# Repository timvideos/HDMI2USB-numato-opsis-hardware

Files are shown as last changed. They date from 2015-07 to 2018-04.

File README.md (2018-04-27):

The <a href="http://hdmi2usb.tv/numato-opsis">Numato Opsis</a>, the first open hardware for the
<a href="http://hdmi2usb.tv">HDMI2USB firmware</a>,
<a href="https://numato.com/product/numato-opsis-fpga-based-open-video-platform">can now be ordered
From Numato Labs
</a>

## Opsis Board - A open source HDMI2USB board

The [Numato](http://numato.com) Opsis board is the first
[HDMI2USB](http://hdmi2usb.tv) production board developed in conjugation with
the [TimVideos.us](http://code.timvideos.us) project. 

It's features include;
 * 2 x HDMI input ports,
 * 2 x HDMI output ports,
 * DisplayPort input and output ports,
 * 128Mbit DDR3-1600 ram,
 * Gigabit Ethernet with MAC address EEPROM,
 * Micro SD card,
 * Cypress FX2 for USB device functionality,
 * ULPI for USB OTG functionality,
 * Quad speed SPI flash.

Sample code for the Opsis can be found at https://github.com/timvideos/HDMI2USB-numato-opsis-sample-code

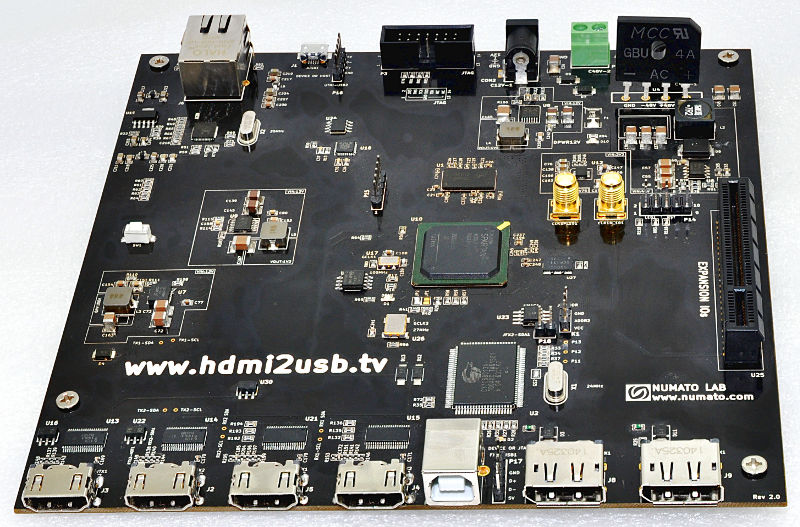
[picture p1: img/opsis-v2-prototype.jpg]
Opsis V2 Prototype Picture


## Editing

The design in this repository was made using [KiCad](http://www.kicad-pcb.org/)
version **2013-07-07 BZR 4022**
([the version in Ubuntu Trusty](http://packages.ubuntu.com/trusty/kicad)).

## License

Opsis Board by Numato Systems Pvt. Ltd

The Numato HDMI2USB board is licensed under a
Creative Commons Attribution-ShareAlike 4.0 International License.

You should have received a copy of the license along with this
work. If not, see <http://creativecommons.org/licenses/by-sa/4.0/>.



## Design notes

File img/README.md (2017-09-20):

This directory is only for images needed for this repo.

Detailed pictures of the Opsis board can be found in the [Opsis Developer Documentation](https://opsis.hdmi2usb.tv) the source of these images can be found in the [GitHub Repo for the Developer Docs](https://github.com/timvideos/HDMI2USB-numato-opsis-docs/tree/master/img).

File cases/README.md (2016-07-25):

This directory contains designs for mounting the Numato Opsis in cases.

This git repository is the master but the designs can also be found on
[Thingiverse](http://www.thingiverse.com/groups/timvideos/things).

 * `layout` - Designs showing the port size and locations to enable easy case construction.
 * `layout/front.svg` - Front of the board containing the HDMI, USB-B and DisplayPort connectors.
 * (TODO) `layout/back.svg` - Back of the board containing the Ethernet, Micro USB and power connectors.
 * (TODO) `layout/side.svg` - Side of the board containing the MicroSD slot.

 * `io-shield` - IO shields designed to fit ready made cases.

 * `io-shield/atx` - Fits an standard ATX case.

 * `io-shield/inset-thin` - Fits the
   [Inset Technologies "Thin Mini-ITX Computer Case"](http://amzn.to/1Okez89)
   when used with
   [#6-32 to M3 Metal Standoffs](http://amzn.to/2anqXwz).

 * `(.*)-mouse-ears.stl` - Same as `\1.stl`, but with 'mouse-ears' to aid 3d printing.

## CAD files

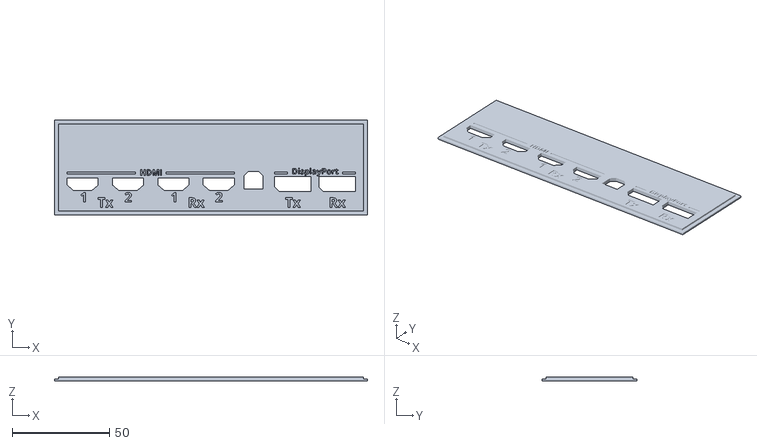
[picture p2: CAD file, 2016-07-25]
cases/io-shield/atx/atx.stl
161.0 x 49.0 x 2.00

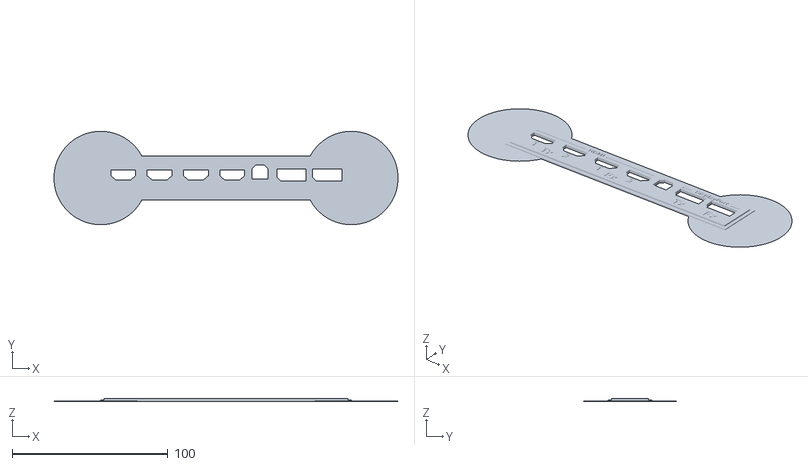
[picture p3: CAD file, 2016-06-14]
cases/io-shield/inset-thin/inset-thin-mouse-ears.stl
220.9 x 60.0 x 2.00

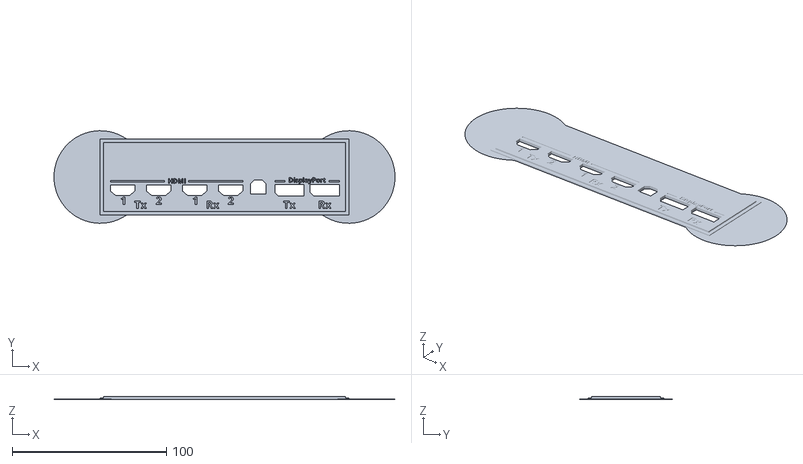
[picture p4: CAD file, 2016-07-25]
cases/io-shield/atx/atx-mouse-ears.stl
220.9 x 60.0 x 2.00

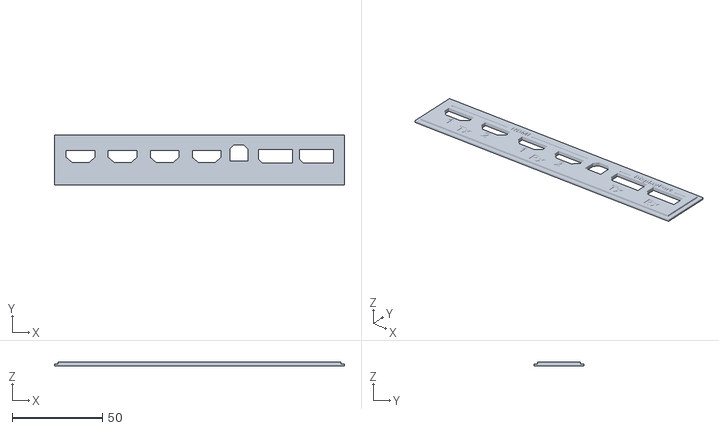
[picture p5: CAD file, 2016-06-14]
cases/io-shield/inset-thin/inset-thin.stl
161.0 x 28.0 x 2.00

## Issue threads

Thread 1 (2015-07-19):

Create code for the FX2 to act as a USB-UART

mithro, 2015-07-19:
_From @mithro on July 17, 2015 7:30_

The FX2 should be loadable with firmware which makes it appear like a CDC-ACM serial port and is connected to the FPGA.

The FX2 has its two hardware UARTs connected to the FPGA;
 * Two hardware UARTs
   * Port 0
     * RX - Cypress (Pin 41) -> FPGA (Pin **P18** / IO_L71N_1)      -- Incorrectly labeled CY_RXD1
     * TX - FPGA (Pin **T17** / IO_L72N_1) -> Cypress (Pin 40)      -- Incorrectly labeled CY_TXD1
   * Port 1
     * RX - Cypress (Pin 43) -> FPGA (Pin **P17** / IO_L71P_1)      -- Incorrectly labeled CY_RXD0
     * TX - FPGA (Pin **R17** / IO_L72P_1) -> Cypress (Pin 42)      -- Incorrectly labeled CY_TXD0

_Copied from original issue: mithro/numato-opsis-sample-code#1_

mithro, 2015-07-19:
https://github.com/timvideos/HDMI2USB-numato-opsis-sample-code/issues/1

Closed 2015-07-19.

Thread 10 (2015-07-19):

PCB text should use hdmi2usb.tv rather than www.hdmi2usb.tv

mithro, 2015-07-19:
Ported from http://redmine.numato.in/issues/1850

Closed 2015-08-26.

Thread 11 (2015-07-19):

Silkscreen for P15 should include information about each pin

mithro, 2015-07-19:
Pin 1 - VCC3V3
Pin 2 - VCC1V5
Pin 3 - IO 0
Pin 4 - IO 1
Pin 5 - GND

Ported from http://redmine.numato.in/issues/1988

Closed 2015-08-26.

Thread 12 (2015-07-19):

VTTREF0 and VTTREF not connected

mithro, 2015-07-19:
This is caused because we ended up with two nets, VTTREF0 and VVTREF, hence the check in the PCB didn't show they where connected.

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

Ported from http://redmine.numato.in/issues/1960

mithro, 2015-08-26:
This has been fixed in the schematic. Needs to also be fixed in the PCB.

anoopnumato, 2015-09-15:
Kindly check the latest files

mithro, 2015-09-20:
LGTM.

Closed 2015-09-20.

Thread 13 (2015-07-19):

CY_RX0/CY_RX1 and CY_TX1/CY_TX0 labels are swapped in schematic

mithro, 2015-07-19:
This is just a labeling issue, and not a real issue.

See the screenshot.
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

Ported from http://redmine.numato.in/issues/1959

Closed 2015-08-26.

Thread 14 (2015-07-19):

Add an ATX compatible power supply header

mithro, 2015-07-19:
Options are;

 * 24-pin ATX12V 2.x power supply connector
 * 4-pin "Molex connector" — transferred directly from AT standard: +5 V and +12 V for P-ATA hard disks, CD-ROMs, 5.25 inch floppy drives and other peripherals.
 * PCI-Express 12V adapter.

https://en.wikipedia.org/wiki/ATX

Ported from http://redmine.numato.in/issues/1979

anoopnumato, 2015-09-15:
Updated the files

mithro, 2015-09-20:
It appears we went with a PCI-Express 12V connector?

Is there space to add a 4-pin Molex too?

mithro, 2015-10-01:
Poke?

anoopnumato, 2015-10-05:
@mithro All the latest SMPS power supply comes with PCI express connector. I do not think the 4 pin Molex connector is necessary.

mithro, 2015-10-05:
Okay
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

mithro, 2015-10-06:
Closing based on @anoopnumato's comments.

Closed 2015-10-06.

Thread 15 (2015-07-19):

Document the Cypress FX2 reset functionality

mithro, 2015-07-19:
Please verify the following;

#### Test 0 - Device doesn't enumerate without board power

Computer is connected to the Cypress FX2 while board is unpowered.

**No device should be enumerated / discovered.**

####  Test 1 - FX2 enumerates while board unconfigured.

EEPROM contents should be empty.
FPGA SPI contents should be empty.
Jumper P18 should be connected.
Board should be powered on.
Computer connected to the Cypress FX2.

**Device should enumerate as an "Unconfigured Cypress FX2 device".**

####  Test 2 - FX2 enumerates from EEPROM with unconfigured FPGA

The EEPROM should be programmed with the following data;
<pre>
c0 50 1d b5 60 01 00 01
</pre>
FPGA SPI contents should be empty.
Jumper P18 should be connected.
Board should be powered on.
Computer connected to the Cypress FX2.

**Device should enumerate with VID:0x1d50 PID:0x60b5**

####  Test 3 - FX2 enumerates when EEPROM disconnected

The EEPROM should be programmed with the following data;
<pre>
c0 50 1d b5 60 01 00 01
</pre>
FPGA SPI contents should be empty.
Jumper P18 should be **disconnected**.
Board should be powered on.
Computer connected to the Cypress FX2.

**Device should enumerate as an "Unconfigured Cypress FX2 device".**

####  Test 4 - FX2 enumerates with firmware overridden by FPGA

The EEPROM should be programmed with the following data;
<pre>
c0 50 1d b5 60 01 00 01
</pre>
FPGA SPI should be programmed with the "hdmi2usb-cypress-fx2-boot-test.bit" file.
Jumper P18 should be connected.
Board should be powered on.
Computer is then connected to the Cypress FX2.

**Device should enumerate with VID:0x1d50 PID:0x60b6**

(Note PID is 0x60b **6** and not 0x60b **5**)

--

Ported from http://redmine.numato.in/issues/1852

mithro, 2015-09-20:
I was able to get "Test 2 - FX2 enumerates from EEPROM with unconfigured FPGA" to work.

I did this with in circuit programming via;

 * Downloading http://www.triplespark.net/elec/periph/USB-FX2/eeprom/fxload-full-2008_10_13-ww3.tar.gz
 * Modifying the lines around 711 and 729, replacing `first_byte = 0xC2;` with `first_byte = 0xC0;`
 * Building by typing `make`
 * Creating output.hex with the following contents;
```
:00000001FF
```
 * Running the command `sudo ./fxload -v -t fx2lp -D /dev/bus/usb/003/029 -s ./Vend_Ax.hex -d 1d50:60b5 -c 0x01 -I output.hex`

  (/dev/bus/usb/XXX/XXX can be found via lsusb)

 * Rebooting the device.

mithro, 2015-10-01:
This has been verified by me but I need to write up some good instructions.

Closed 2015-10-18.

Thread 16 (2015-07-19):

Issues with low speed signal lines HDMI signal

mithro, 2015-07-19:
The HDMI RX ports have a 15k resistor pulling them down and a 1k resistor pulling them up!?

mithro, 2015-08-14:
From Anoop,

> The changes made on the hardware is
> R151,R204(15K) removed, R141,R142,R197,R196 vale
> changed from 1.5K to 49K.

mithro, 2015-08-26:
I have applied @anoopnumato 's changes to the schematic. They still need to be applied to the PCB.

mithro, 2015-09-20:
@anoopnumato - Please confirm these changes have been made?

mithro, 2015-10-01:
@anoopnumato - Poke?

mithro, 2015-10-21:
@anoopnumato There still seem to be 1.5k resistors on the HDMI Outputs. Do these need changing too?

anoopnumato, 2015-10-21:
Only changes in HDMI IN

Closed 2015-10-28.

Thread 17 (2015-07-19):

HPD and CEC lines should have test points

mithro, 2015-07-19:
All the HPD and CEC signals should have test points on them like the SCL and SDA lines.

mithro, 2015-08-26:
I have added the test points in the schematic. They still need to be added in the PCB.

Closed 2015-09-20.

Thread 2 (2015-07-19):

Get memory working with misoc

mithro, 2015-07-19:
_From @mithro on July 17, 2015 7:38_

misoc currently doesn't support DDR3 with the Spartan-6. Need to extend the support to include DDR3 and then get working on the Opsis.

_Copied from original issue: mithro/numato-opsis-sample-code#2_

Closed 2015-07-19.

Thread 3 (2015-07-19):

Generate an example using the MCB for memory

mithro, 2015-07-19:
_From @mithro on July 17, 2015 7:38_

_Copied from original issue: mithro/numato-opsis-sample-code#3_

Closed 2015-07-19.

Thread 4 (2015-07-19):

Commit EDK example performing the memory test.

mithro, 2015-07-19:
_From @mithro on July 17, 2015 7:39_

 * http://redmine.numato.in/issues/1955

_Copied from original issue: mithro/numato-opsis-sample-code#4_

Closed 2015-07-19.

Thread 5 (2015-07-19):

Commit EDK example using the Gigabit Ethernet

mithro, 2015-07-19:
_From @mithro on July 17, 2015 7:46_

http://redmine.numato.in/issues/1857

_Copied from original issue: mithro/numato-opsis-sample-code#5_

Closed 2015-07-19.

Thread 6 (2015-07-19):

Get the Ethernet working with misoc

mithro, 2015-07-19:
_From @mithro on July 17, 2015 7:48_

The Ethernet uses the RGMII interface. LiteEth in misoc currently doesn't support RGMII interfaces - see https://github.com/m-labs/misoc/issues/5 for more information.

Hence;
 - [ ] Add support to RGMII to LiteEth
 - [ ] Get it working with the opsis board

_Copied from original issue: mithro/numato-opsis-sample-code#6_

mithro, 2015-07-19:
A quick work around might be to use an existing RGMII to GMII interface converter.

Closed 2015-07-19.

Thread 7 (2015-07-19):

Get the hamsterworks minimal-dvi-d working on Opsis board

mithro, 2015-07-19:
_From @mithro on July 17, 2015 8:0_

_Copied from original issue: mithro/numato-opsis-sample-code#19_

Closed 2015-07-19.

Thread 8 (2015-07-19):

Cypress FX2 reset functionality needs fixing

mithro, 2015-07-19:
The Cypress FX2 to used for JTAG programming of the FPGA, so it needs to come up no matter what the FPGA is currently programmed with. Currently if the FPGA doesn't pull Cypress-RST net high or float the FX2 won't boot.

mithro, 2015-07-19:
From Anoop;

> The diode direction(D12,D13 should be reverse for providing external RESET( Need to change in the schematic).
> Cypress is enumerating if the FPGA is in not configured condition ie., by default FPGA IOs will be weak pull up enabled condition( This is due to HSWAP pin state).
> After configuring IO state will go low to avoid we should PULLUP the Cypress RESET pin in the UCF.

mithro, 2015-07-19:
The desired behaviour is the following;

 * Shorting the reset switch caused both the FX2 and the FPGA to undergo a reset.

 * The FPGA is able to cause the FX2 to reset by toggling the IO pin connected to Cypress reset line.

 * The FX2 will boot after a "fail safe delay" no matter the state of the FPGA. IE Even if the FPGA is actively pulling the line low.

As most people will be using the FX2 as a JTAG usb programmer, it is important that even if the SPI flash is loaded with bitstream that constantly pulls the Cypress RESET line permanently low, the FX2 will eventually boot in unconfigured mode.

mithro, 2015-07-19:
We should also add a jumper which lets this line be totally disconnected.

mithro, 2015-08-04:
https://github.com/timvideos/HDMI2USB-numato-opsis-hardware/issues/15

mithro, 2015-08-11:
At the moment, the FX2 should come up as an unconfigured Cypress FX2 **but only if the FPGA is correctly configured**.

Pin G22 (the Cypress Reset line) must be pulled high or left floating.

For the moment we set all the unused pins to be floating - see https://github.com/timvideos/HDMI2USB-misoc-firmware/blob/opsis/platforms/opsis.py#L444

mithro, 2015-10-18:
A friend suggested the following circuits;

<blockquote>
from left to right - differentiator, (inverse) peak detector, ac coupler.
I think you'll need to play with the values a bit to get the right
timing and peak size.
</blockquote>

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

`reset.asc` (ltspice file)
```
Version 4
SHEET 1 1120 680
WIRE 784 -80 720 -80
WIRE 816 -80 784 -80
WIRE 928 -80 896 -80
WIRE 80 64 80 32
WIRE 160 64 80 64
WIRE 288 64 224 64
WIRE 368 64 288 64
WIRE 496 64 432 64
WIRE 640 64 496 64
WIRE 672 64 640 64
WIRE 784 64 784 -80
WIRE 784 64 736 64
WIRE 784 112 784 64
WIRE 80 128 80 64
WIRE 288 128 288 64
WIRE 640 128 640 64
WIRE 928 128 928 -80
WIRE 496 144 496 64
WIRE 80 256 80 208
WIRE 288 256 288 208
WIRE 288 256 80 256
WIRE 496 256 496 208
WIRE 496 256 288 256
WIRE 640 256 640 208
WIRE 640 256 496 256
WIRE 784 256 784 192
WIRE 784 256 640 256
WIRE 928 256 928 208
WIRE 928 256 784 256
WIRE 80 304 80 256
FLAG 80 304 0
FLAG 80 32 FPGA
FLAG 720 -80 RST
SYMBOL voltage 80 112 R0
WINDOW 3 -413 53 Left 2
WINDOW 123 0 0 Left 2
WINDOW 39 0 0 Left 2
SYMATTR InstName V1
SYMATTR Value PULSE(3.3 0 20m 1u 1u 30m 50m)
SYMBOL res 272 112 R0
SYMATTR InstName R1
SYMATTR Value 1k
SYMBOL cap 160 80 R270
WINDOW 0 32 32 VTop 2
WINDOW 3 0 32 VBottom 2
SYMATTR InstName C1
SYMATTR Value 10µ
SYMBOL diode 432 48 R90
WINDOW 0 0 32 VBottom 2
WINDOW 3 32 32 VTop 2
SYMATTR InstName D1
SYMATTR Value 1N4148
SYMBOL cap 480 144 R0
SYMATTR InstName C2
SYMATTR Value 10p
SYMBOL res 624 112 R0
SYMATTR InstName R2
SYMATTR Value 100k
SYMBOL voltage 928 112 R0
WINDOW 123 0 0 Left 2
WINDOW 39 0 0 Left 2
SYMATTR InstName V2
SYMATTR Value 3.3
SYMBOL res 768 96 R0
SYMATTR InstName R3
SYMATTR Value 100k
SYMBOL res 800 -64 R270
WINDOW 0 32 56 VTop 2
WINDOW 3 0 56 VBottom 2
SYMATTR InstName R4
SYMATTR Value 10k
SYMBOL cap 672 80 R270
WINDOW 0 32 32 VTop 2
WINDOW 3 0 32 VBottom 2
SYMATTR InstName C3
SYMATTR Value 1µ
TEXT -146 328 Left 2 !.tran 200m
```

tim.asc (ltspice file)
```
Version 4
SHEET 1 1228 680
WIRE 96 0 0 0
WIRE 96 32 96 0
WIRE 384 64 368 64
WIRE 480 64 464 64
WIRE 0 112 0 0
WIRE 96 176 96 112
WIRE 192 176 96 176
WIRE 272 176 272 128
WIRE 272 176 192 176
WIRE 336 176 272 176
WIRE 368 176 368 64
WIRE 368 176 336 176
WIRE 384 176 368 176
WIRE 480 176 480 64
WIRE 480 176 448 176
WIRE 544 176 480 176
WIRE 720 176 720 128
WIRE 720 176 544 176
WIRE 96 192 96 176
WIRE 192 192 192 176
WIRE 336 192 336 176
WIRE 544 208 544 176
WIRE 720 208 720 176
WIRE 0 304 0 192
WIRE 96 304 96 272
WIRE 96 304 0 304
WIRE 192 304 192 256
WIRE 192 304 96 304
WIRE 336 304 336 256
WIRE 336 304 192 304
WIRE 544 304 544 288
WIRE 544 304 336 304
WIRE 720 304 720 288
WIRE 720 304 544 304
WIRE 720 336 720 304
FLAG 720 336 0
FLAG 720 128 FPGA
FLAG 272 128 RST
SYMBOL voltage 0 96 R0
WINDOW 123 0 0 Left 2
WINDOW 39 0 0 Left 2
SYMATTR InstName V1
SYMATTR Value 4.7
SYMBOL res 80 16 R0
SYMATTR InstName R1
SYMATTR Value 1k
SYMBOL res 80 176 R0
SYMATTR InstName R2
SYMATTR Value 1000k
SYMBOL res 528 192 R0
SYMATTR InstName R3
SYMATTR Value 1k
SYMBOL voltage 720 192 R0
WINDOW 123 0 0 Left 2
WINDOW 39 0 0 Left 2
SYMATTR InstName V2
SYMATTR Value PULSE(4.7 0 20m 1u 1u 15m 50m 100)
SYMBOL cap 384 192 R270
WINDOW 0 32 32 VTop 2
WINDOW 3 0 32 VBottom 2
SYMATTR InstName C1
SYMATTR Value 4.7µ
SYMBOL res 368 80 R270
WINDOW 0 32 56 VTop 2
WINDOW 3 0 56 VBottom 2
SYMATTR InstName R4
SYMATTR Value 10k
SYMBOL cap 176 192 R0
SYMATTR InstName C2
SYMATTR Value 1p
SYMBOL zener 352 256 R180
WINDOW 0 24 64 Left 2
WINDOW 3 24 0 Left 2
SYMATTR InstName D1
SYMATTR Value 1N750
TEXT -34 360 Left 2 !.tran 200ms
```

mithro, 2015-11-03:
The specification for this circuit is;
 * No matter the FPGA I/O pin state (high, low, high impedance or any voltage in between) - the Cypress RST pin *must* go high (2.0V), after at least 10 milliseconds, but no more than 250 milliseconds.
 * Pulling the FPGA I/O pin low should cause the Cypress pin to go low (below 0.8V) for 200 microseconds.

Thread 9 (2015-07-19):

DisplayPort lanes need DC-blocking (AC coupling) capacitors

mithro, 2015-07-19:
The DisplayPort lanes and aux channel should have ~0.1uF (100nF) DC blocking capacitors between the connector and the FPGA.

The AC coupling capacitor must be in the range of 75 nF to 200 nF. A value of 100 nF is recommended. These capacitors also need to be as physically small as possible, a package size of 0201 is recommended but a 0402 is acceptable. They should be placed at the same length from the FPGA/connector.

Ported from http://redmine.numato.in/issues/1950

mithro, 2015-07-19:
The capacitors where added to the schematic in 4ada452b0a6dd5e9f09a80e1f66faf846f8c2c75

mithro, 2015-08-18:
Here are a couple of designs which have the correct DC blocking capacitors;

* Atrix-7 based device; 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

* Cyclone-V based device using a TI redriver;
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

The FPGA does have built-in AC coupling in the receiver, however the design guide recommends using external AC coupling for DisplayPort. See the following picture;
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

mithro, 2015-08-18:
From @anoopnumato
> Is it really necessary to cut the traces and add the dc blocking capacitors on this board? Can you test current prototype without these Capacitors?

Missing the DC blocking capacitors will degrade performance, but I'm uncertain by how much (and believe it really depends on what the system is connected too). Using the internal AC coupling might (but also might not) be enough that performance is still okay for doing initial testing.

Cutting the traces and adding the capacitors can also reduce performance because the matching and grounding is no longer correct.

mithro, 2015-08-18:
From @anoopnumato
> We have tested GTP of SPN602 with out these capacitors on its reference clock and we are able verify the speed up to 3Gbs using chipscope pro.

anoopnumato, 2015-09-15:
Updated the files.

mithro, 2015-09-20:
Looks good.

Closed 2015-09-20.

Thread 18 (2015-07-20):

Add mounting holes for expansion boards when using a right-angle riser.

mithro, 2015-07-20:
All expansion boards should follow the PCI-Express mechanical standard so they can be mounted in ITX style cases using standard risers.

However when not using a case, it would be good to allow the expansion boards to be securely attached to the motherboard. This can be done with a standard right angle connector (such as http://www.amazon.com/gp/product/B00KZIAHW8) and some extra mounting holes in the motherboard.

mithro, 2015-10-10:
See the following two pictures
 * https://drive.google.com/file/d/0B5VlNZ_Rvdw6WVNSQkxoLVhRam8/view?usp=sharing
 * https://drive.google.com/file/d/0B5VlNZ_Rvdw6TWxhWnBKeF9sU0k/view?usp=sharing

anoopnumato, 2015-10-16:
@mithro It will be difficult to add , required much re-routing .

mithro, 2015-10-17:
@anoopnumato Please provide mechanical diagrams showing the issues. There is plenty of empty space on the Opsis were we can put standoff holes.

We control the TOFE specification, so we can put the standoff holes anywhere.

mithro, 2015-10-21:
@anoopnumato Why did you assign this back to me? Did you see my last comment?

mithro, 2015-11-02:
@anoopnumato is going to;

 * upload a couple of mechanical diagrams.
 * make sure their are suitable mounting holes for half-height cards.
 * (maybe) add the following (optional) mounting holes

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

Closed 2015-11-03.

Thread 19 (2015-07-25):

Common pin of the 5V power regulators for HDMI output are not connected to ground.

mithro, 2015-07-25:
The ΜA78L00 used to create the 5V power supply for the HDMI connectors does not have the common pin connected to ground.

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

mithro, 2015-08-04:
Pictures of two fix ups needed. (A third one is also needed but I don't have a picture of that.)

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

mithro, 2015-08-26:
I have fixed this issue in the schematic. It still needs to be fixed in the PCB.

mithro, 2015-09-20:
Looks to be fixed.

Closed 2015-09-20.

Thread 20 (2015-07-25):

What is R99 and why is it unpopulated / unknown.

mithro, 2015-07-25:
It seems to be connected to Pin 22 (RF) of the TPS53319 power supply.

anoopnumato, 2015-09-09:
RF resister is used for selecting switching frequency of TPS53319,  If we left open this pin, the switching frequency will be 500Khz.

mithro, 2015-09-09:
Can we get that marked in the schematic as such?

anoopnumato, 2015-09-09:
Ok. We can add.

mithro, 2015-09-20:
LGTM.

Closed 2015-09-20.

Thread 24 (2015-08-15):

Feature: VGA-in

tillsteinbach, 2015-08-15:
This is probably more a feature request for a future version:
Lots of speakers still expect a VGA display. So it would be great to still have one (additional) VGA input.

mithro, 2015-08-16:
@tillsteinbach We already have an expansion board for the Digilent Atlys board (our old prototyping board) that does VGA. You can see it at https://github.com/timvideos/HDMI2USB-vmodvga

This board was made by @rohit91 as part of Google Summer of Code. You can see his work at http://dreamsxtrinsic.blogspot.de/2014/08/gsoc-project-report-vga-capture.html

It would be pretty simple to port this board to the PCI-Express interface used by the Numato Opsis board but I don't think @rohit91 has any time to do that.

tillsteinbach, 2015-08-17:
Ahh! Nice, thanks for letting me know!

sealne, 2015-10-16:
I plan to work on converting the layout to TOFE while Rohit plans to focus on getting it to work with the new misoc based firmware

mithro, 2015-10-17:
@sealne and @rohit91 are working on this! Yay!

mithro, 2015-10-24:
https://github.com/timvideos/HDMI2USB-misoc-firmware/issues/30

mithro, 2015-10-24:
FYI There is now a TOFE template available for KiCad at https://github.com/timvideos/HDMI2USB-TOFE-kicad-template

mithro, 2015-11-03:
I'm closing this issue as the project has it's own repo now.

Closed 2015-11-03.

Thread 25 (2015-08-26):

DisplayPort lanes on the sink are incorrect

mithro, 2015-08-26:
Compare 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 to
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

mithro, 2015-08-26:
Potential fix? - http://www.xilinx.com/support/documentation/application_notes/xapp491.pdf

enjoy-digital, 2015-08-26:
http://www.xilinx.com/support/documentation/user_guides/ug386.pdf

"If the TXP/TXN differential traces are swapped on a board, tie TXPOLARITY High"
and
"If the polarity of RXP/RXN needs to be inverted, RXPOLARITY must be tied High"

So it should be OK.

mithro, 2015-08-31:
FYI - @anoopnumato @numato

mithro, 2015-11-02:
@anoopnumato has fixed this.

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

mithro, 2016-01-04:
With a standard DisplayPort cable;

GTPA1_DUAL_X0Y0_0(TX) goes to GTPA1_DUAL_X1Y0_1(RX)
GTPA1_DUAL_X0Y0_1(TX) goes to GTPA1_DUAL_X1Y0_0(RX)
GTPA1_DUAL_X1Y0_0(TX) goes to GTPA1_DUAL_X0Y0_1(RX)
GTPA1_DUAL_X1Y0_1(TX) goes to GTPA1_DUAL_X0Y0_0(RX)

Closed 2015-11-02.

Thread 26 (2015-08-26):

PCB should have git revision number embedded in it

mithro, 2015-08-26:

mithro, 2015-10-18:
Please provide a large space on the board with space for text like `v0.0.0-429-ged90ee1`. Put a placeholder text like `$GIT_REVISION_GOES_HERE`.

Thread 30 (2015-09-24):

Create a KiCad template for TOFE expansion boards

mithro, 2015-09-24:
We need a template which has the following things;

 * The TOFE connector part in schematic form.
 * Example PCB which includes;
  * The PCB fingers.
  * The mechanical size for "full size PCI-Express card"
  * The mechanical size for "half size PCI-Express card"
  * Keep out zones.
  * Mounting holes.

See https://github.com/mithro/kicad-mini-pci-express for an example I did for mini-pci-express.

Useful information;
 * http://read.pudn.com/downloads166/ebook/758109/PCI_Express_CEM_1.1.pdf (see `6. Add-in Card Form Factors and Implementation`)
 * http://pcisig.com/specifications/pciexpress/base
 * http://www.interfacebus.com/PCIe_Card_Dimensions.html

We can then add some extra tools like;

 * The required EEPROM parts + tool to generate the EEPROM contents.

anoopnumato, 2015-10-16:
@mithro Please verify the files shared and close the issue

mithro, 2015-10-17:
The TOFE template is available at https://github.com/timvideos/HDMI2USB-TOFE-kicad-template
Any issues with the template should be logged in that repository.

Closing.

Closed 2015-10-17.

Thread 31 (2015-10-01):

Mini-ITX case alignment issue for I/O shield

mithro, 2015-10-01:
The board has an alignment issue when amounted in an Mini-ITX case the I/O ports don't correctly line up with the I/O shield area.

mithro, 2015-10-01:
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

mithro, 2015-10-01:
It appears we have some type of alignment issue with our board. The DisplayPort connector on the far right is too close to the edge and there seems to be some type of gap on the left side. I see the same issue with the board in the case I got.

@anoopnumato , can you please verify the board is matching the MiniITX / ATX standard for the hole and connector positions? It kind of looks like the board should be shifted 5mm to the right?

anoopnumato, 2015-10-01:
@mithro As per the Mini-iTX spec. required spacing of the IO connector side is 6.35mm(page 9), in the attached image of Numato Opsis it was 7.2 mm.
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
http://www.formfactors.org/developer%5Cspecs%5CMini_ITX_Spec_V2_0.pdf

anoopnumato, 2015-10-01:
@mithro Seems it requires 7.52 and we have 7.32!

mithro, 2015-10-01:
What are your suggestions for fixing?
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

anoopnumato, 2015-10-01:
Option one is change the display port TX and RX connectors clearance 3 mm instead of 5 mm.

mithro, 2015-10-04:
My recommendation is that we do the following;
 * Move P17 around the corner so it is between the USB connector and the Cypress FX2
 * Move DisplayPort TX left a bit.
 * Move DisplayPort RX closer to DisplayPort TX.

Is that doable?

Why is there a gap on between the side of the board and the left most edge of the board? Can you please recheck all the following too:
 * The hole positioning
 * The expansion header positioning

mithro, 2015-10-21:
Distance was changed to ~13mm between connector edge and hole center.

Closed 2015-10-21.

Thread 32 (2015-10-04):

Make the EEPROM write protected by default (with a jumper to enable writing)

mithro, 2015-10-04:
The EEPROM should be write protected most of the time.

We will load the EEPROM with fallback boot configuration for the Cypress FX2 and details about the board (the PCB revision, the manufacture batch / date, etc). This shouldn't be easy to accidently overwrite.

Fix:
 * Put a pull up resistor on Pin 7 of U23 (the MAC EEPROM).
 * Put a header connected to Pin 7 which can be shorted to pull the pin to ground (temporarily overpowering the pull up resistor) thus enabling writing to the EEPROM.

Closed 2015-10-21.

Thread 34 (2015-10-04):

Add a jumper between RESET# pin and the FPGA pin G22

mithro, 2015-10-04:
This should allow the Cypress FX2 pin to be totally disconnected from the FPGA.

This header should be labelled `JFX2-RST` / `P??` - please reply with the P number once it has been annotated in the schematic.

Closed 2015-10-21.

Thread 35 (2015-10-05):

Add a header to the SD card pins

mithro, 2015-10-05:
We don't have any location for interfacing at 3V3 level. Both @enjoy-digital and @hamsternz found that the MicroSD connector was useful for that.

We should add a header to make that easy. It will also allow people to probe the signals to the SD card when playing with that feature.

mithro, 2015-10-21:
Can you please update the schematic to look like the following
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

Please also add a VCC3V3 and GND pins to the header.

anoopnumato, 2015-11-02:
Solved

Closed 2015-11-02.

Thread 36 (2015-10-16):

Numbering of HDMI ports on silkscreen different from in lm32

sealne, 2015-10-16:
The silkscreen on the PCB labels the HDMI inputs and outputs as 1 and 2 while in the configuration program on the lm32 they are referred to as 0 and 1

mithro, 2015-10-17:
I'm moving this issue to the misoc firmware.

Closed 2015-10-17.

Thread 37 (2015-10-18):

Noise on DisplayPort high speed lines when using the AUX connector

mithro, 2015-10-18:
When Mike tries to use the AUX channel on the DisplayPort connector, it causes the high speed link to drop. We are currently investigating;

From Mike;
<blockquote>
Whenever the link is up and stable:

* If I leave the AUX channel tri-stated then the link stays up.

* if I waggle the AUX channel to ask the sink for it's status I get the main links drop,

* There is high frequency 'noise' on the AUX channel when tristated

* If I drive the AUX channel to 0 or 1 when idle the link doesn't come up.
</blockquote>

This is quite probably a side effect of https://github.com/timvideos/HDMI2USB-numato-opsis-hardware/issues/9 -- but we need to confirm.

mithro, 2015-10-18:
@hamsternz said;
<blockquote>
Tested for a short with a scope and couldn't see anything (watched the lanes while AUX EDID probes were going on).
</blockquote>

mithro, 2015-10-18:
As the repository has moved forward, I've uploaded an older version of the schematic for the preproduction boards at https://github.com/timvideos/HDMI2USB-numato-opsis-docs/blob/gh-pages/pdfs/NumatoOpsis-schematic-v2-prototype-13-gb1c4312.pdf

mithro, 2015-10-18:
Oh wait, that version is still too new. It has the decoupling capacitors. Will need to go back further.

hamsternz, 2015-10-18:
Here's the change H/W 8b/10b makes in resource usage.

Single channel 800x600 colourbars
            H/W   S/W
Registers  724   878
LUTS       882  1397
Occupied   295   552

Four channels 800x600 white
            H/W   S/W
Registers  820   975  -16%
LUTS       940  1473  -36%
Occupied   320   562  -43%

It is all checked in now, and It should be all good for you to pull it.

Mike

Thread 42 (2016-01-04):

Issue with clock labelling

mithro, 2016-01-04:
The following issues exist with the clock labeling in the schematic;

 * U17 was labelled as 135MHz when it is a 100MHz device.
 * U17 was labelled as GCLK1 when it is connected to GCLK0
 * U17 net is called "USRCLK"

 * U26 was labelled as GCLK2 when it is connected to GCLK6

Closed 2016-03-21.

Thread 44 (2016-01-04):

Rename files from HDMI2USB to Opsis

mithro, 2016-01-04:
The files are currently named like follows;
```
$ ls *HDMI2USB* -l
-rw-r----- 1 mithro mithro 5577177 Oct  4 00:18 _autosave-HDMI2USB.kicad_pcb
-rw-r----- 1 mithro mithro   28585 Jan  4 15:01 HDMI2USB.bak
-rw-r----- 1 mithro mithro   62815 Jan  4 15:07 HDMI2USB-cache.lib
-rw-r----- 1 mithro mithro   61095 Nov 10 23:48 HDMI2USB.cmp
-rw-r----- 1 mithro mithro    6448 Jul 23 22:17 HDMI2USB.csv
-rw-r----- 1 mithro mithro 6247158 Jan  4 15:20 HDMI2USB.kicad_pcb
-rw-r----- 1 mithro mithro  307840 Jan  4 15:16 HDMI2USB.net
-rw-r----- 1 mithro mithro    1894 Jan  4 15:07 HDMI2USB.pro
-rw-r----- 1 mithro mithro    1596 Jan  4 15:07 HDMI2USB-rescue.lib
-rw-r----- 1 mithro mithro   29759 Jan  4 15:07 HDMI2USB.sch
-rw-r----- 1 mithro mithro  361855 Jan  4 15:16 HDMI2USB.xml
```

They really should be named Opsis.XXX -- IE Do a s/HDMI2USB/Opsis/ in the file names.

Should also fix the title and similar things in the file's actual content.

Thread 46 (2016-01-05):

Fix label of PCIe 12V connector

mithro, 2016-01-05:
Currently it is labelled "ATX_POWER_SUPPLY" which is kind of misleading.

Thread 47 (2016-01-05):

Pin 2 of PCIe connector should be NC

mithro, 2016-01-05:
This pin is currently connected to Pin 1 and Pin 3. Technically the specification says that this pin should be NC (but most supplies provide power here).

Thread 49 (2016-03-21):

Allow selection of the voltage level for the TOFE connector

mithro, 2016-03-21:
Currently the VCCIO for the bank connected to the TOFE connector is connected to VCC3V3. It would be nice if we could allow the TOFE connector to be supplied via the other VCC supplies (IE VCC1V5 and VCC1V2). Care would need to be taken to not adversely affect the parts already powered by these supplies.

The TOFE specification would need to be updated to include information about VCCIO stuff.

It would be best if the VCCIO voltage level was controllable / changeable via the FPGA itself. Otherwise a jumper would be another solution. In either case, it voltage level in use should be measurable / detectable via some means.

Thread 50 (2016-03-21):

Investigate compatibility issue with some HDMI devices

mithro, 2016-03-21:
TODO: @mithro to add a whole bunch more information here.

See the compatibility update in https://hdmi2usb.tv/crowdsupply/opsis/numato/2016/03/16/crowdsupply-updates-for-2016/

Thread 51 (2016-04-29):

how to purchase?

CarlFK, 2016-04-29:
https://hdmi2usb.tv/numato-opsis/  "Purchase a board from CrowdSupply or directly from Numato.com."

 I don't see how to purchase in either place

`Numato Opsis  No longer available`

mithro, 2016-05-03:
Here is a message from Numato Labs.

>On 3 May 2016 at 03:07, Numato Sales <sales@numato.com> wrote:
> >

---snip---

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

Closed 2016-05-03.

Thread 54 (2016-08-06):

Swap GND and VCC3V3 pins on the SDCard header - P28

mithro, 2016-08-06:
This would allow it to be connected to a half width PMOD device.

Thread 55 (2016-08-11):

Figure out possible back drive issue on HDMI inputs

mithro, 2016-08-11:
The red power LED stays on when power is disconnected but power supply disconnected.

Might only be on this one board - check d8:80:39:57:1b:d1

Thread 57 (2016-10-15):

Replace "PCIe" name in the schematic with "TOFE"

mithro, 2016-10-15:
The connector is PCIe style, but only supports TOFE boards.

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

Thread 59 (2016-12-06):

Confused about HDMI resolution

nesteruk, 2016-12-06:
When I watched the [interview](https://www.youtube.com/watch?v=b0JEVifDHQ0), you mention that HDMI only supports 720p. But on the [website](http://numato.com/numato-opsis-fpga-based-open-video-platform/), we see:

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

So which is it? 1080p or 720p?

mithro, 2016-12-06:
1080p normally means 1080p60 (1080p at 60 frames per second). The opsis is currently only capable of 1080p30 which while is the same resolution, is only half the frame rate.

There is a bunch more information at https://opsis.hdmi2usb.tv/info/video-info-faq.html

Does that help?

Does that help?

nesteruk, 2016-12-06:
@mithro Ahh, I get you, but I'm not sure why the FPS specification would be important -- the Opsis is positioned at an event recording/streaming device. We never do it at 60fps. I mean, typical video recording is done at 30fps, screens are recorded at 30fps _at most_ (and for coding, you don't need anything above 15fps), and certainly nobody would realistically be streaming at anything above 30fps. Am I missing something here?

mithro, 2016-12-06:
Many grumpy projectors out there only support 1080p60 and not 1080p30.

As well, if I brought a device which claimed to be "1080p" but is didnt support 1080p60, I would be pretty frustrated.

Lastly, we don't test with 1080p30 frequently (and support is not enabled by default) so it seems wrong to claim it out of the box.

mithro, 2016-12-06:
Oh, if it is not clear this is the maximum resolution that can be passed through the opsis. You can't use 1080p60 to your projector and capture at 1080p30.

mithro, 2016-12-06:
Btw You should come join us on IRC in the #timvideos channel on irc.freenode.net (web version at https://webchat.freenode.net/?channels=#timvideos ).

nesteruk, 2016-12-06:
Interesting. Did not that projectors can be that picky. That said, I've had _a ton_ of issues with projectors for the conferences we do. It's been a real pain because you rely on the venue to provide these.

Anyways, I think I'm going to go ahead and close this issue.

mithro, 2016-12-06:
@nesteruk - Please do email me at mithro@mithis.com! I would love to find out what you do, how you found out about the Opsis and how we might collaborate.

The TimVideos IRC channel also has a bunch of people from different open source groups who do conference recording and capture (PyCons, DebConfs, Chaos Club, etc). There is always a bunch of discussion about how to solve different problems, what hardware to use, etc. It is a great place to hang out if you care about this topic.

mithro, 2016-12-06:
(You can also find out about cool new things in development :-)

Closed 2016-12-06.

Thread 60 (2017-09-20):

pictures of the Opsis board

CarlFK, 2017-09-20:
This is not the same as the board I have:
https://github.com/timvideos/HDMI2USB-numato-opsis-hardware/blob/master/img/opsis-v2-prototype.jpg

2 threaded connectors, (composite?) different power connector

also add: top, bottom, all 4 sides.

mithro, 2017-09-20:
Pictures are at https://opsis.hdmi2usb.tv/getting-started/overview.html

mithro, 2017-09-20:
And https://opsis.hdmi2usb.tv/getting-started/layout.html

CarlFK, 2017-09-20:
reopening because the picture I referenced is still incorrect - note the file name is "prototype"
https://github.com/timvideos/HDMI2USB-numato-opsis-hardware/blob/master/img/opsis-v2-prototype.jpg

also  prototype:  https://opsis.hdmi2usb.tv/  https://opsis.hdmi2usb.tv/img/numato-opsis.jpg

If this isn't the place to find pictures, delete it the whole dir.
https://github.com/timvideos/HDMI2USB-numato-opsis-hardware/tree/master/img

There are no pictures/diagrams showing the orientation of the plugs.   Like is the rj45 release clip on the top or bottom?

the picture of the 6 pin power plug is hard to know how it is keyed.
https://opsis.hdmi2usb.tv/img/highlights/Jumpers.jpg

mithro, 2017-09-20:
https://github.com/timvideos/HDMI2USB-numato-opsis-docs/tree/master/img

CarlFK, 2017-09-20:
That is the Prototype. Or whatever it is, it does not show the Six pin
power connector.

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

mithro, 2017-09-20:
All the possible information you want on the power supply should be here -> https://opsis.hdmi2usb.tv/getting-started/power.html

Including details on the six pin connector keying.

CarlFK, 2017-09-20:
This bug report is about the picture(s) being incorrect.

There is also a bug report about connector docs, which I found confusing.   A picture of the production board might help.

CarlFK, 2017-09-21:
This bug report is about the picture(s) being incorrect.

There is also a bug report about connector docs, which I found confusing.   A picture of the production board might help.

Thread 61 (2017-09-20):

PCB cad as a png

CarlFK, 2017-09-20:
render the PCB cad file as a png to add to the photos of the board.

mostly I want to see part placement and labels.  Like I want to zoom in on the labels around the reset header.

I'll admit this seems like committing compiler artifacts, which need to be kept in sync, but given this is manufactured hardware in production it is different.

mithro, 2017-09-20:
I'm not sure what you are after here?

CarlFK, 2017-09-20:
in this image, some of the text is hard to read:
https://opsis.hdmi2usb.tv/img/highlights/Jumpers.jpg

I am assuming there are cad files and software that can render crisp lines and more detail.

CarlFK, 2017-09-21:
in this image, some of the text is hard to read:
https://opsis.hdmi2usb.tv/img/highlights/Jumpers.jpg

I am assuming there are cad files and software that can render crisp lines and more detail.

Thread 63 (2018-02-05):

Memory bandwidth for Opsis

Aregaard, 2018-02-05:
Hi again,
So lets assume a have a real time application 480p-1080p (video surveillance) and want to upscale (with Opsis) to 1920x1200 with Integer scaling (almost like Nearest neighbor).
This implies that I need approx. 9MB/frame in 60Hz. Which gives me a bandwidth need of 540MB/s.
According to your specs it has 256 MB RAM 1600MHZ (source: NumatoLab). According to me this will fulfill the requirements very well :).

 Will this fulfill the requirements?

Please explain how you do the math if I have miscalculated it.

Best Regards

mithro, 2018-02-05:
Hi @Aregaard -- These questions are probably better answered on the mailing list rather then via github issues. There is the [numato-opsis-discuss](https://groups.google.com/forum/#!forum/numato-opsis-discuss) and the [hdmi2usb list](https://groups.google.com/forum/#!forum/hdmi2usb) -- either would be perfectly fine for these types of questions.

Memory bandwidth is a complicated question. The theoretical top memory bandwidth of the Numato Opsis is `800e6 (800 MHz) * 2 (for DDR) * 16bit == 25600000000.0 bits/second or 25 gigabit/second`. However, you are very unlikely to get anywhere close to that *actual* performance due to overhead with accessing the DDR.

In practical terms, in the HDMI2USB-litex-firmware using LiteDRAM (which runs the memory at 400MHz rather then 800MHz) we are using 2 * 720p50 inputs + 1 * 720p50 output + 1 * 720p25 encoder bandwidth successfully on the Opsis. This means we are currently using,
`1280 * 720 * 16 (bits per pixel) * (3*50 + 1*30) == 2580480000 bits/second or 2.5 gigabits/second`
We believe we can increase that with optimisation but have not had the developer resources so far (one way would be running at 800MHz rather than 400MHz, another would be proper priority ordering of memory access and better caching).

Another FYI - In terms of upscaling, you can actually do that "just in time" (IE as you output the data) - so what you are after is actually 720p50 * 2 bandwidth (one for input, one for output) -- which we know the Opsis can do fine.

Lastly, getting the high speed DisplayPort interface going is a non-trivial challenge. The high speed transceivers inside the Spartan 6 are pretty grumpy and fickle. We hope to eventually integrate working support for them into the HDMI2USB LiteX firmware, but again have not had the developer time to do so.

Hope that helps!

Closed 2018-02-05.

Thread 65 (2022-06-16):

Numato obsoletion notice - any replacements?

nyov, 2022-06-16:
Numato has [discontinued the product](https://numato.com/?s=opsis).

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

Are there any known replacements or similar boards?
Are there any other vendors producing the board?

mithro, 2022-06-17:
Depending on the functionality you where using, the NeTV2 might be a replacement. See https://www.crowdsupply.com/alphamax/netv2

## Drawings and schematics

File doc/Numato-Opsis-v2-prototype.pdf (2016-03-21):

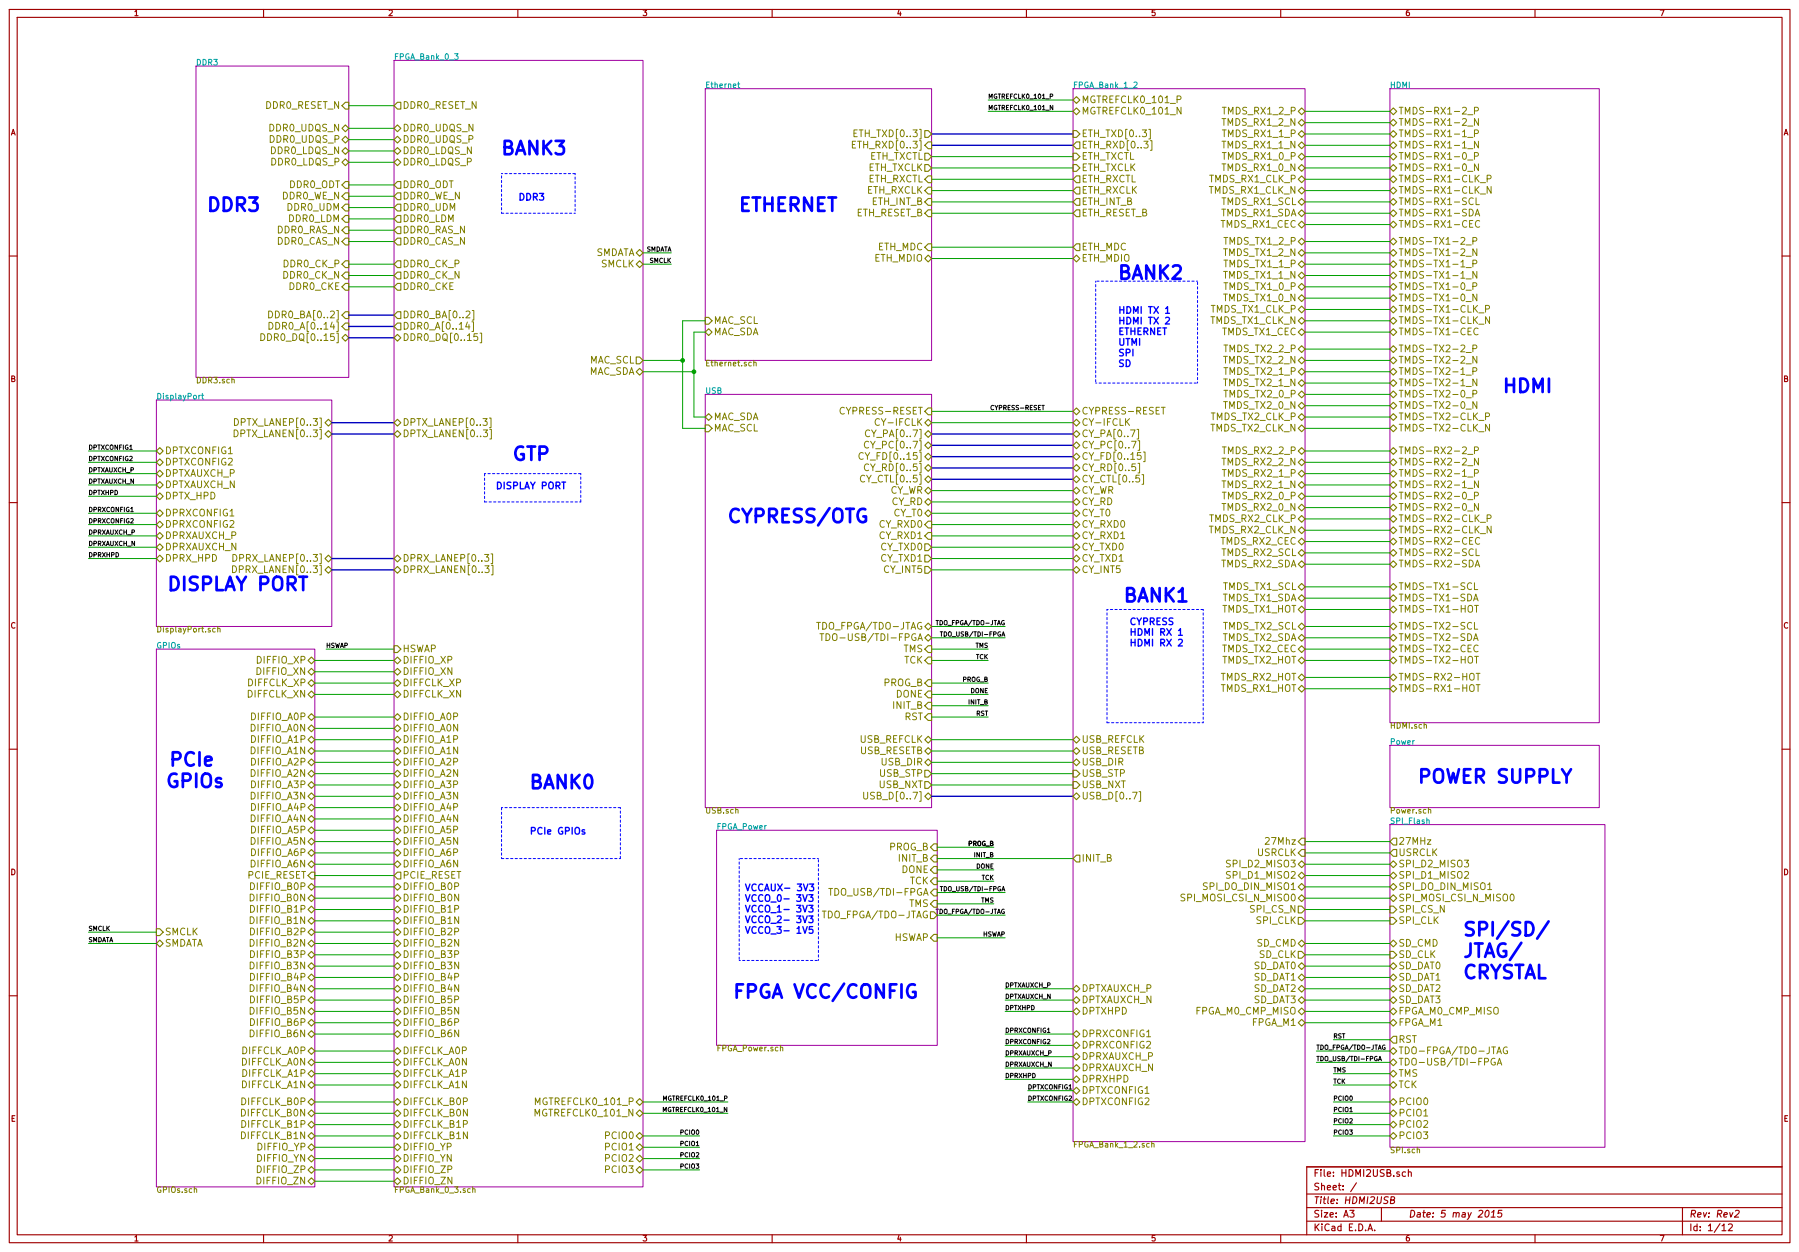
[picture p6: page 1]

TDO-USB/TDI-FPGA

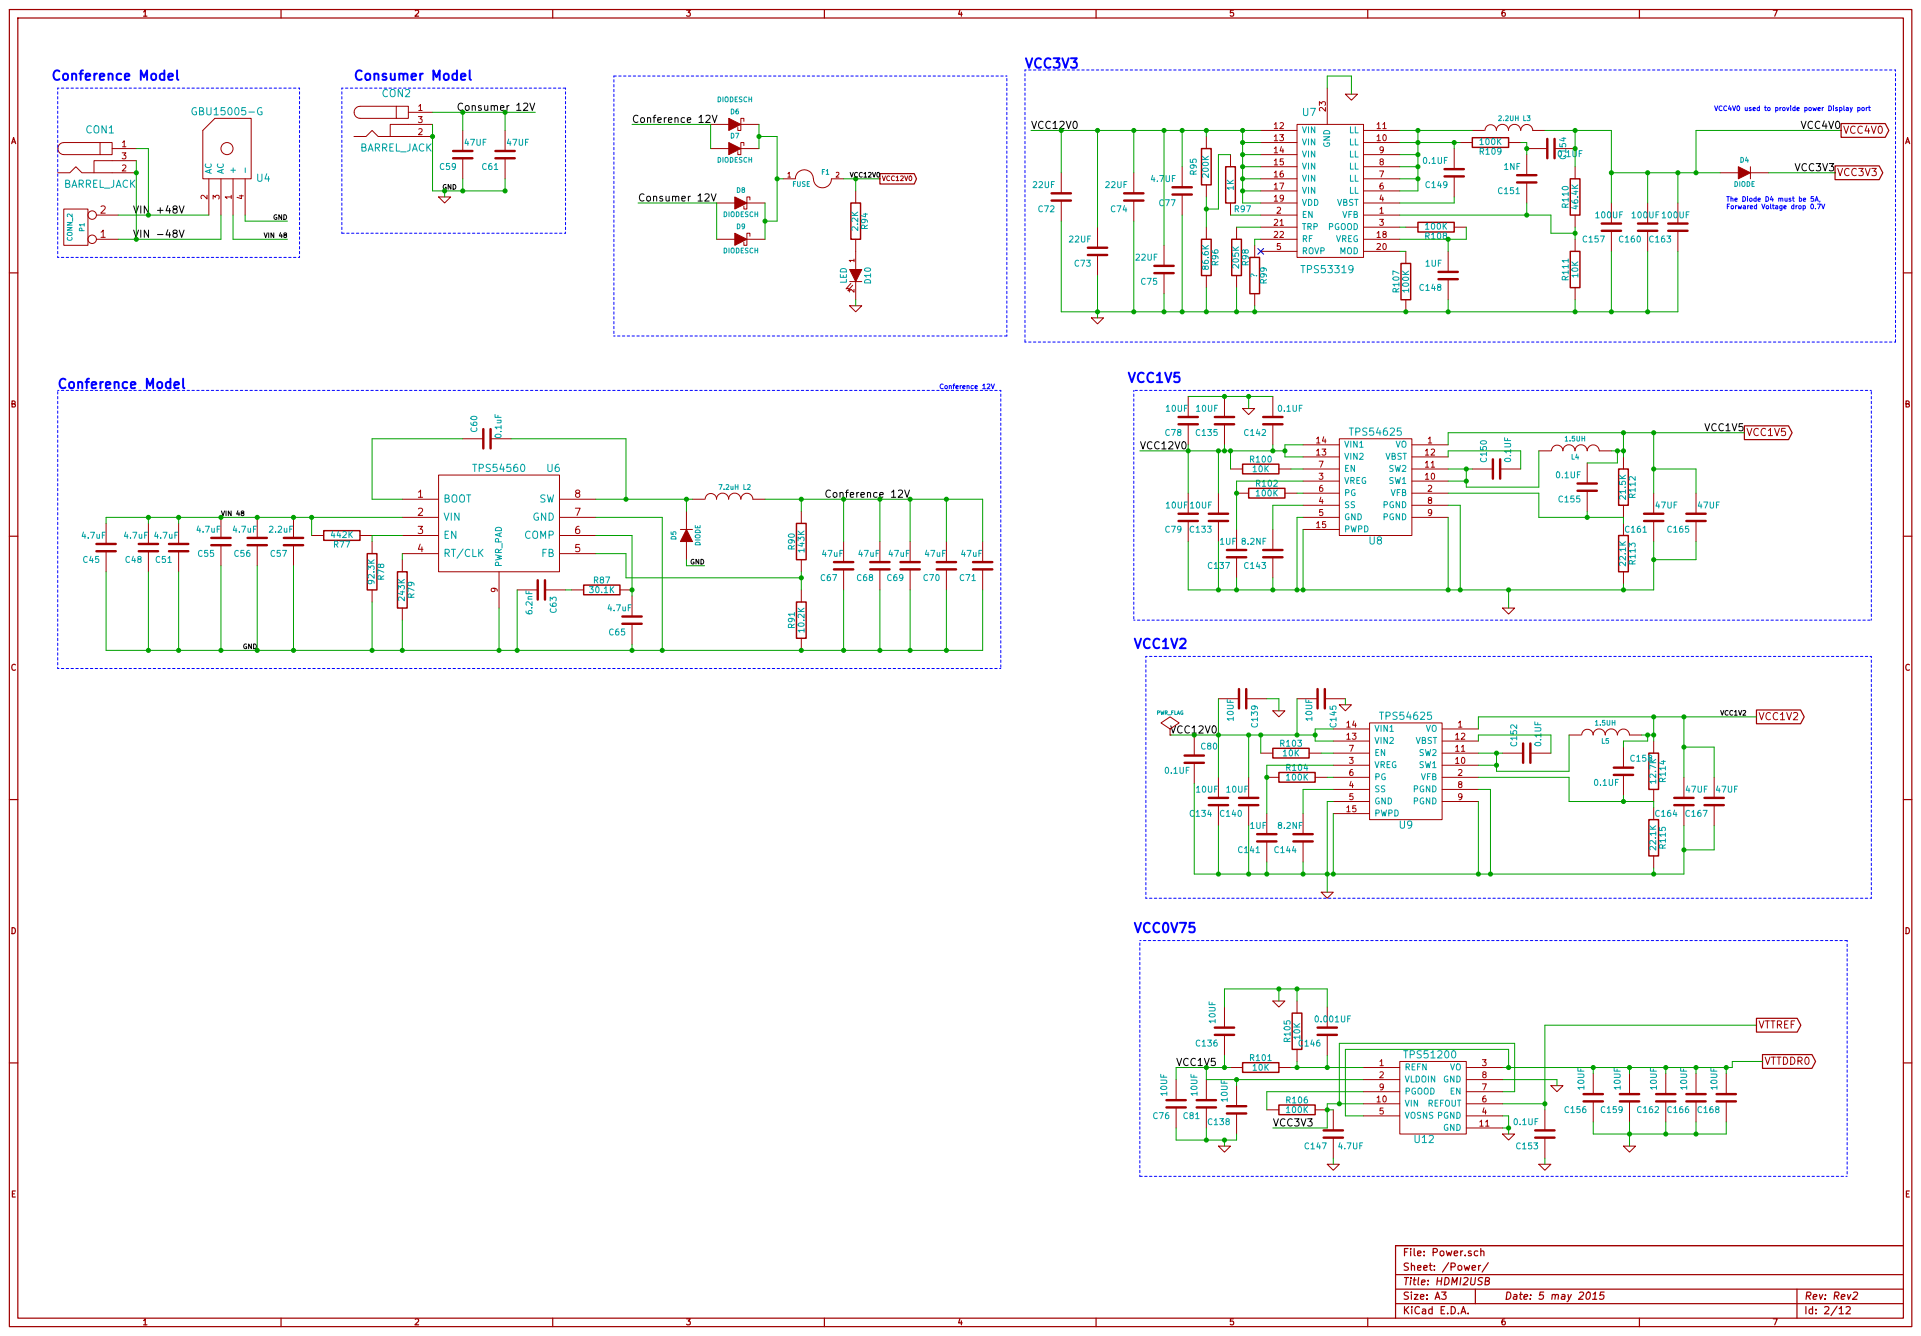
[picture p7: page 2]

VCC4V0 used to provide power Display port The Diode D4 must be 5A, Forwared Voltage drop 0.7V

File: Power.sch Sheet: /Power/

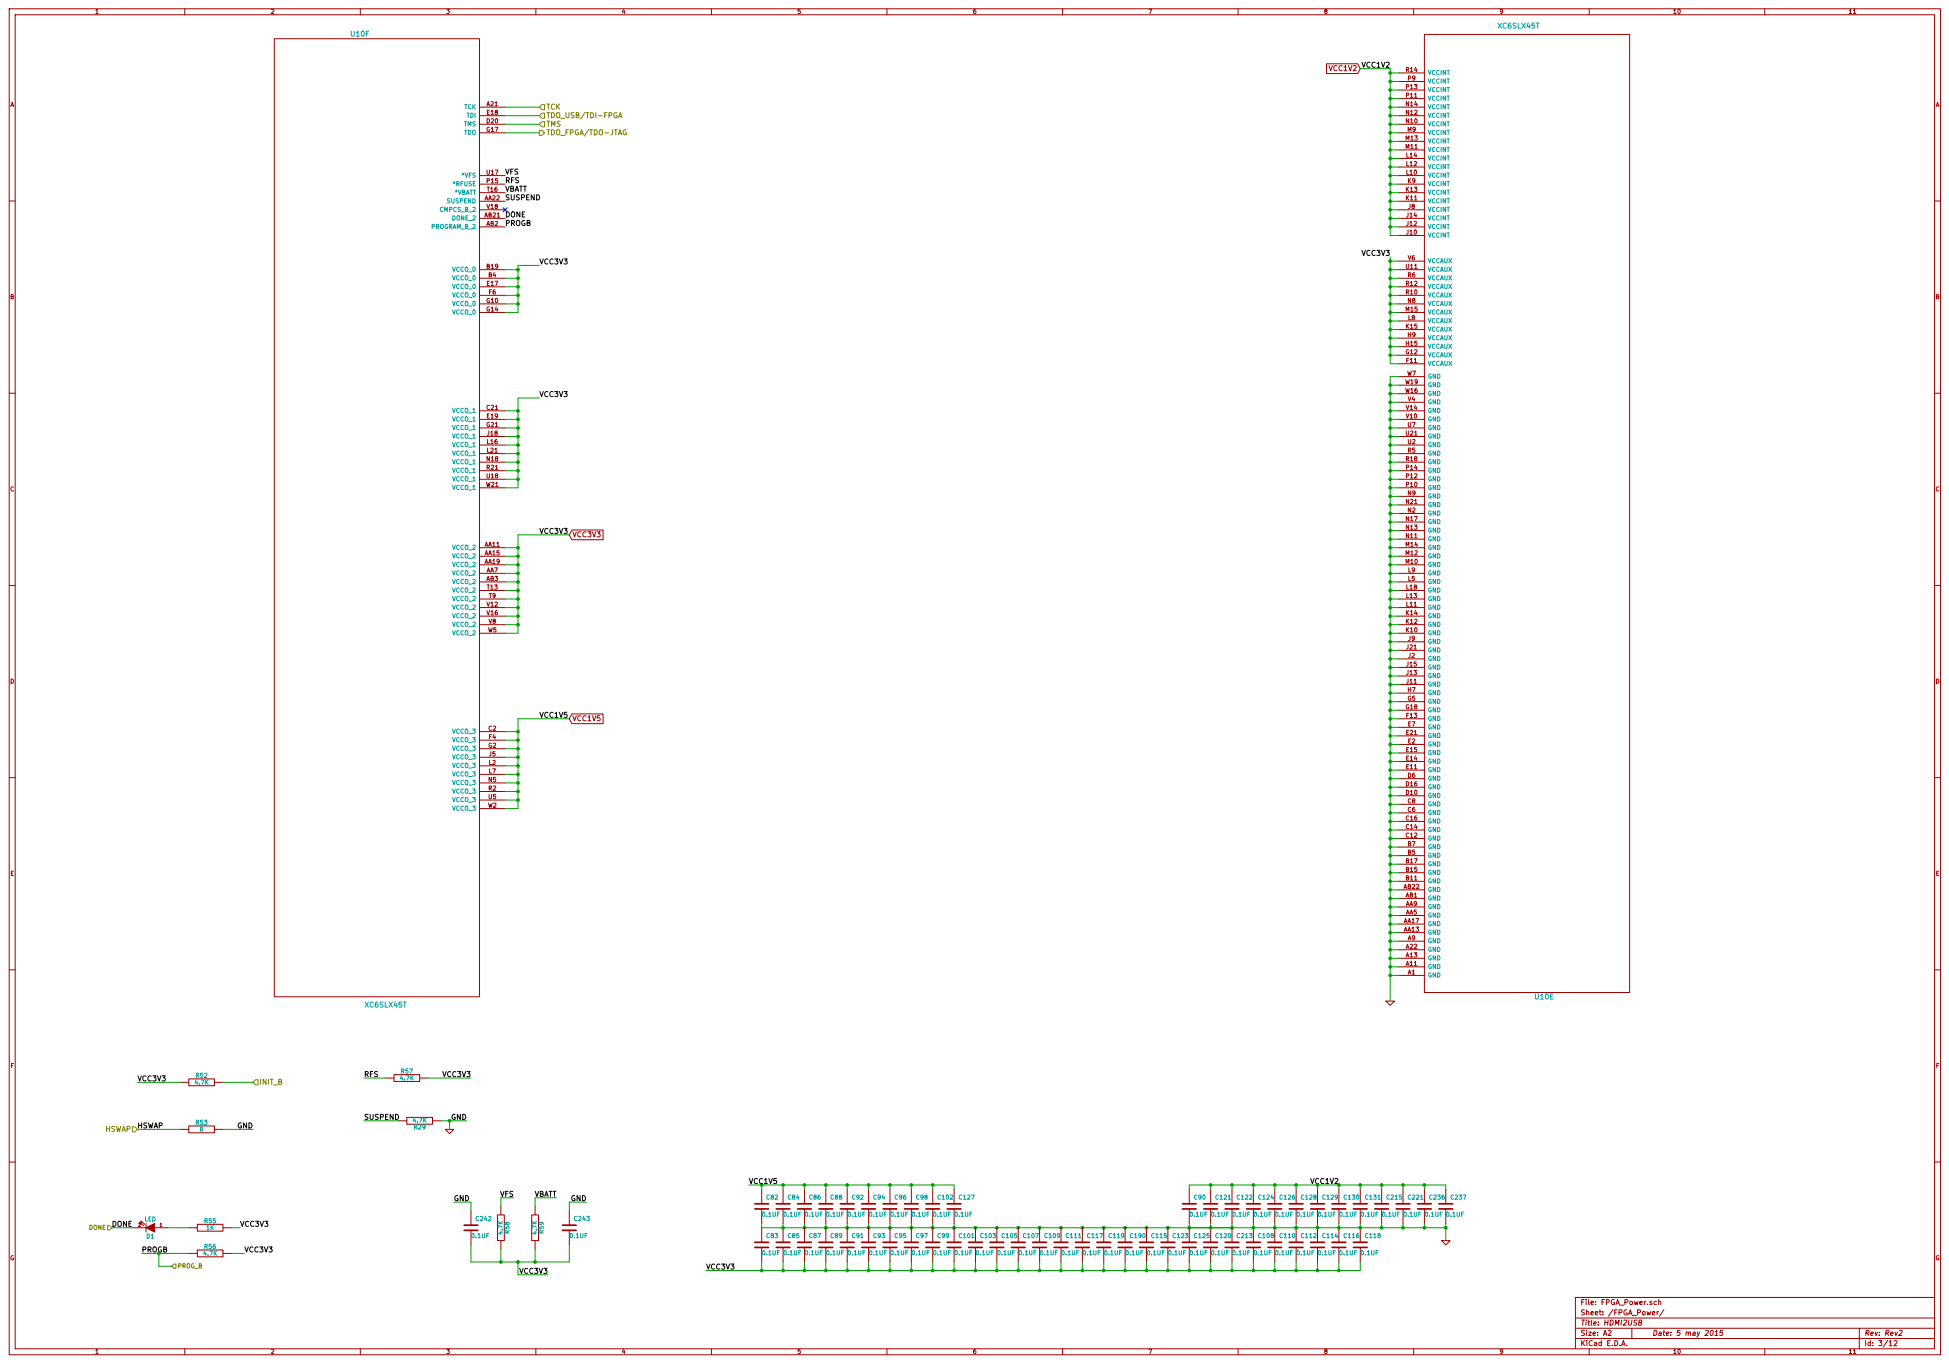
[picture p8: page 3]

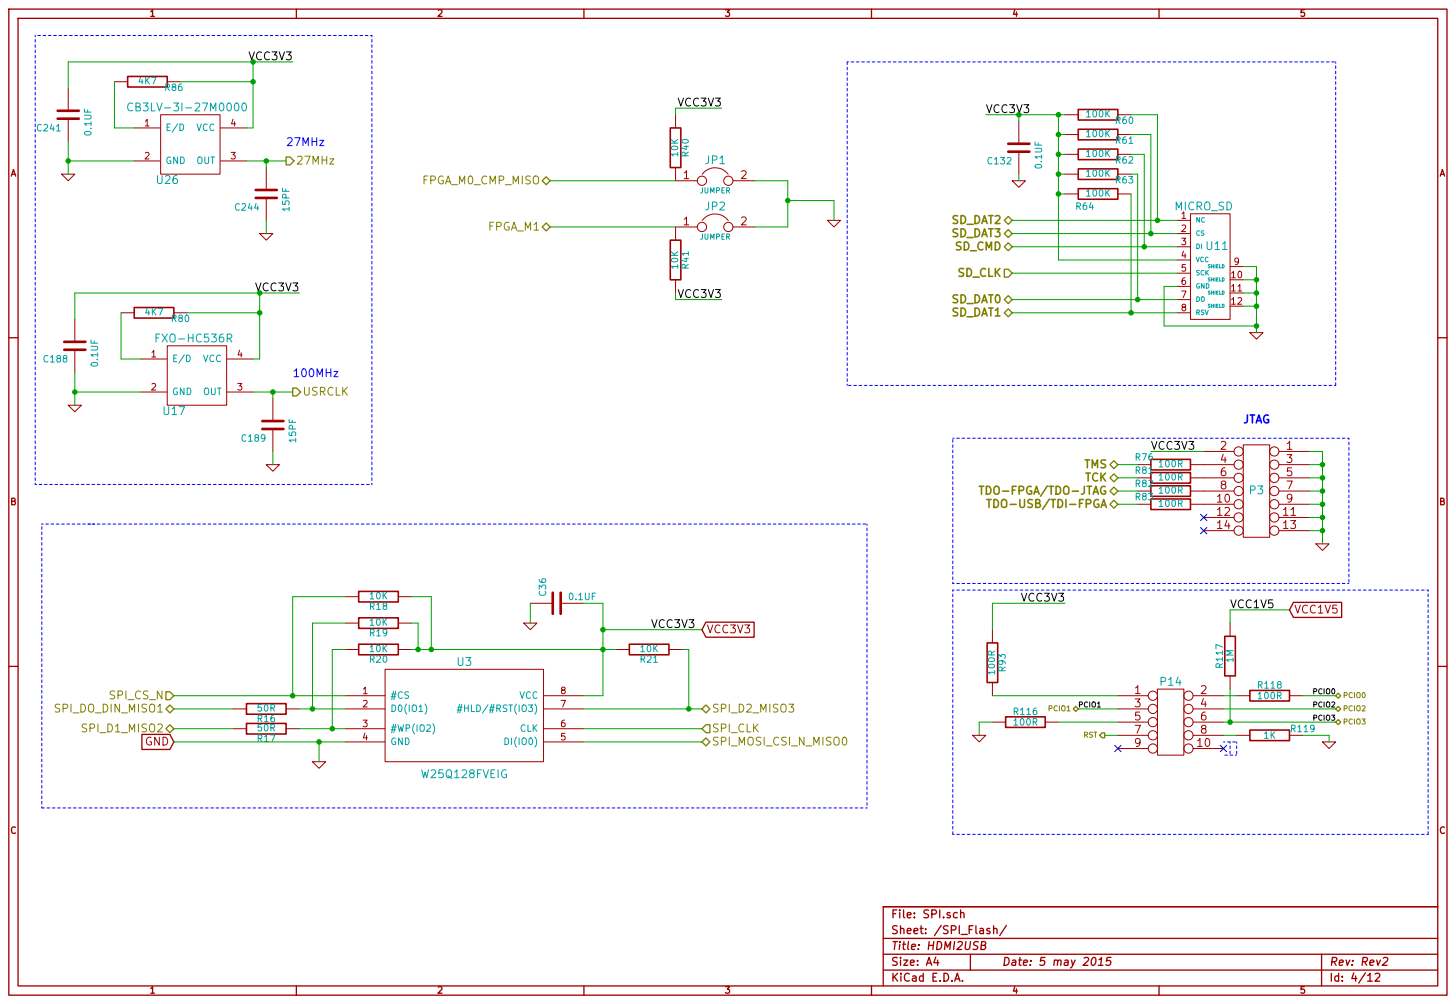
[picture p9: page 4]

CS 2
DI 3
VCC 4

TDO-FPGA/TDO-JTAG
TDO-USB/TDI-FPGA

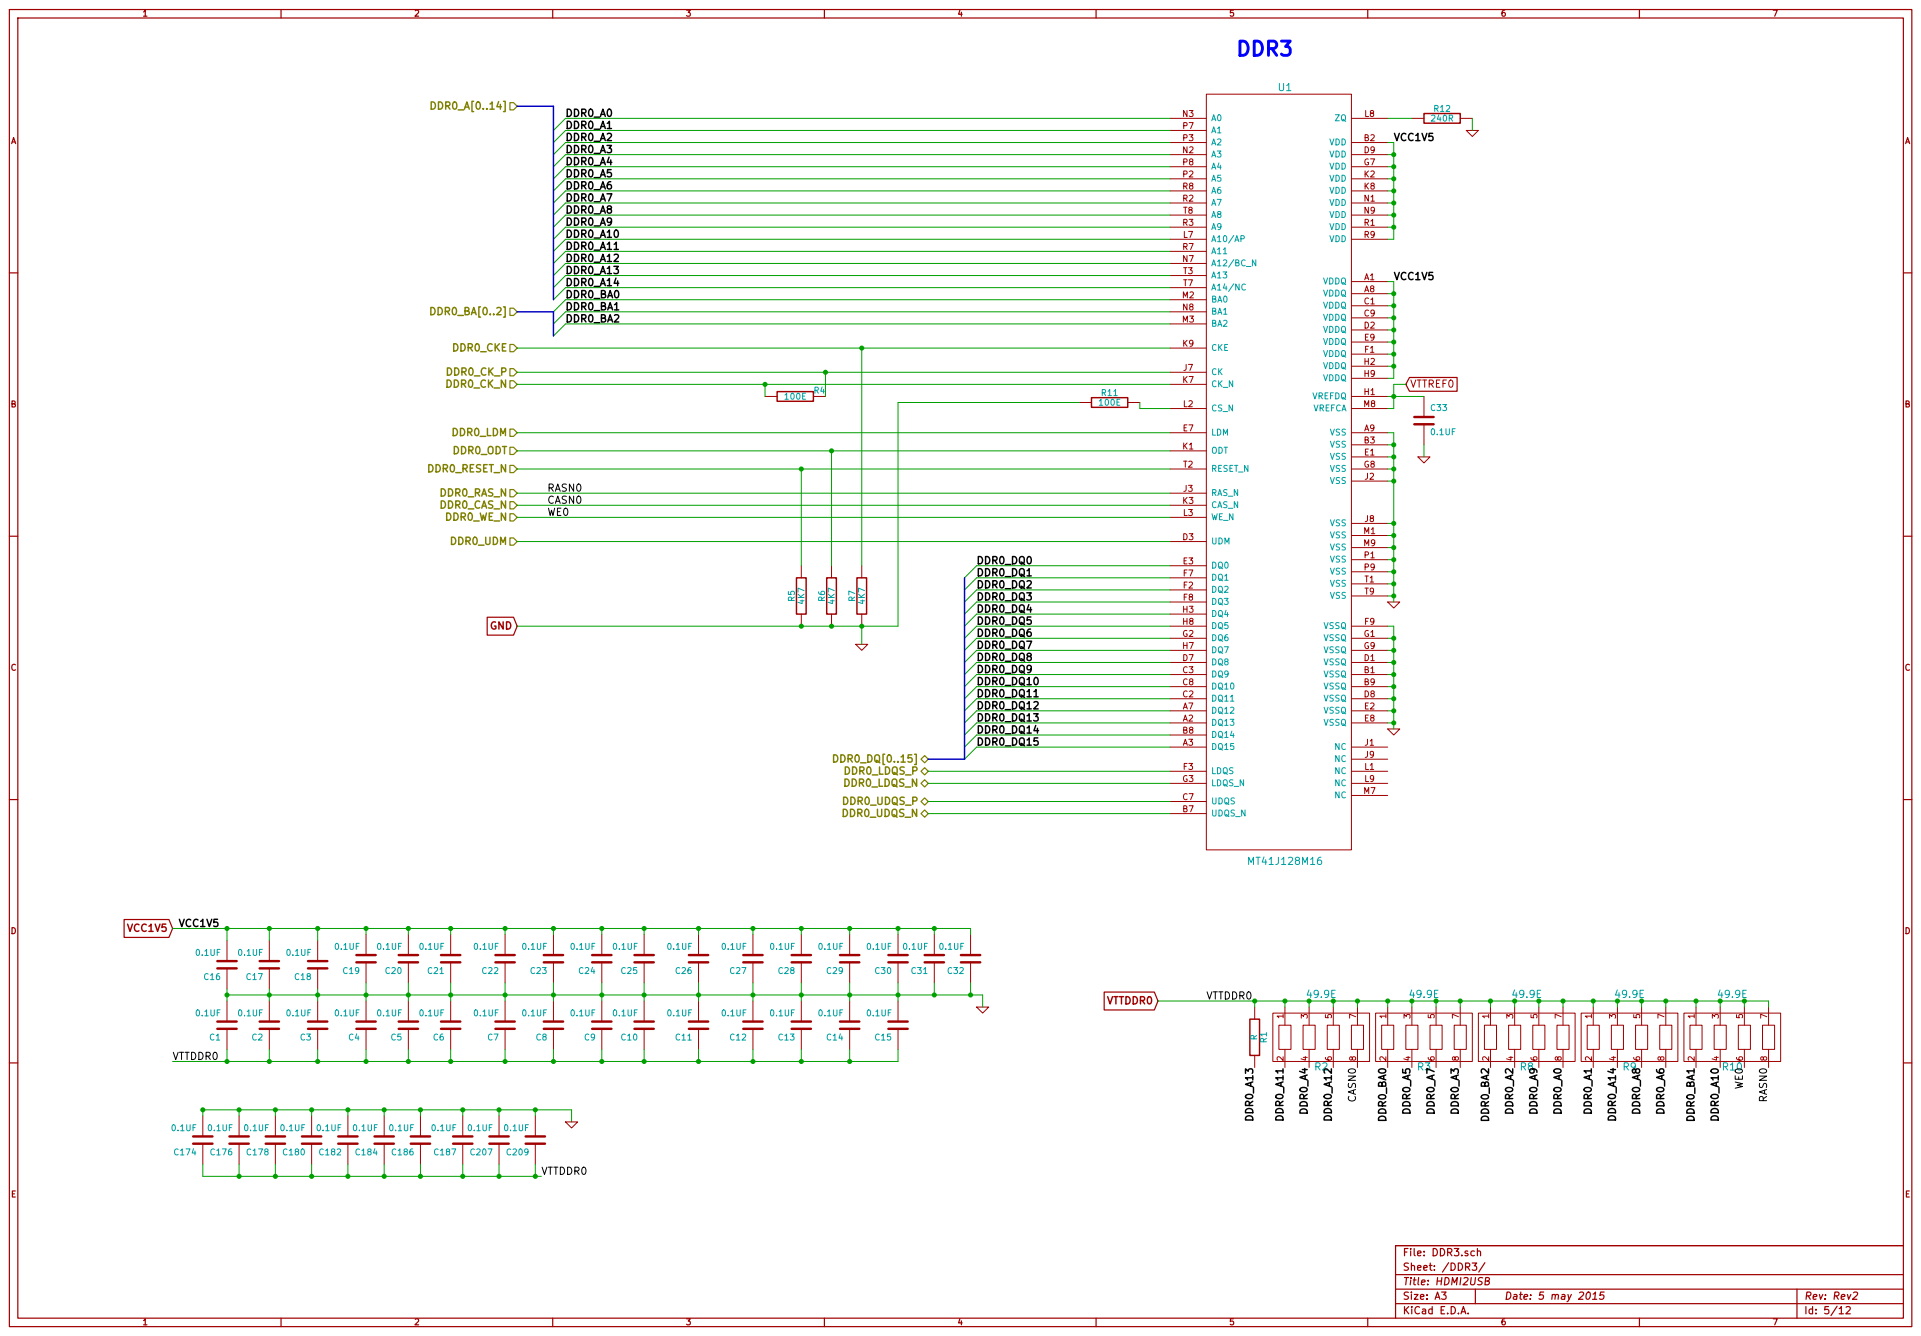
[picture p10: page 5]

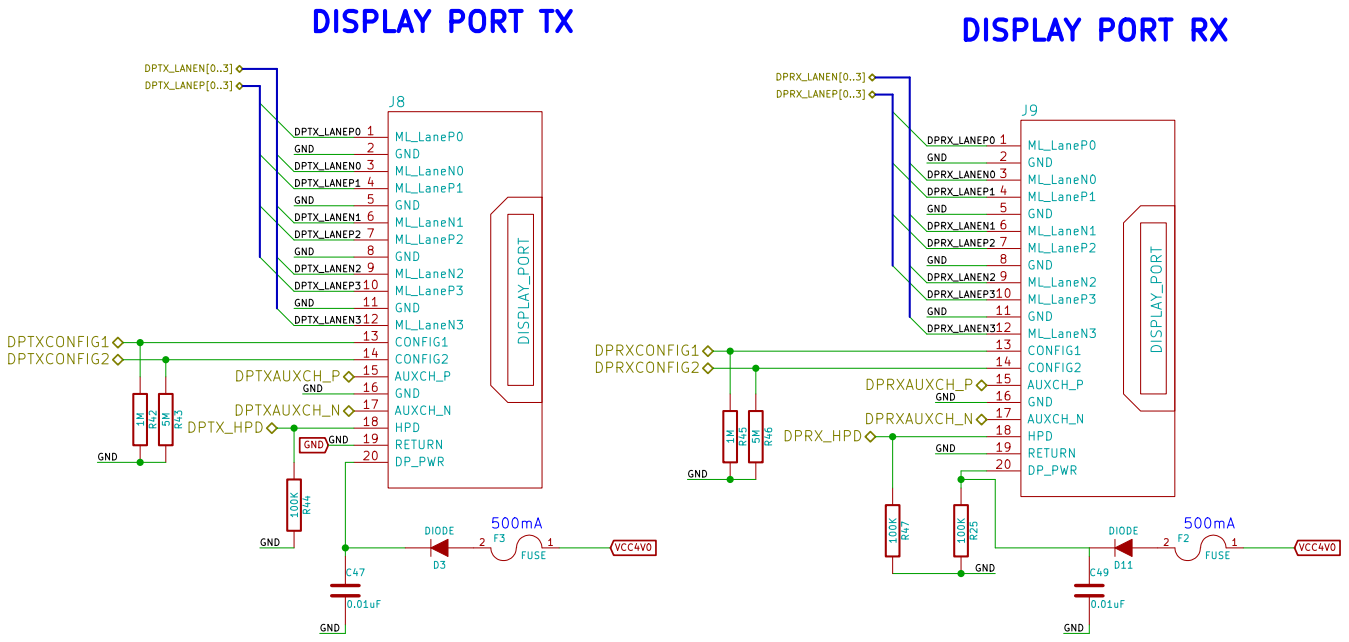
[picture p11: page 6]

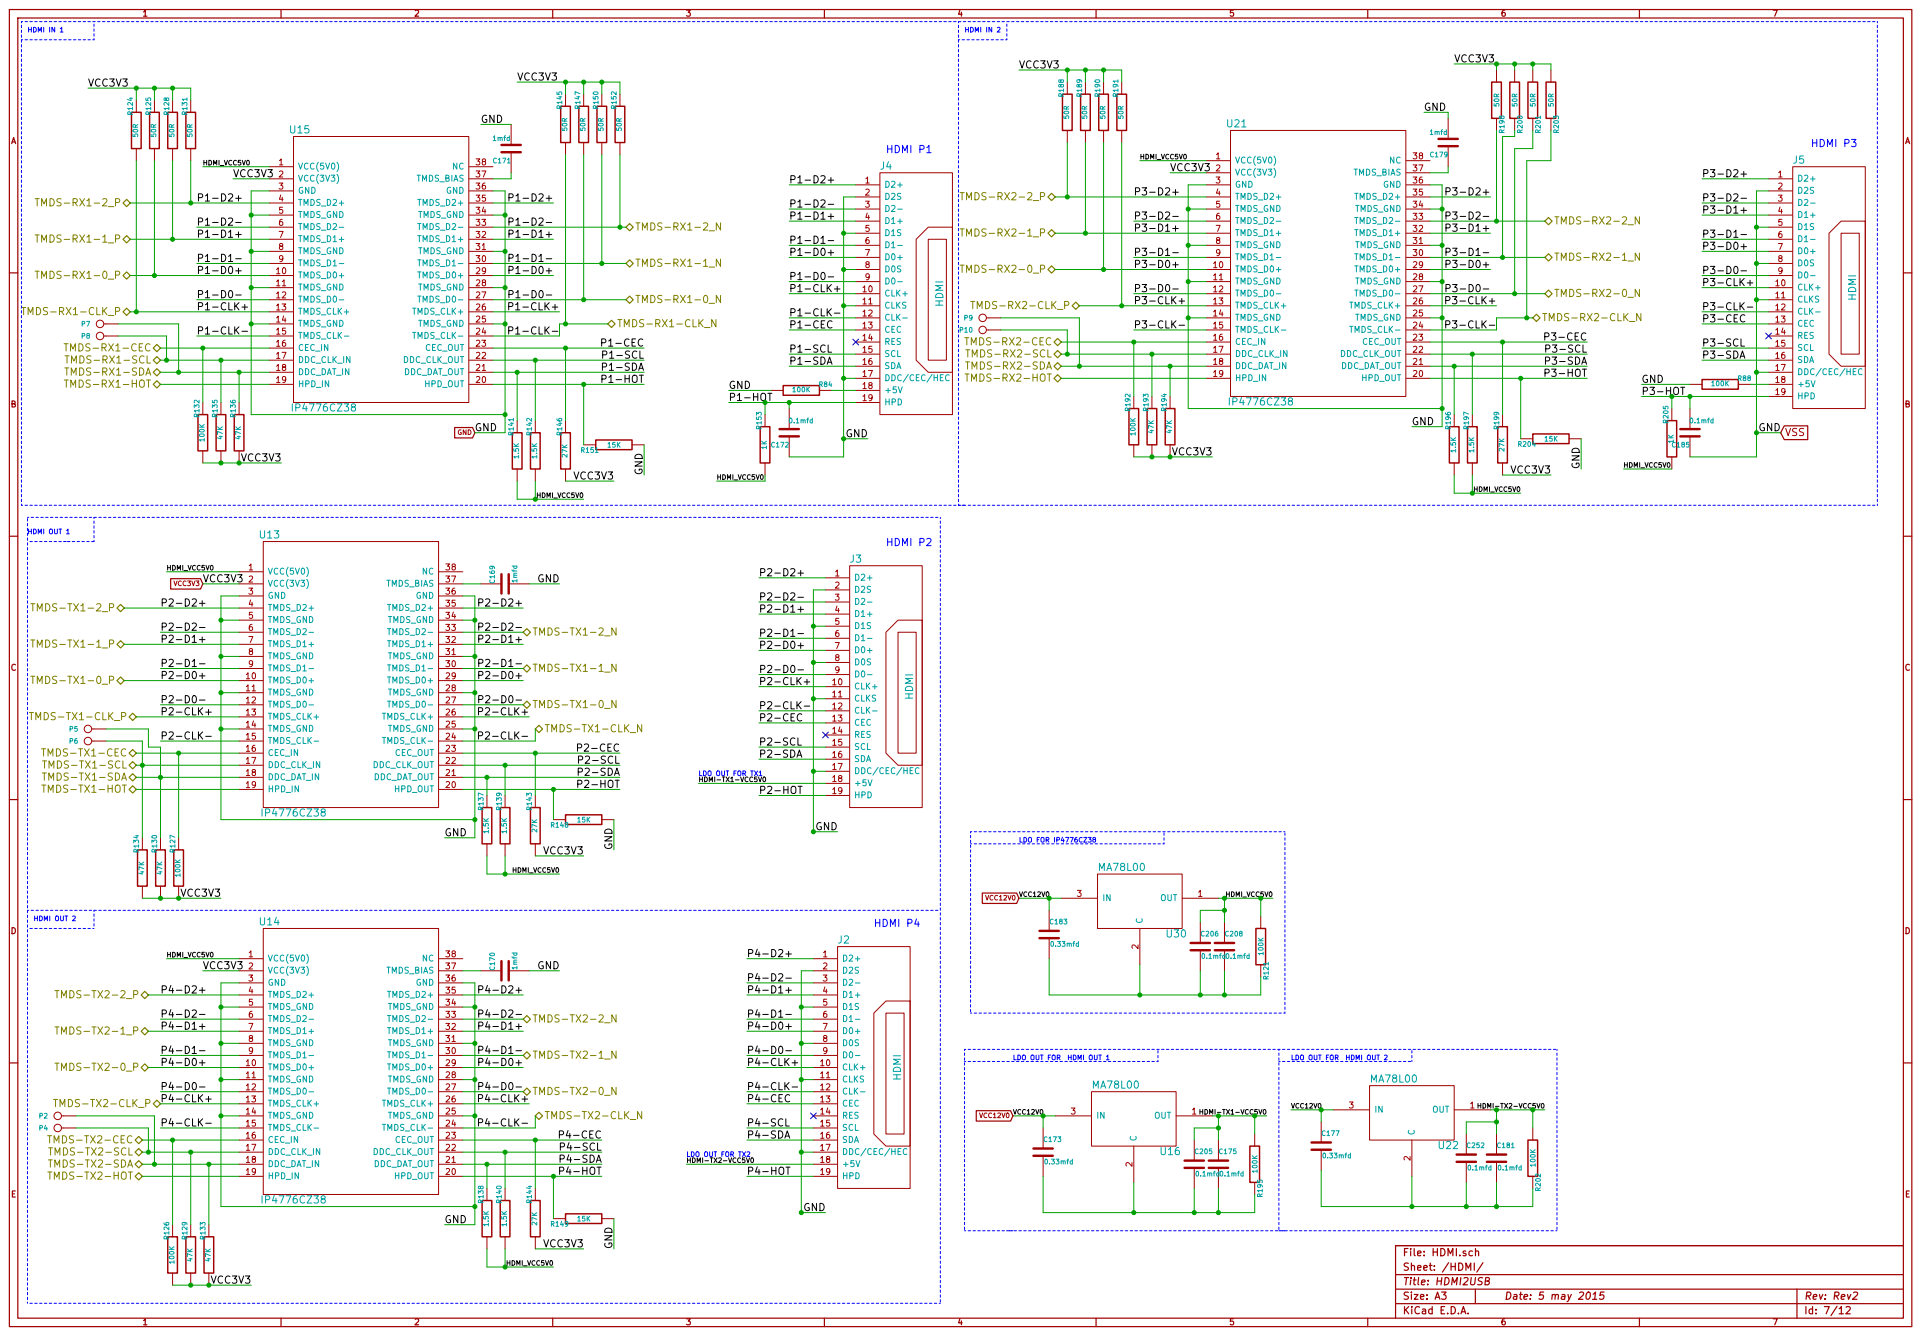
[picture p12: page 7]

LDO OUT FOR TX2 HDMI OUT 2

File: HDMI.sch Sheet: /HDMI/

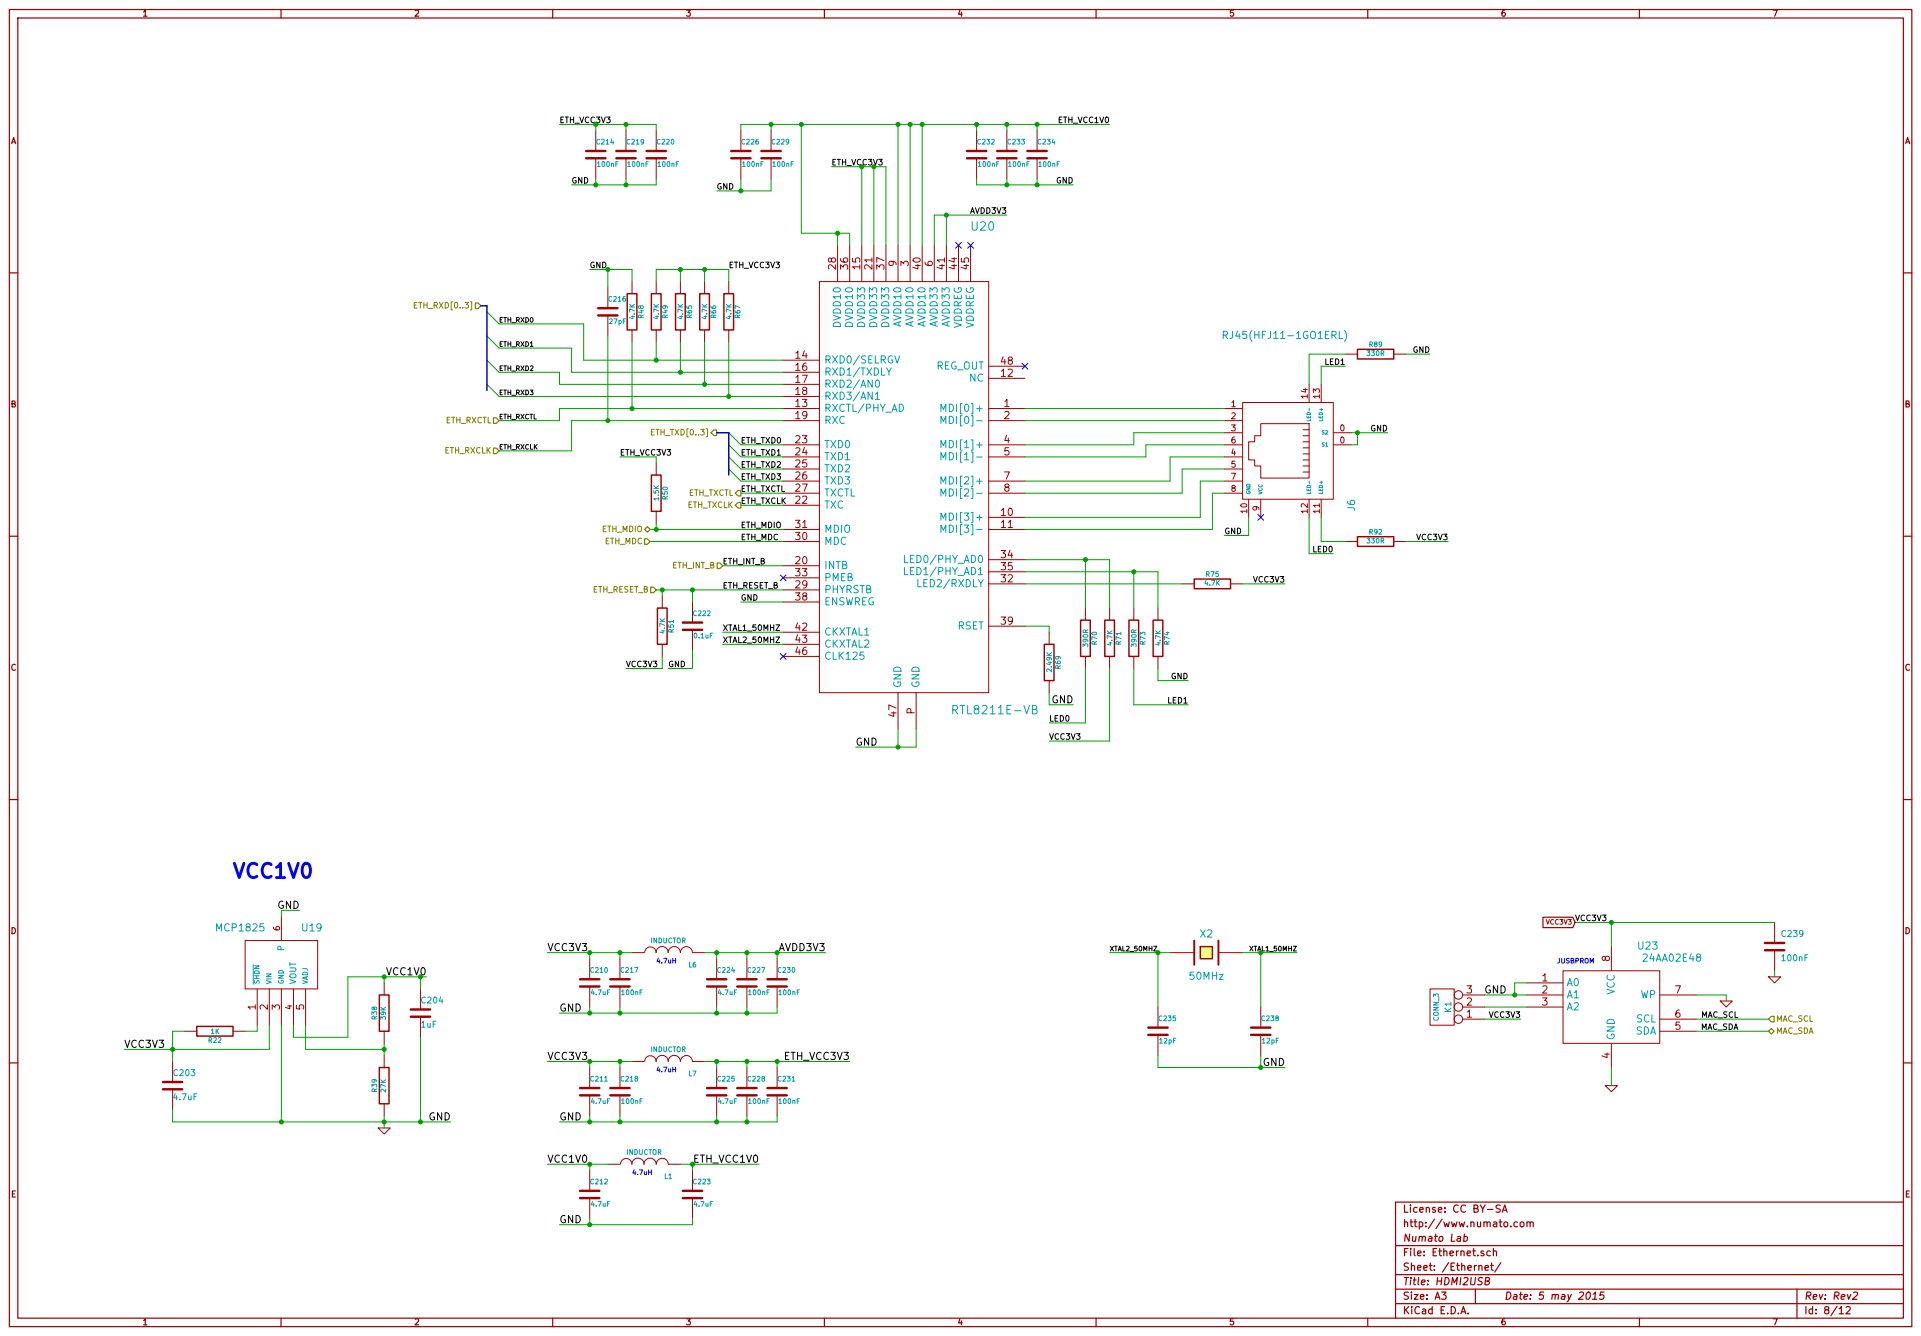
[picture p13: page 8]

License: CC BY-SA
http://www.numato.com
File: Ethernet.sch Sheet: /Ethernet/ Numato Lab

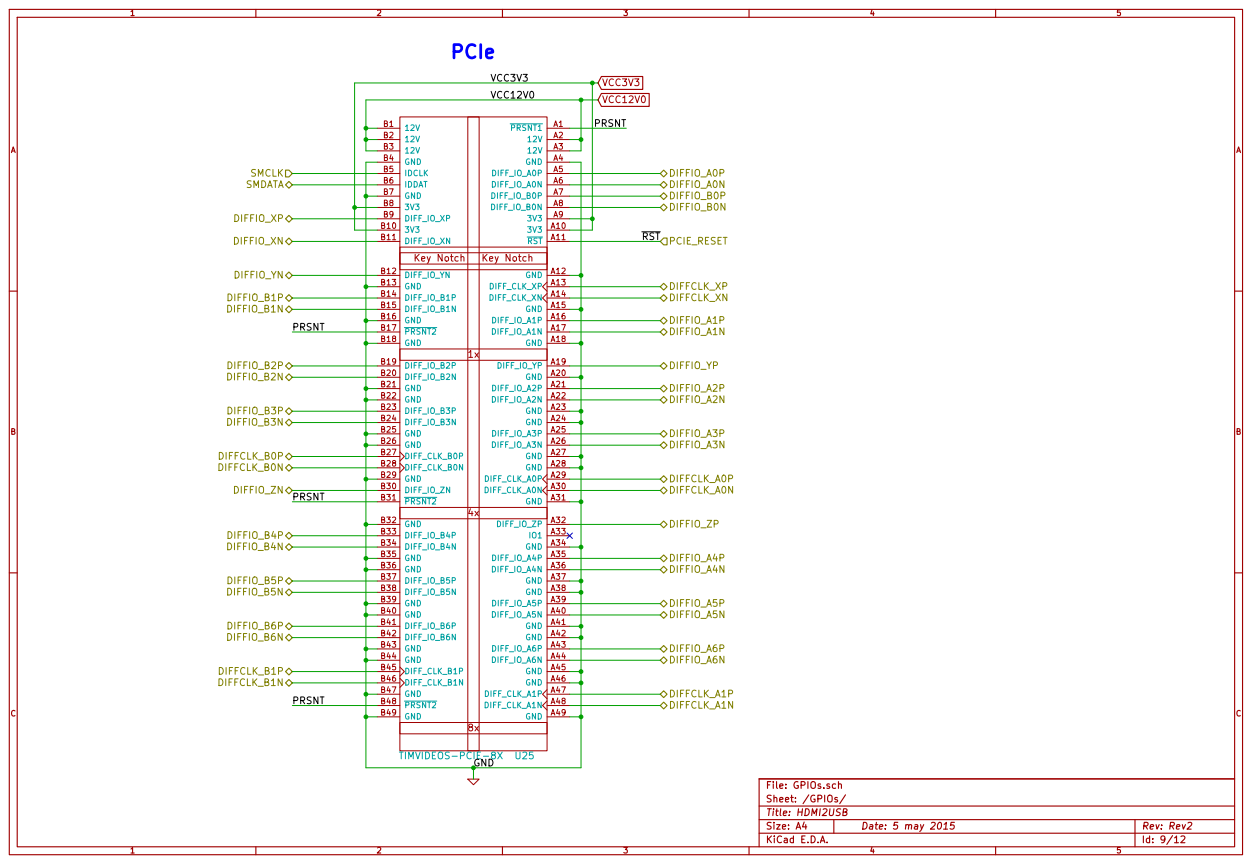
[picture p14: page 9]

PRSNT1 12V DIFF_IO_A0N DIFF_IO_B0N DIFF_IO_A0P DIFF_IO_B0P GND 12V 3V3 | A1 12V B1 A2 12V B2 A3 12V B3 A4 GND B4 A5 IDCLK B5 A6 IDDAT B6 A7 GND B7 A8 3V3 B8 A9 DIFF_IO_XP B9

Key Notch | | Key Notch

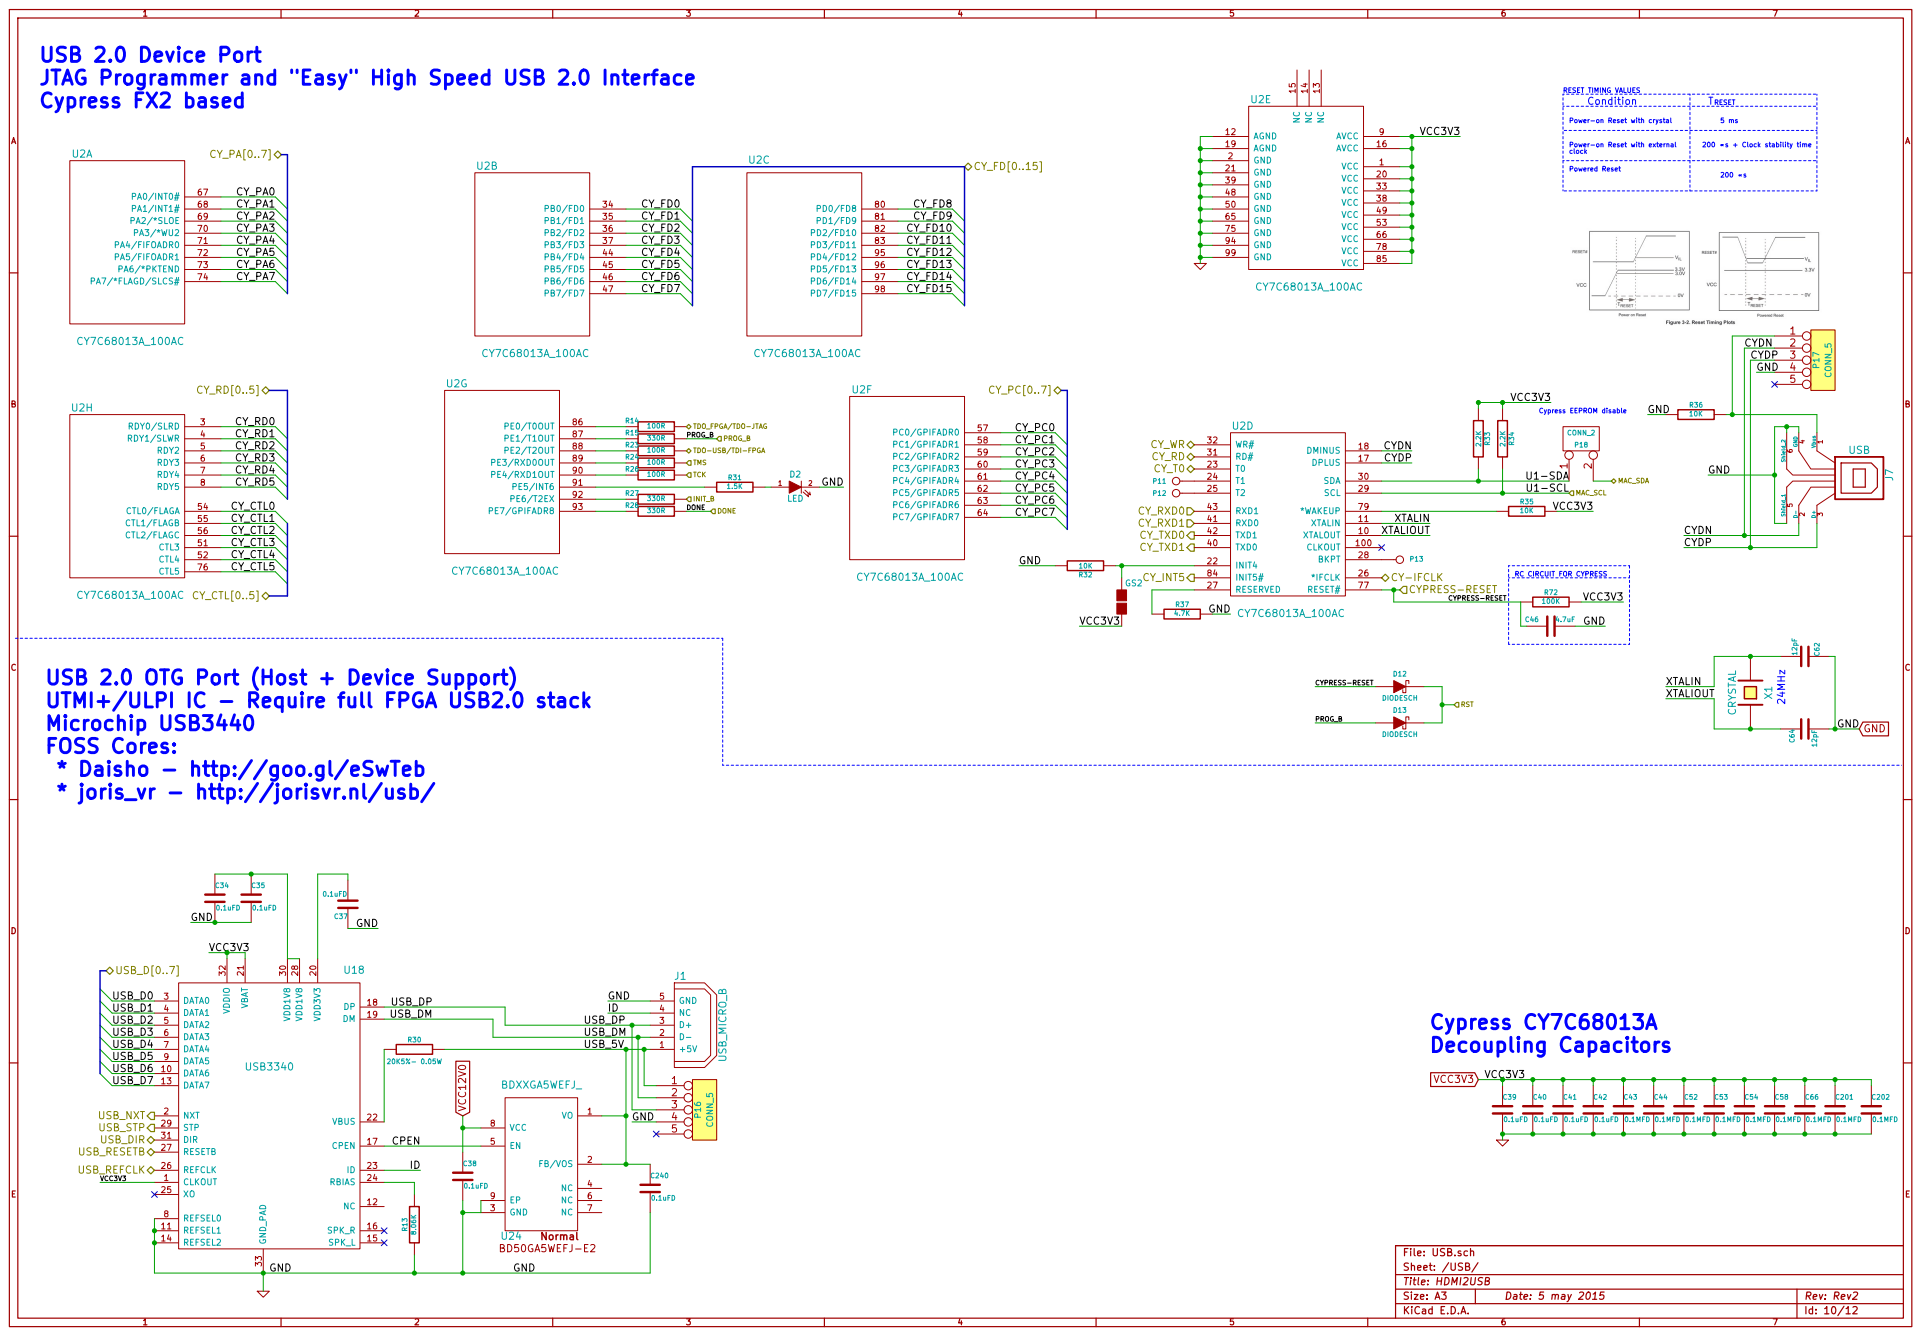
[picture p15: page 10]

USB 2.0 Device Port
JTAG Programmer and "Easy" High Speed USB 2.0 Interface
Cypress FX2 based

5 ms 200 s + Clock stability time

TDO-USB/TDI-FPGA
TMS

USB 2.0 OTG Port (Host + Device Support)
UTMI+/ULPI IC - Require full FPGA USB2.0 stack
Microchip USB3440
FOSS Cores:
* Daisho - http://goo.gl/eSwTeb
* joris_vr - http://jorisvr.nl/usb/

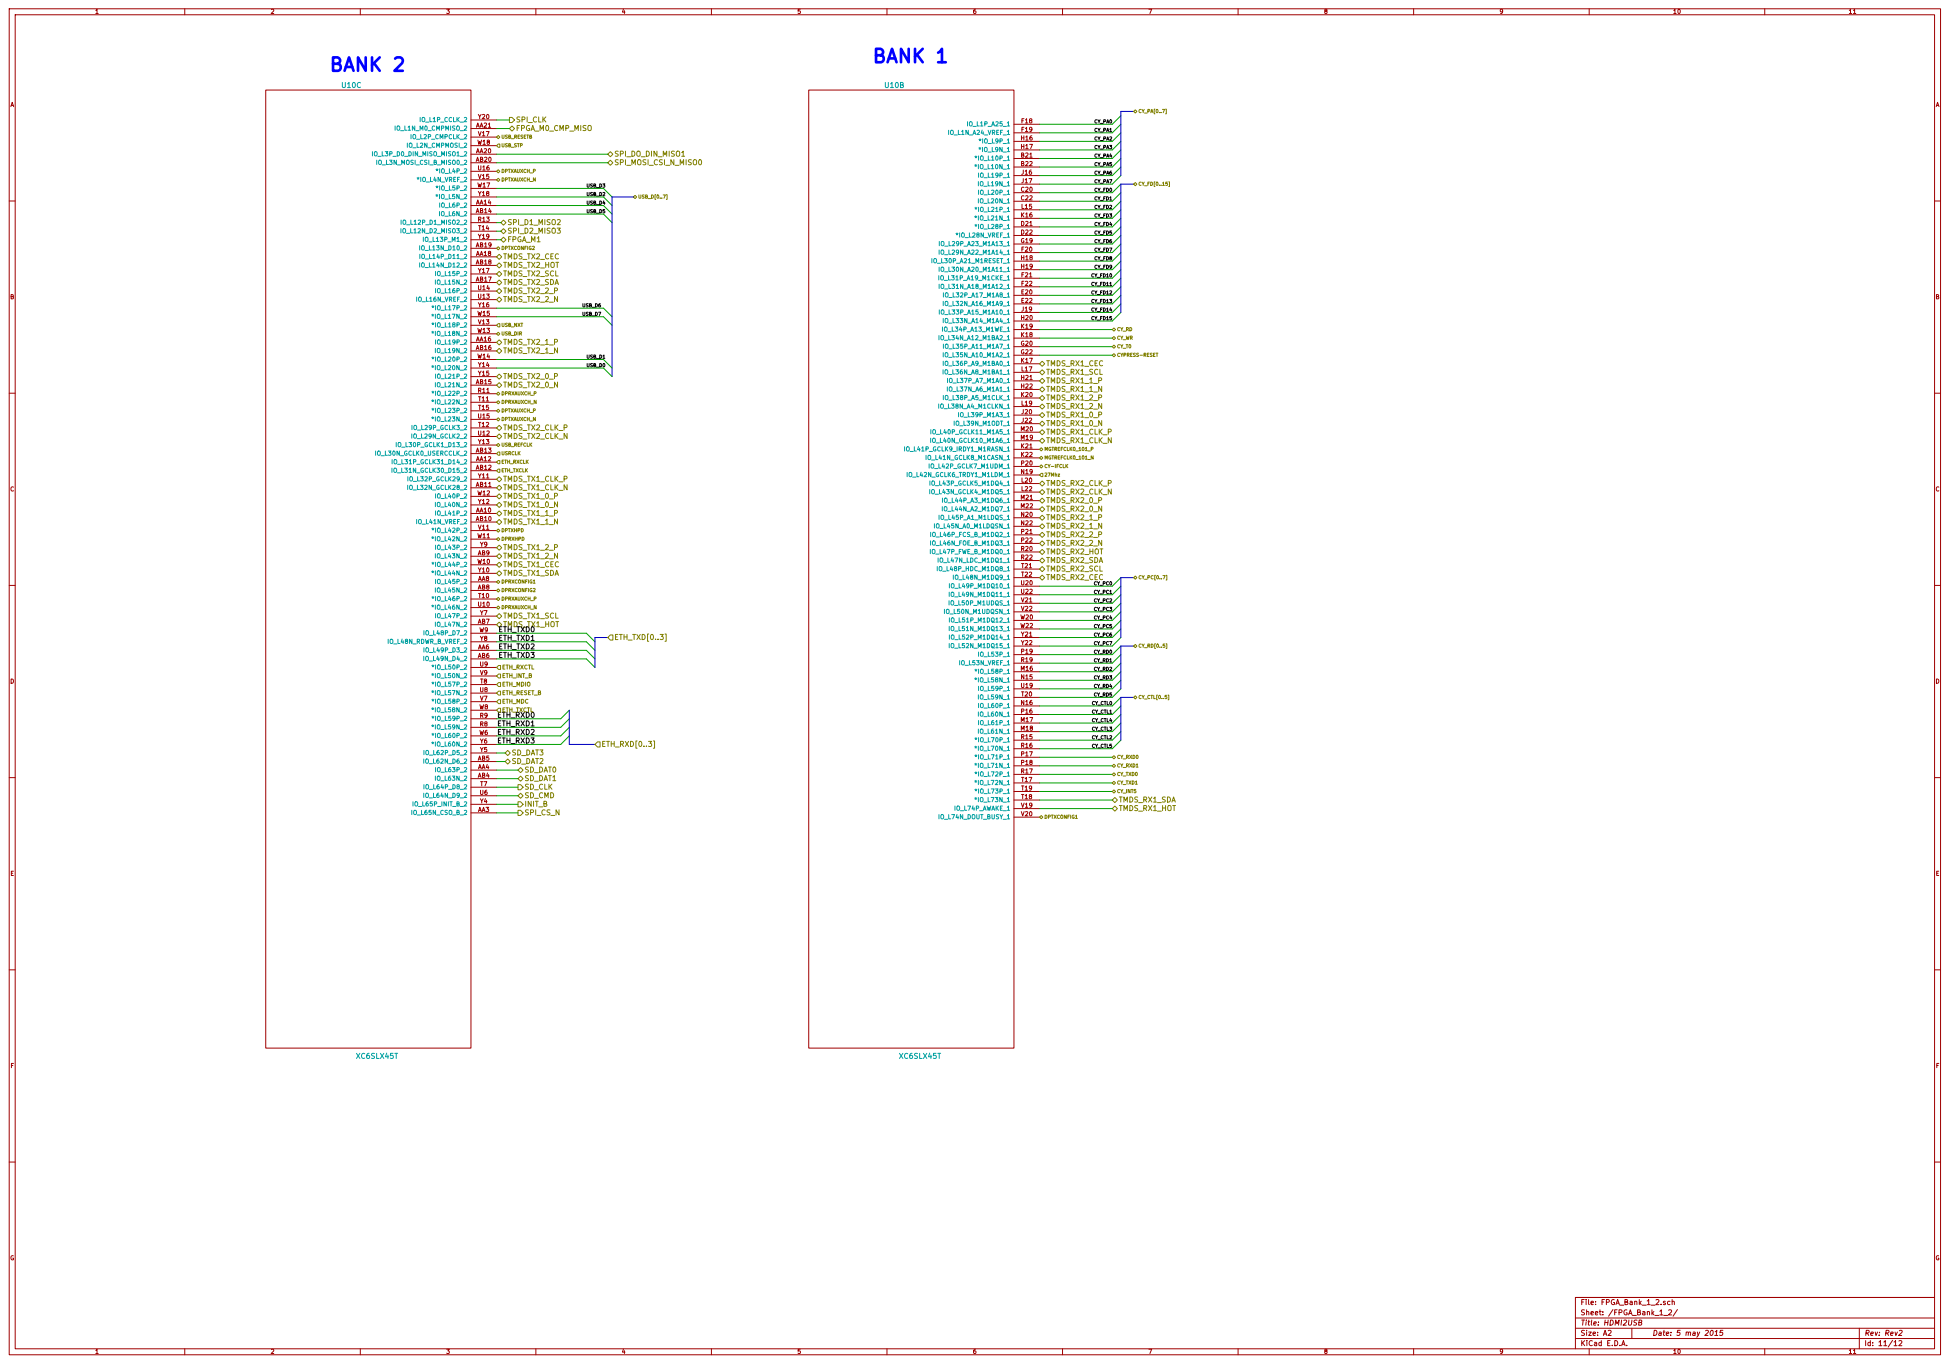
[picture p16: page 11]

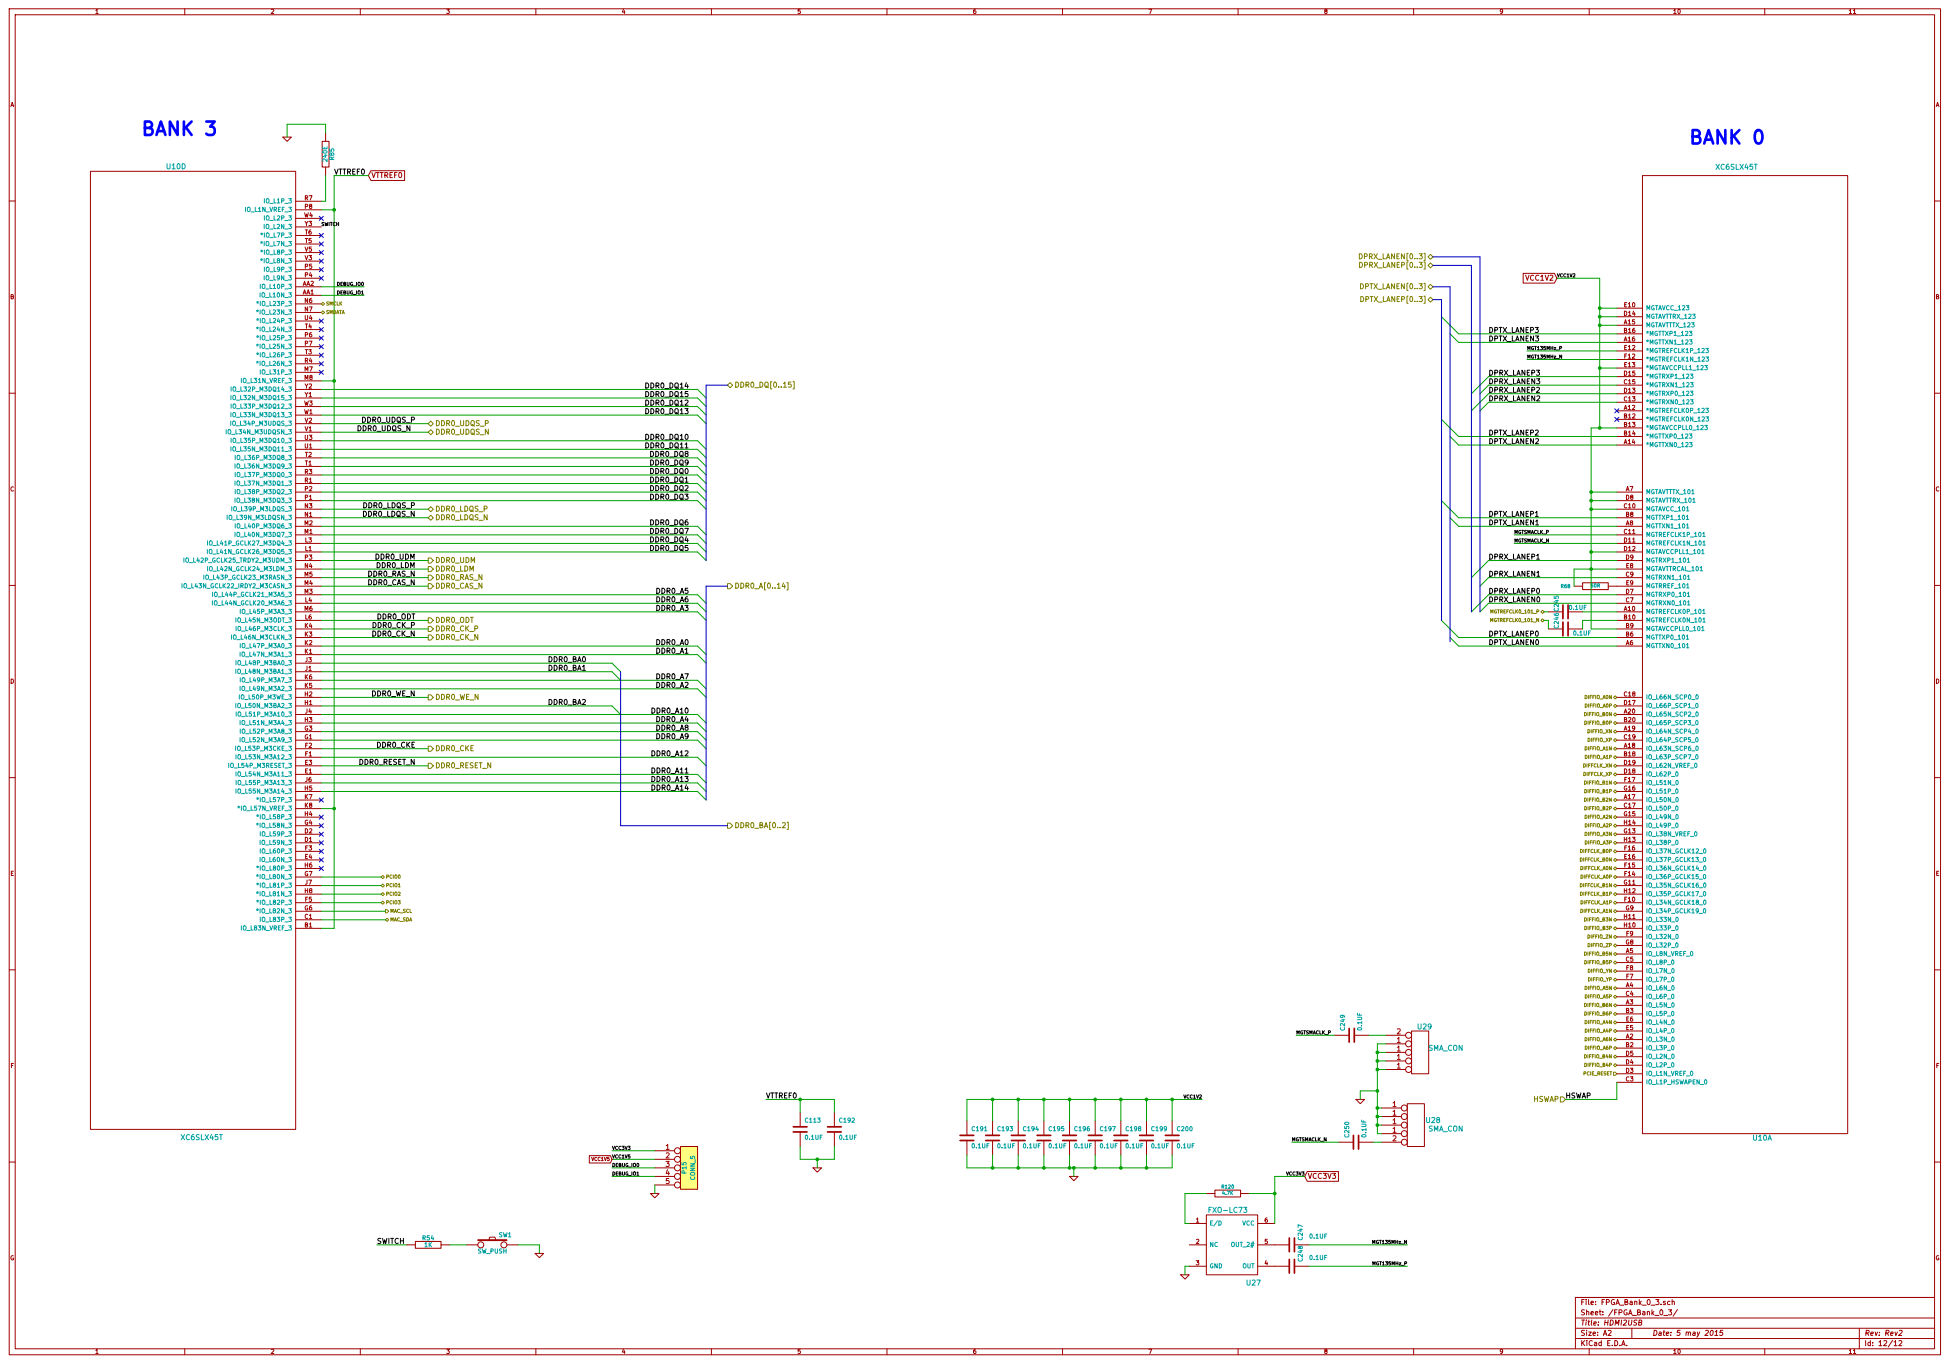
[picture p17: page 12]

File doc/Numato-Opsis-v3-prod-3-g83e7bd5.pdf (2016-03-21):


HDMI
TMDS-RX1 TMDS-TX1 TMDS-RX2 TMDS-TX2

TDO-USB/TDI-FPGA

$Id: 6301cb795b5a8d025108038f71ed16bcd2b7e012 $
License: CC-BY-SA 4.0 International
Designed in collaboration between Numato Lab and TimVideos.us
http://opsis.hdmi2usb.tv/
Sheet: / Numato Lab
File: HDMI2USB.sch


VCC4V0 used to provide power Display port The Diode D4 must be 5A, Forwared Voltage drop 0.7V

Wide Range Power Supply

* R99 is the RF resister is used for selecting switching frequency of TPS53319, If left this pin open , the switching frequency will be 500Khz.Please refer Table 1 for more details. *DNP Table 1 Resistor and Switching Frequency

$Id: fe05f9a7b63efa227744b9dfde989bd6d71b1d80 $
License: CC-BY-SA 4.0 International
Designed in collaboration between Numato Lab and TimVideos.us
http://opsis.hdmi2usb.tv/
Title: Numato Opsis - Power Supply File: Power.sch Sheet: /Power/ Numato Lab


$Id: 3f3c6c9d0551079dbbd5aa765011b6a342053f0b $
License: CC-BY-SA 4.0 International
Designed in collaboration between Numato Lab and TimVideos.us
http://opsis.hdmi2usb.tv/
Sheet: /FPGA_Power/ Numato Lab
File: FPGA_Power.sch

Title: Numato Opsis - FPGA Power Pins


TDO-FPGA/TDO-JTAG
TDO-USB/TDI-FPGA

$Id: 0fe05815db3cdd58968b2378be315199a299ea26 $
License: CC-BY-SA 4.0 International
Designed in collaboration between Numato Lab and TimVideos.us
http://opsis.hdmi2usb.tv/
Sheet: /SPI_Flash/ Numato Lab
File: SPI.sch

Title: Numato Opsis - FPGA Support (SPI Flash, Clocks, etc)


License: CC-BY-SA 4.0 International
Designed in collaboration between Numato Lab and TimVideos.us
http://opsis.hdmi2usb.tv/
File: DDR3.sch Sheet: /DDR3/ Numato Lab

Title: Numato Opsis - DDR3 RAM


License: CC-BY-SA 4.0 International
Designed in collaboration between Numato Lab and TimVideos.us
http://opsis.hdmi2usb.tv/
Sheet: /DisplayPort/ Numato Lab
File: DisplayPort.sch

Title: Numato Opsis - DisplayPort


$Id: 4ada892ce6de4c4bc57609923bc3ea80a9e2ccbe $
License: CC-BY-SA 4.0 International
Designed in collaboration between Numato Lab and TimVideos.us
http://opsis.hdmi2usb.tv/
Title: Numato Opsis - Ethernet File: Ethernet.sch Sheet: /Ethernet/ Numato Lab


PRSNT1 12V DIFF_IO_A0N DIFF_IO_B0N DIFF_IO_A0P DIFF_IO_B0P GND 12V 3V3 | A1 12V B1 A2 12V B2 A3 12V B3 A4 GND B4 A5 IDCLK B5 A6 IDDAT B6 A7 GND B7 A8 3V3 B8 A9 DIFF_IO_XP B9

Key Notch | | Key Notch

$Id: 2cb302854aba0eb9c05a24f1d526b3e2089cc004 $
License: CC-BY-SA 4.0 International
Designed in collaboration between Numato Lab and TimVideos.us
http://opsis.hdmi2usb.tv/
Sheet: /GPIOs/ Numato Lab
File: GPIOs.sch

Title: Numato Opsis - TOFE Expansion Header


USB 2.0 Device Port
JTAG Programmer and "Easy" High Speed USB 2.0 Interface
Cypress FX2 based

5 ms 200 s + Clock stability time

TDO-USB/TDI-FPGA
TMS

USB 2.0 OTG Port (Host + Device Support)
UTMI+/ULPI IC - Require full FPGA USB2.0 stack
Microchip USB3440
FOSS Cores:
* Daisho - http://goo.gl/eSwTeb
* joris_vr - http://jorisvr.nl/usb/

License: CC-BY-SA 4.0 International
Designed in collaboration between Numato Lab and TimVideos.us
http://opsis.hdmi2usb.tv/
Sheet: /USB/ Numato Lab
File: USB.sch

Title: Numato Opsis - USB Peripheral and USB OTG


Do not populate DisplayPort Clock BringUp

Debug Serial / IO Header

$Id: 9a9ca4324895078ccb498cbf639d2fc9583618b1 $
License: CC-BY-SA 4.0 International
Designed in collaboration between Numato Lab and TimVideos.us
http://opsis.hdmi2usb.tv/
Sheet: /FPGA_Bank_0_3/ Numato Lab
File: FPGA_Bank_0_3.sch

Title: Numato Opsis - FPGA Bank 0 & 3


LDO OUT FOR TX2 HDMI OUT 2

$Id: c8eb19902c4bce2168841bbdcf0cde7df65a20ab $
License: CC-BY-SA 4.0 International
Designed in collaboration between Numato Lab and TimVideos.us
http://opsis.hdmi2usb.tv/
Title: Numato Opsis - HDMI File: HDMI.sch Sheet: /HDMI/ Numato Lab


$Id: 4a224b39b0a736d4d98fe7779e3f97adfd3e9422 $
License: CC-BY-SA 4.0 International
Designed in collaboration between Numato Lab and TimVideos.us
http://opsis.hdmi2usb.tv/
Sheet: /FPGA_Bank_1_2/ Numato Lab
File: FPGA_Bank_1_2.sch

Title: Numato Opsis - FPGA Bank 1 & 2

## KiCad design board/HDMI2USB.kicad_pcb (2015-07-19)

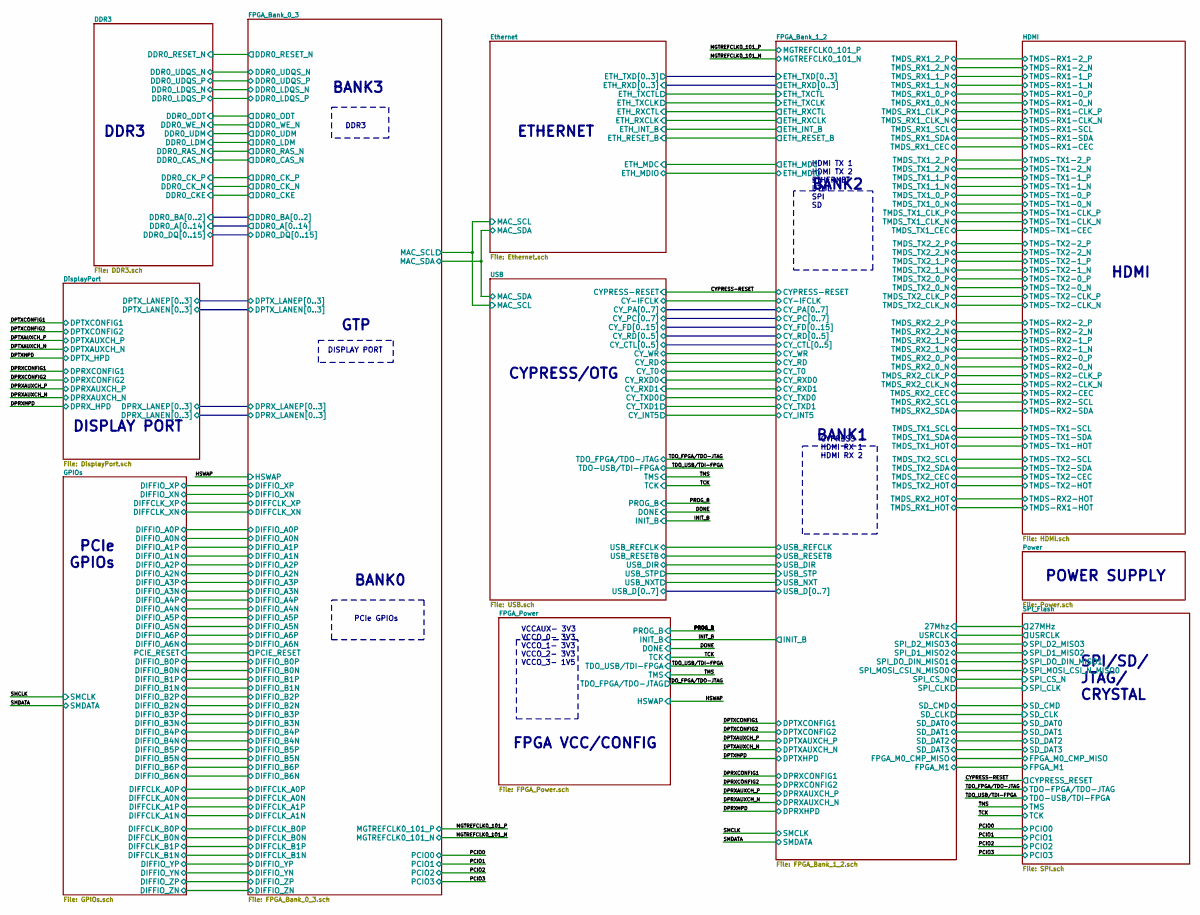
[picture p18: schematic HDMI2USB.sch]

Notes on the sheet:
HDMI
POWER SUPPLY
SPI/SD/ JTAG/ CRYSTAL
DISPLAY PORT
PCIe GPIOs
ETHERNET
CYPRESS/OTG
FPGA VCC/CONFIG
DDR3
BANK0
BANK3
BANK2
BANK1
PCIe GPIOs
GTP
CYPRESS HDMI RX 1 HDMI RX 2
HDMI TX 1 HDMI TX 2 ETHERNET UTMI SPI SD
VCCAUX- 3V3 VCCO_0- 3V3 VCCO_1- 3V3 VCCO_2- 3V3 VCCO_3- 1V5

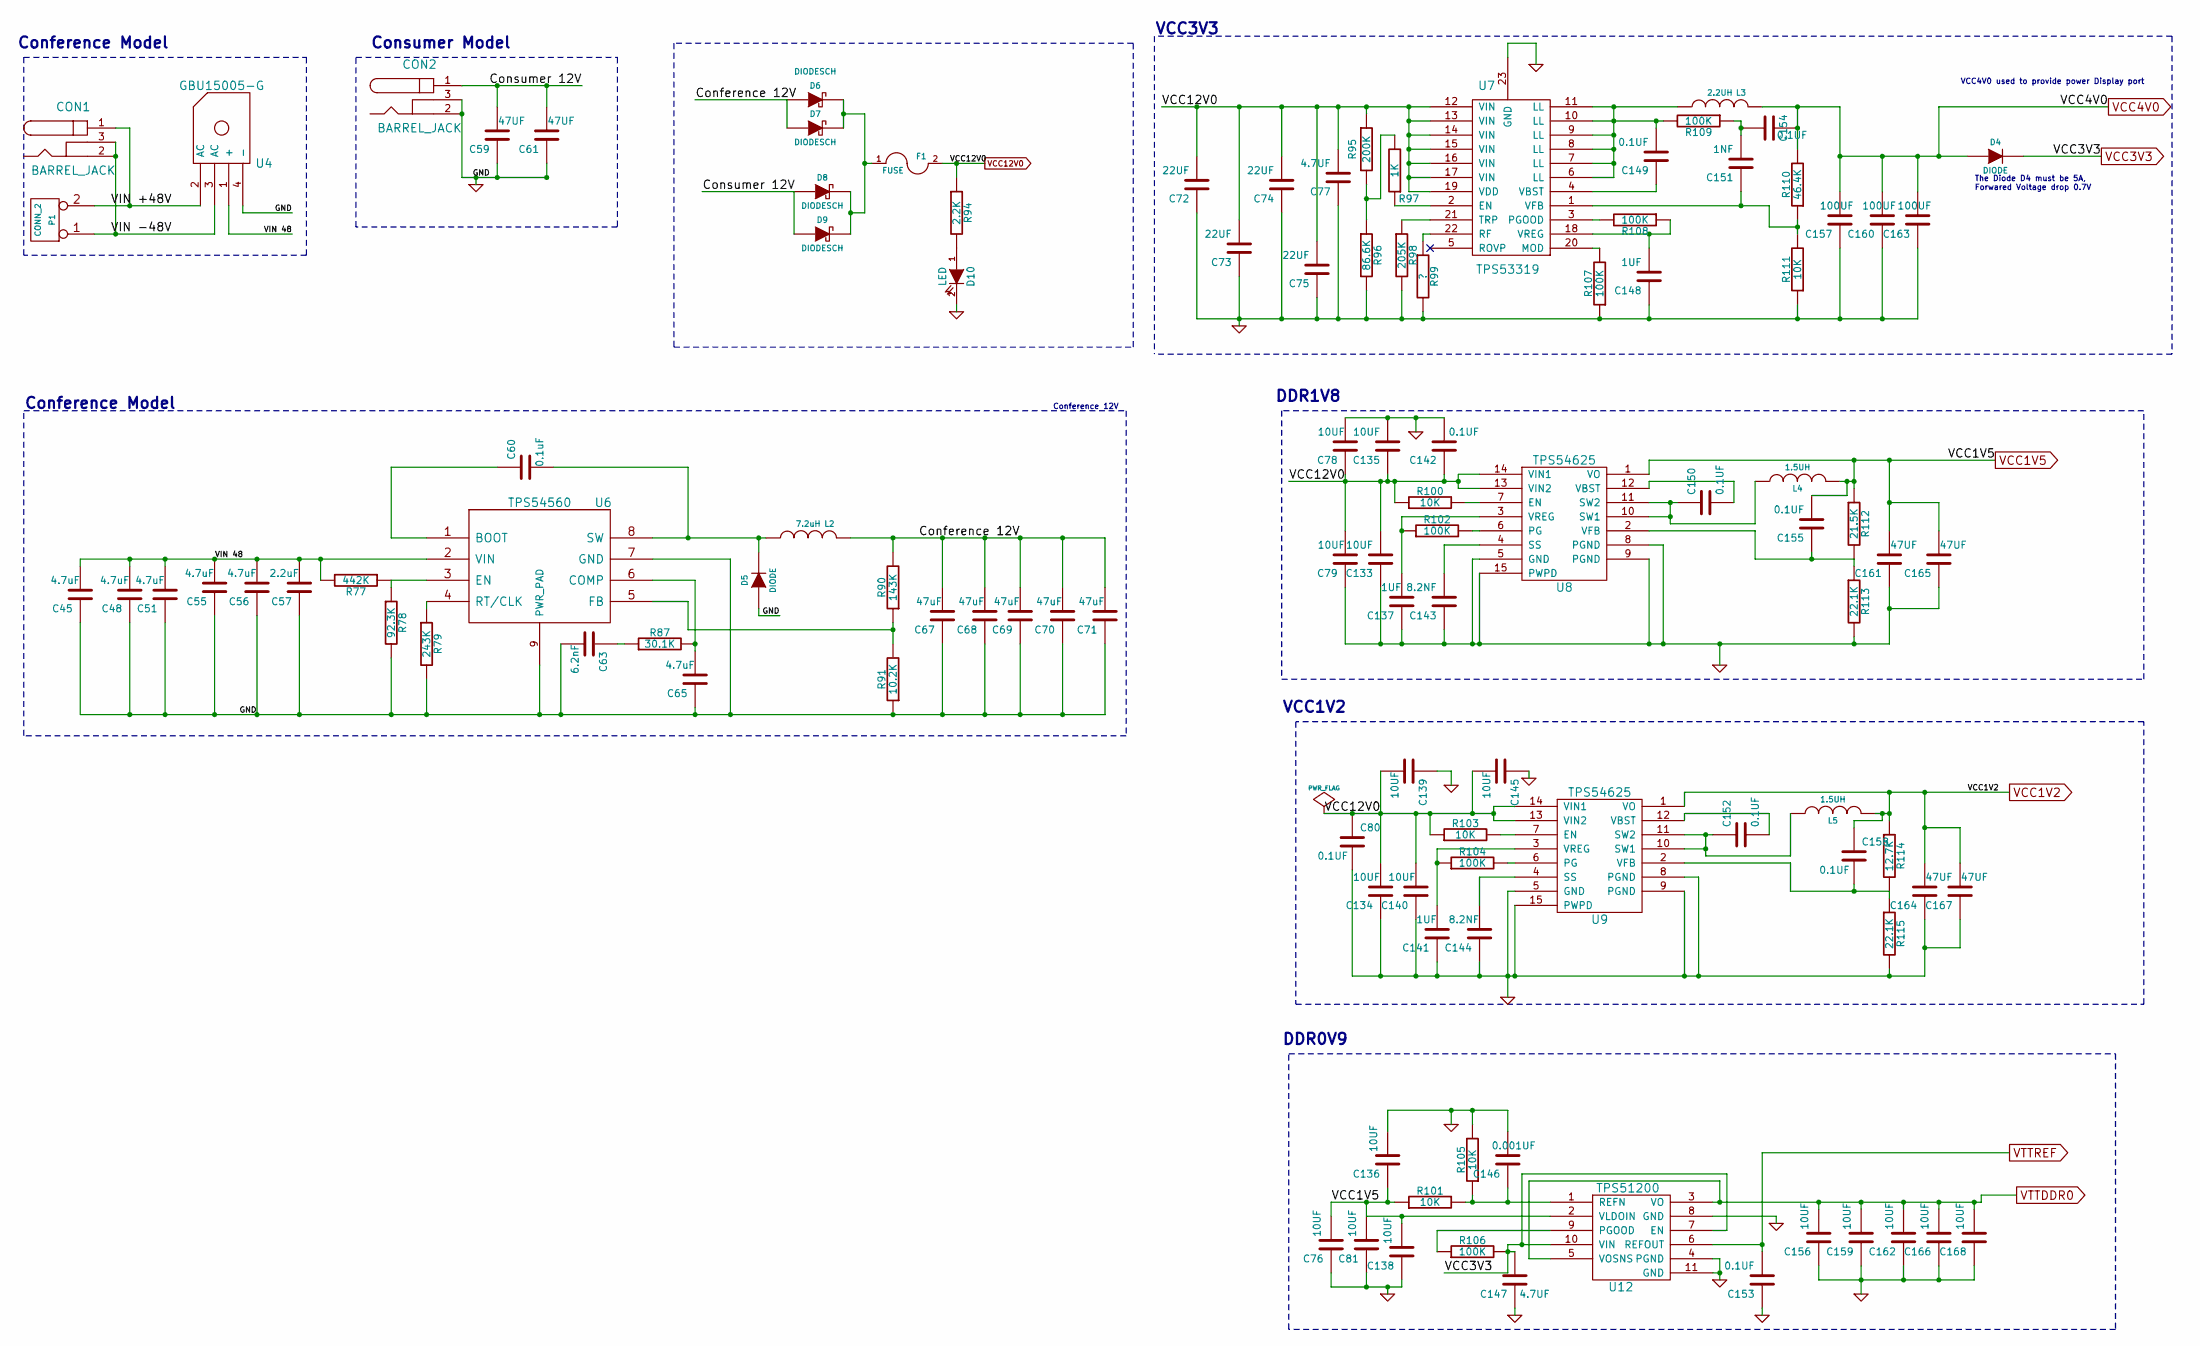
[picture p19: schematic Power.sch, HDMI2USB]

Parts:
C45, C48, C51, C55, C56, C65: 4.7uF
C57: 2.2uF
C59, C61, C161, C164, C165, C167: 47UF
C60: 0.1uF
C63: 6.2nF
C67, C68, C69, C70, C71: 47uF
C72, C73, C74, C75: 22UF
C76, C78, C79, C81, C133, C134, C135, C136, C138, C139, C140, C145, C156, C159, C162, C166, C168: 10UF
C77, C147: 4.7UF
C80, C142, C149, C150, C152, C153, C154, C155, C158: 0.1UF
C137, C141, C148: 1UF
C143, C144: 8.2NF
C146: 0.001UF
C151: 1NF
C157, C160, C163: 100UF
CON1, CON2: BARREL_JACK
D4, D5: DIODE
D6, D7, D8, D9: DIODESCH
D10: LED
F1: FUSE
L2: 7.2uH
L3: 2.2UH
L4, L5: 1.5UH
P1: CONN_2
R77: 442K
R78: 92.3K
R79: 243K
R87: 30.1K
R90: 143K
R91: 10.2K
R94: 2.2K
R95: 200K
R96: 86.6K
R97: 1K
R98: 205K
R99: ?
R100, R101, R103, R105, R111: 10K
R102, R104, R106, R107, R108, R109: 100K
R110: 46.4K
R112: 21.5K
R113, R115: 22.1K
R114: 12.7K
U4: GBU15005-G
U6: TPS54560
U7: TPS53319
U8, U9: TPS54625
U12: TPS51200

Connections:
/Power/Conference 12V: C67.2, C68.2, C69.2, C70.2, C71.2, D6.1 (A), D7.1 (A), L2.2, R90.2
/Power/Consumer 12V: C59.2, C61.2, CON2.1, D8.1 (A), D9.1 (A)
/Power/VIN 48: C45.2, C48.2, C51.2, C55.2, C56.2, C57.2, R77.2, U4.1 (+), U6.2 (VIN)
/Power/VIN +48V: CON1.1, P1.2 (PM), U4.2 (AC)
/Power/VIN -48V: CON1.2, CON1.3, P1.1, U4.3 (AC)
GND: C45.1, C48.1, C51.1, C55.1, C56.1, C57.1, C59.1, C61.1, C63.2, C65.1, C67.1, C68.1, C69.1, C70.1, C71.1, C72.1, C73.1, C74.1, C75.1, C76.1, C77.1, C78.2, C79.1, C80.2, C81.1, C133.1, C134.1, C135.2, C136.2, C137.1, C138.1, C139.1, C140.1, C141.1, C142.2, C143.1, C144.1, C145.1, C146.2, C147.1, C148.1, C153.1, C156.1, C157.1, C159.1, C160.1, C161.1, C162.1, C163.1, C164.1, C165.1, C166.1, C167.1, C168.1, CON2.2, CON2.3, D5.1 (A), D10.2 (K), R78.2, R79.2, R91.1, R96.2, R98.2, R99.2, R105.2, R107.1, R111.1, R113.2, R115.2, U4.4 (-), U6.7 (GND), U6.9 (PWR_PAD), U7.23 (GND), U8.5 (GND), U8.8 (PGND), U8.9 (PGND), U8.15 (PWPD), U9.5 (GND), U9.8 (PGND), U9.9 (PGND), U9.15 (PWPD), U12.4 (PGND), U12.8 (GND), U12.11 (GND); also elsewhere on the board
unnamed: C151.2, C154.2, R109.1
unnamed: C151.1, R110.1, R111.2, U7.1 (VFB)
unnamed: C146.1, R101.2, R105.1, U12.1 (REFN)
unnamed: R99.1, U7.22 (RF)
unnamed: C155.1, R112.2, R113.1, U8.2 (VFB)
unnamed: C158.2, R114.2, R115.1, U9.2 (VFB)
unnamed: C60.1, U6.1 (BOOT)
unnamed: R90.1, R91.2, U6.5 (FB)
unnamed: C65.2, R87.2, U6.6 (COMP)
unnamed: C152.1, L5.1, U9.10 (SW1), U9.11 (SW2)
unnamed: C144.2, U9.4 (SS)
unnamed: C141.2, R104.1, U9.3 (VREG)
unnamed: C150.1, L4.1, U8.10 (SW1), U8.11 (SW2)
unnamed: C150.2, U8.12 (VBST)
unnamed: R104.2, U9.6 (PG)
unnamed: C143.2, U8.4 (SS)
unnamed: C137.2, R102.1, U8.3 (VREG)
unnamed: R102.2, U8.6 (PG)
unnamed: R100.2, U8.7 (EN)
unnamed: C148.2, R108.1, U7.18 (VREG)
unnamed: R95.2, R96.1, R97.2
unnamed: R103.2, U9.7 (EN)
unnamed: R97.1, U7.2 (EN)
unnamed: R108.2, U7.3 (PGOOD)
unnamed: C149.1, U7.4 (VBST)
unnamed: C149.2, L3.1, R109.2, U7.6 (LL), U7.7 (LL), U7.8 (LL), U7.9 (LL), U7.10 (LL), U7.11 (LL)
unnamed: R107.2, U7.20 (MOD)
unnamed: R98.1, U7.21 (TRP)
unnamed: C152.2, U9.12 (VBST)
unnamed: C63.1, R87.1
unnamed: C60.2, D5.2 (K), L2.1, U6.8 (SW)
unnamed: R77.1, R78.1, U6.3 (EN)
unnamed: R79.1, U6.4 (RT/CLK)
unnamed: D6.2 (K), D7.2 (K), D8.2 (K), D9.2 (K), F1.1
unnamed: R106.1, U12.9 (PGOOD)
unnamed: D10.1 (A), R94.2
VCC1V2: C158.1, C164.2, C167.2, L5.2, R114.1, U9.1 (VO); also elsewhere on the board
VCC1V5: C76.2, C81.2, C136.1, C138.2, C155.2, C161.2, C165.2, L4.2, R101.1, R112.1, U8.1 (VO), U12.2 (VLDOIN); also elsewhere on the board
VCC3V3: C147.2, D4.2 (K), R106.2, U12.7 (EN), U12.10 (VIN); also elsewhere on the board
VCC4V0: C154.1, C157.2, C160.2, C163.2, D4.1 (A), L3.2, R110.2; also elsewhere on the board
VCC12V0: C72.2, C73.2, C74.2, C75.2, C77.2, C78.1, C79.2, C80.1, C133.2, C134.2, C135.1, C139.2, C140.2, C142.1, C145.2, F1.2, R94.1, R95.1, R100.1, R103.1, U7.12 (VIN), U7.13 (VIN), U7.14 (VIN), U7.15 (VIN), U7.16 (VIN), U7.17 (VIN), U7.19 (VDD), U8.13 (VIN2), U8.14 (VIN1), U9.13 (VIN2), U9.14 (VIN1); also elsewhere on the board
VTTDDR0: C156.2, C159.2, C162.2, C166.2, C168.2, U12.3 (VO), U12.5 (VOSNS); also elsewhere on the board
VTTREF: C153.2, U12.6 (REFOUT)

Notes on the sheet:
VCC3V3
DDR1V8
VCC1V2
DDR0V9
Consumer Model
Conference Model
Conference 12V
VCC4V0 used to provide power Display port
The Diode D4 must be 5A, Forwared Voltage drop 0.7V

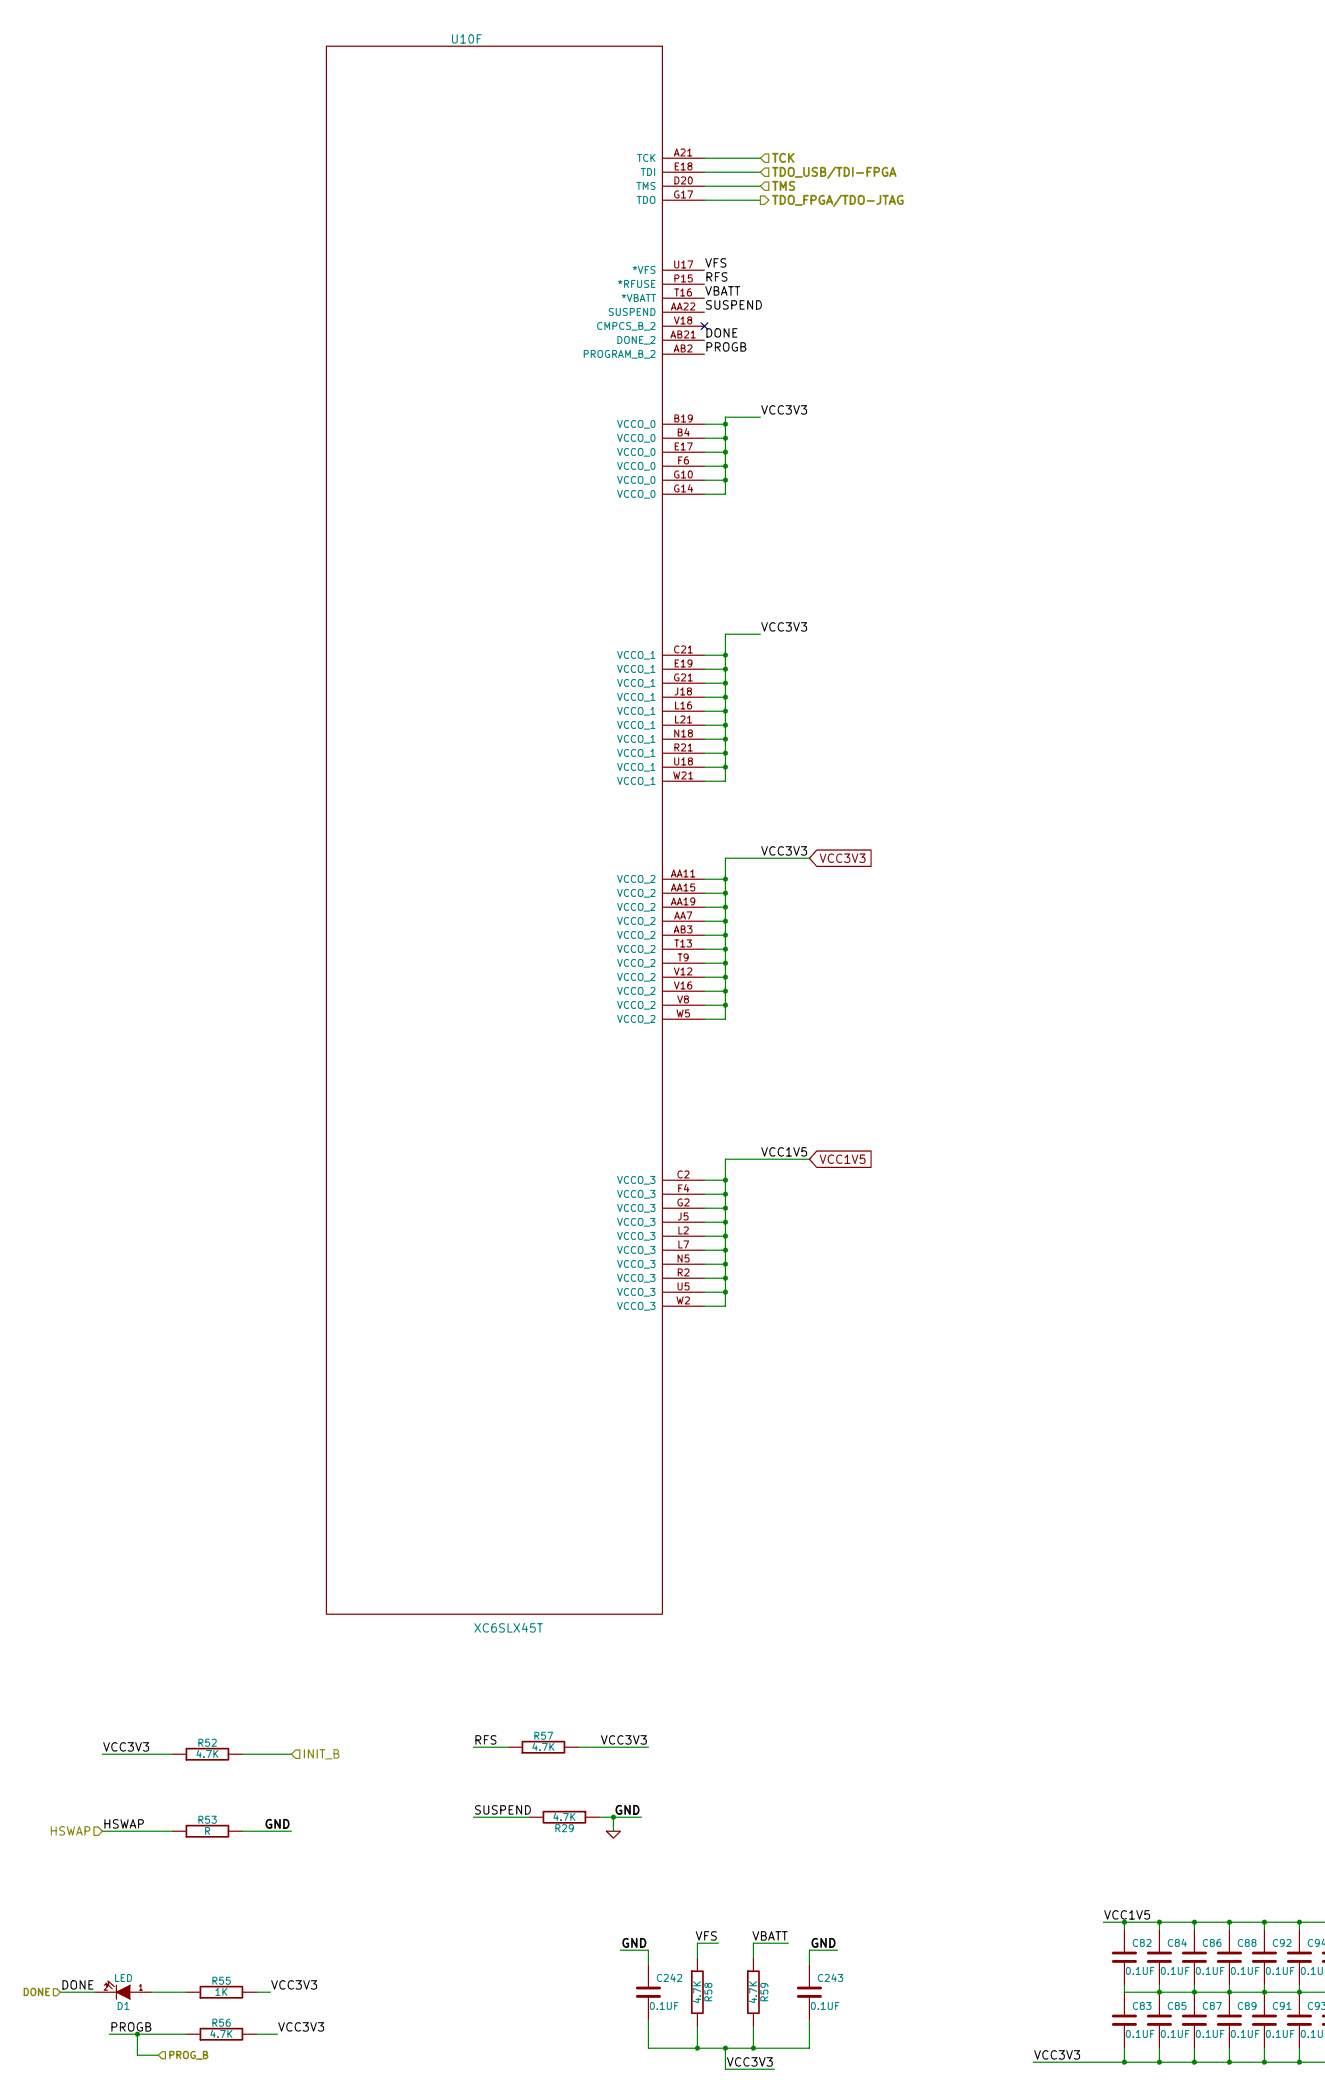
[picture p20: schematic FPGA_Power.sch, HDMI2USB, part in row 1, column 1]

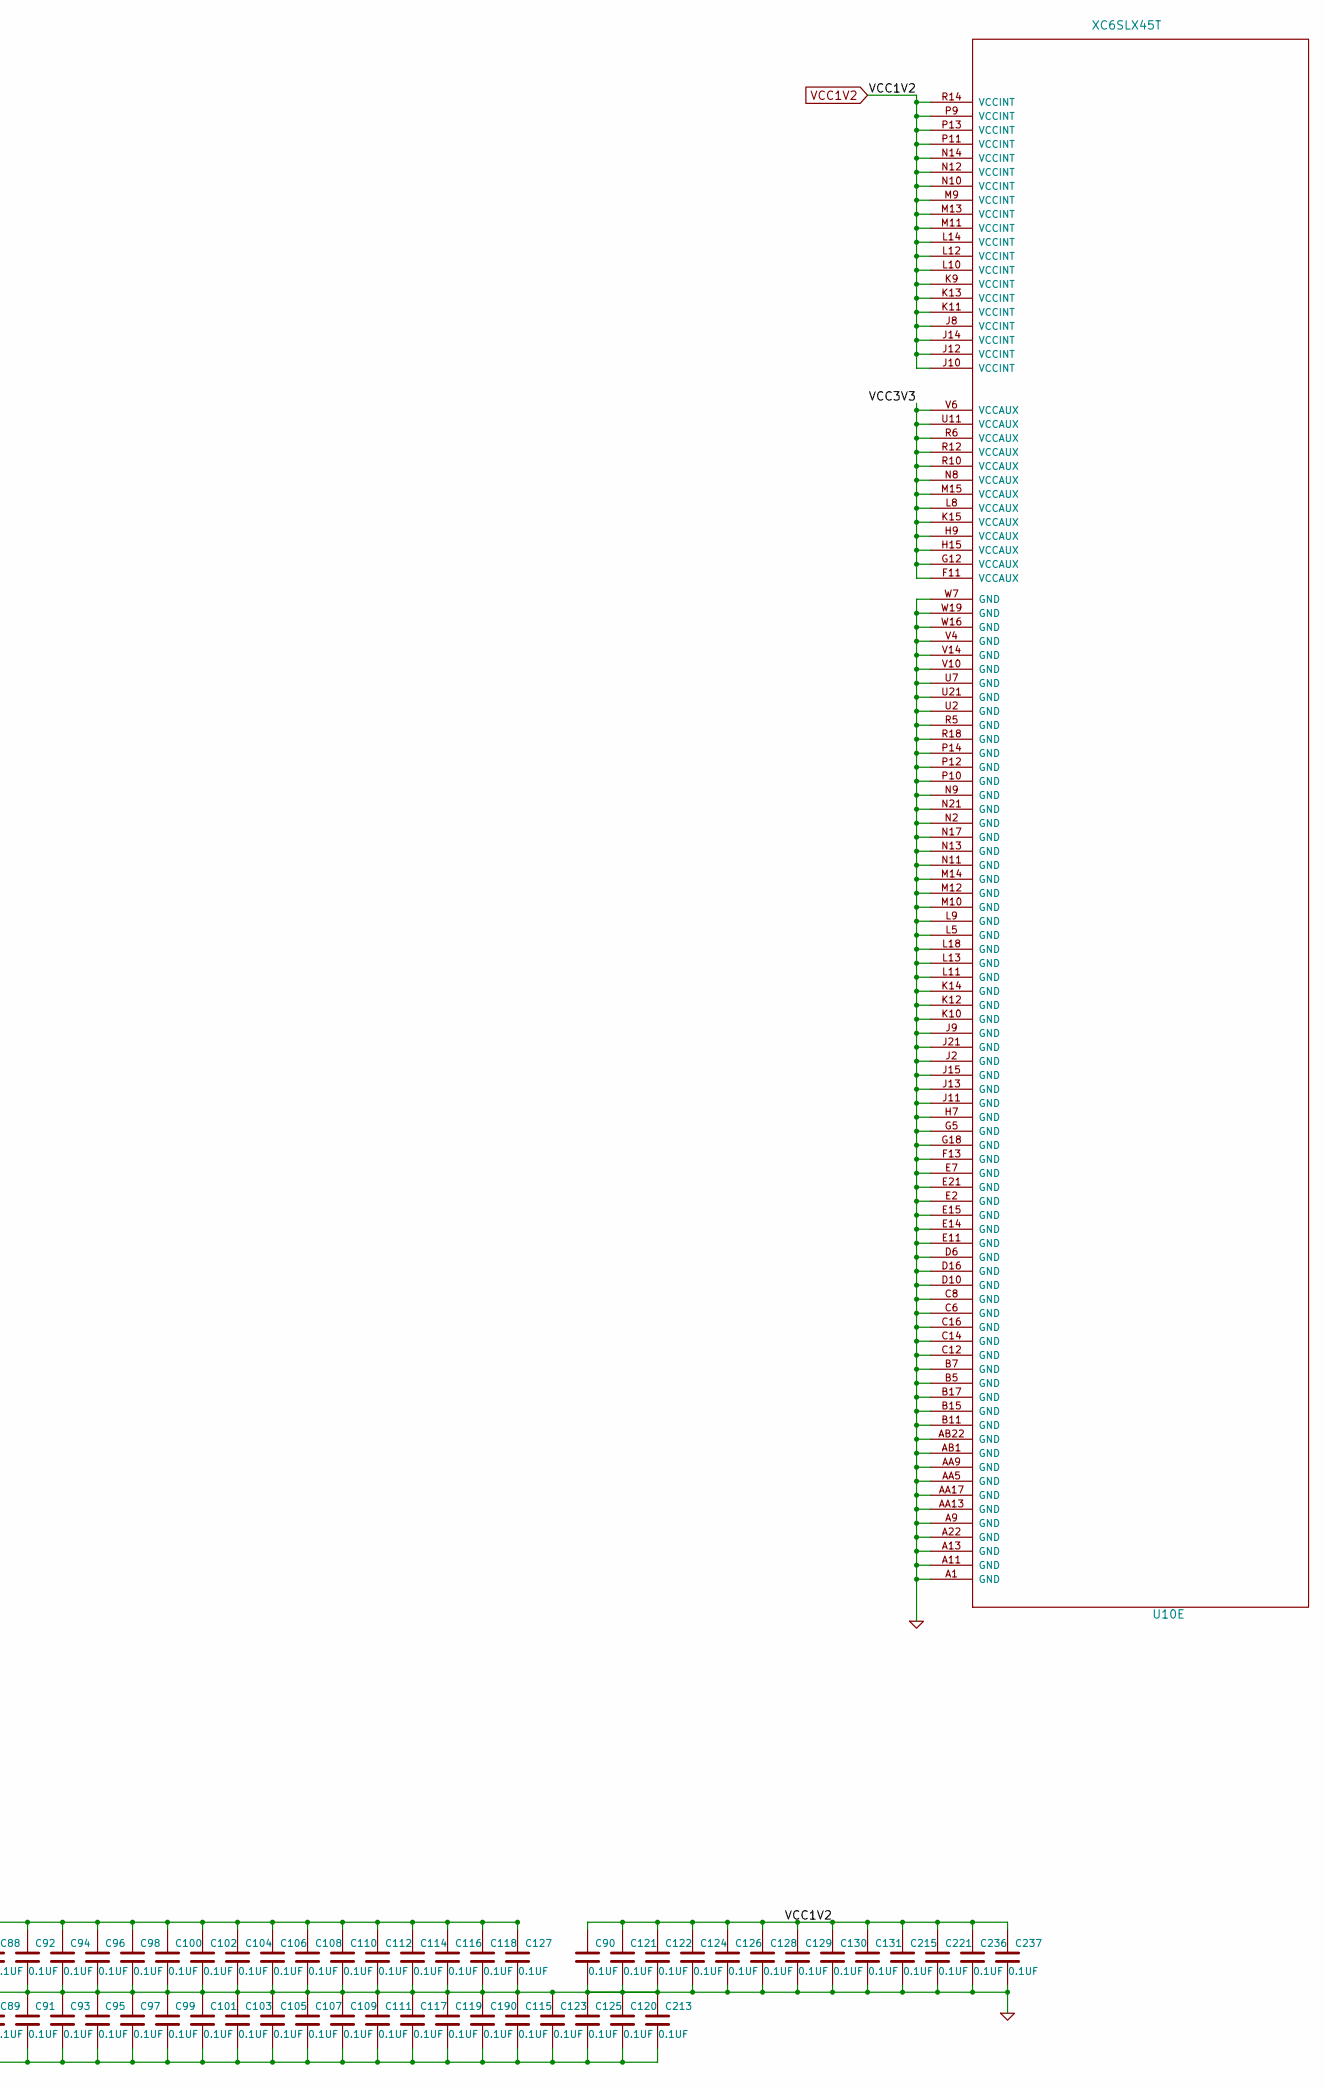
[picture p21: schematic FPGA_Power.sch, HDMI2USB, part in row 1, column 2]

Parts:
C82, C83, C84, C85, C86, C87, C88, C89, C90, C91, C92, C93, C94, C95, C96, C97, C98, C99, C100, C101, C102, C103, C104, C105, C106, C107, C108, C109, C110, C111, C112, C114, C115, C116, C117, C118, C119, C120, C121, C122, C123, C124, C125, C126, C127, C128, C129, C130, C131, C190, C213, C215, C221, C236, C237, C242, C243: 0.1UF
D1: LED
R29, R52, R56, R57: 4.7K
R53: R
R55: 1K
R58, R59: 4.7K
U10: XC6SLX45T

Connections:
/FPGA_Bank_0_3/HSWAP: R53.1; also elsewhere on the board
/FPGA_Bank_1_2/INIT_B: R52.2; also elsewhere on the board
/FPGA_Power/DONE: D1.2 (K), U10.AB21 (DONE_2); also elsewhere on the board
/FPGA_Power/PROG_B: R56.1, U10.AB2 (PROGRAM_B_2); also elsewhere on the board
/FPGA_Power/RFS: R57.1, U10.P15 (*RFUSE)
/FPGA_Power/SUSPEND: R29.2, U10.AA22 (SUSPEND)
/FPGA_Power/TCK: U10.A21 (TCK); also elsewhere on the board
/FPGA_Power/TMS: U10.D20 (TMS); also elsewhere on the board
/FPGA_Power/VBATT: R59.1, U10.T16 (*VBATT)
/FPGA_Power/VFS: R58.1, U10.U17 (*VFS)
/SPI_Flash/TDO-FPGA/TDO-JTAG: U10.G17 (TDO); also elsewhere on the board
/SPI_Flash/TDO-USB/TDI-FPGA: U10.E18 (TDI); also elsewhere on the board
GND: C82.2, C83.1, C84.2, C85.1, C86.2, C87.1, C88.2, C89.1, C90.2, C91.1, C92.2, C93.1, C94.2, C95.1, C96.2, C97.1, C98.2, C99.1, C100.2, C101.1, C102.2, C103.1, C104.2, C105.1, C106.2, C107.1, C108.2, C109.1, C110.2, C111.1, C112.2, C114.2, C115.1, C116.2, C117.1, C118.2, C119.1, C120.1, C121.2, C122.2, C123.1, C124.2, C125.1, C126.2, C127.2, C128.2, C129.2, C130.2, C131.2, C190.1, C213.1, C215.2, C221.2, C236.2, C237.2, C242.1, C243.1, R29.1, R53.2, U10.A1 (GND), U10.A9 (GND), U10.A11 (GND), U10.A13 (GND), U10.A22 (GND), U10.AA5 (GND), U10.AA9 (GND), U10.AA13 (GND), U10.AA17 (GND), U10.AB1 (GND), U10.AB22 (GND), U10.B5 (GND), U10.B7 (GND), U10.B11 (GND), U10.B15 (GND), U10.B17 (GND), U10.C6 (GND), U10.C8 (GND), U10.C12 (GND), U10.C14 (GND), U10.C16 (GND), U10.D6 (GND), U10.D10 (GND), U10.D16 (GND), U10.E2 (GND), U10.E7 (GND), U10.E11 (GND), U10.E14 (GND), U10.E15 (GND), U10.E21 (GND), U10.F13 (GND), U10.G5 (GND), U10.G18 (GND), U10.H7 (GND), U10.J2 (GND), U10.J9 (GND), U10.J11 (GND), U10.J13 (GND), U10.J15 (GND), U10.J21 (GND), U10.K10 (GND), U10.K12 (GND), U10.K14 (GND), U10.L5 (GND), U10.L9 (GND), U10.L11 (GND), U10.L13 (GND), U10.L18 (GND), U10.M10 (GND), U10.M12 (GND), U10.M14 (GND), U10.N2 (GND), U10.N9 (GND), U10.N11 (GND), U10.N13 (GND), U10.N17 (GND), U10.N21 (GND), U10.P10 (GND), U10.P12 (GND), U10.P14 (GND), U10.R5 (GND), U10.R18 (GND), U10.U2 (GND), U10.U7 (GND), U10.U21 (GND), U10.V4 (GND), U10.V10 (GND), U10.V14 (GND), U10.W7 (GND), U10.W16 (GND), U10.W19 (GND); also elsewhere on the board
unnamed: D1.1 (A), R55.1
VCC1V2: C90.1, C121.1, C122.1, C124.1, C126.1, C128.1, C129.1, C130.1, C131.1, C215.1, C221.1, C236.1, C237.1, U10.J8 (VCCINT), U10.J10 (VCCINT), U10.J12 (VCCINT), U10.J14 (VCCINT), U10.K9 (VCCINT), U10.K11 (VCCINT), U10.K13 (VCCINT), U10.L10 (VCCINT), U10.L12 (VCCINT), U10.L14 (VCCINT), U10.M9 (VCCINT), U10.M11 (VCCINT), U10.M13 (VCCINT), U10.N10 (VCCINT), U10.N12 (VCCINT), U10.N14 (VCCINT), U10.P9 (VCCINT), U10.P11 (VCCINT), U10.P13 (VCCINT), U10.R14 (VCCINT); also elsewhere on the board
VCC1V5: C82.1, C84.1, C86.1, C88.1, C92.1, C94.1, C96.1, C98.1, C100.1, C102.1, C104.1, C106.1, C108.1, C110.1, C112.1, C114.1, C116.1, C118.1, C127.1, U10.C2 (VCCO_3), U10.F4 (VCCO_3), U10.G2 (VCCO_3), U10.J5 (VCCO_3), U10.L2 (VCCO_3), U10.L7 (VCCO_3), U10.N5 (VCCO_3), U10.R2 (VCCO_3), U10.U5 (VCCO_3), U10.W2 (VCCO_3); also elsewhere on the board
VCC3V3: C83.2, C85.2, C87.2, C89.2, C91.2, C93.2, C95.2, C97.2, C99.2, C101.2, C103.2, C105.2, C107.2, C109.2, C111.2, C115.2, C117.2, C119.2, C120.2, C123.2, C125.2, C190.2, C213.2, C242.2, C243.2, R52.1, R55.2, R56.2, R57.2, R58.2, R59.2, U10.AA7 (VCCO_2), U10.AA11 (VCCO_2), U10.AA15 (VCCO_2), U10.AA19 (VCCO_2), U10.AB3 (VCCO_2), U10.B4 (VCCO_0), U10.B19 (VCCO_0), U10.C21 (VCCO_1), U10.E17 (VCCO_0), U10.E19 (VCCO_1), U10.F6 (VCCO_0), U10.F11 (VCCAUX), U10.G10 (VCCO_0), U10.G12 (VCCAUX), U10.G14 (VCCO_0), U10.G21 (VCCO_1), U10.H9 (VCCAUX), U10.H15 (VCCAUX), U10.J18 (VCCO_1), U10.K15 (VCCAUX), U10.L8 (VCCAUX), U10.L16 (VCCO_1), U10.L21 (VCCO_1), U10.M15 (VCCAUX), U10.N8 (VCCAUX), U10.N18 (VCCO_1), U10.R6 (VCCAUX), U10.R10 (VCCAUX), U10.R12 (VCCAUX), U10.R21 (VCCO_1), U10.T9 (VCCO_2), U10.T13 (VCCO_2), U10.U11 (VCCAUX), U10.U18 (VCCO_1), U10.V6 (VCCAUX), U10.V8 (VCCO_2), U10.V12 (VCCO_2), U10.V16 (VCCO_2), U10.W5 (VCCO_2), U10.W21 (VCCO_1); also elsewhere on the board

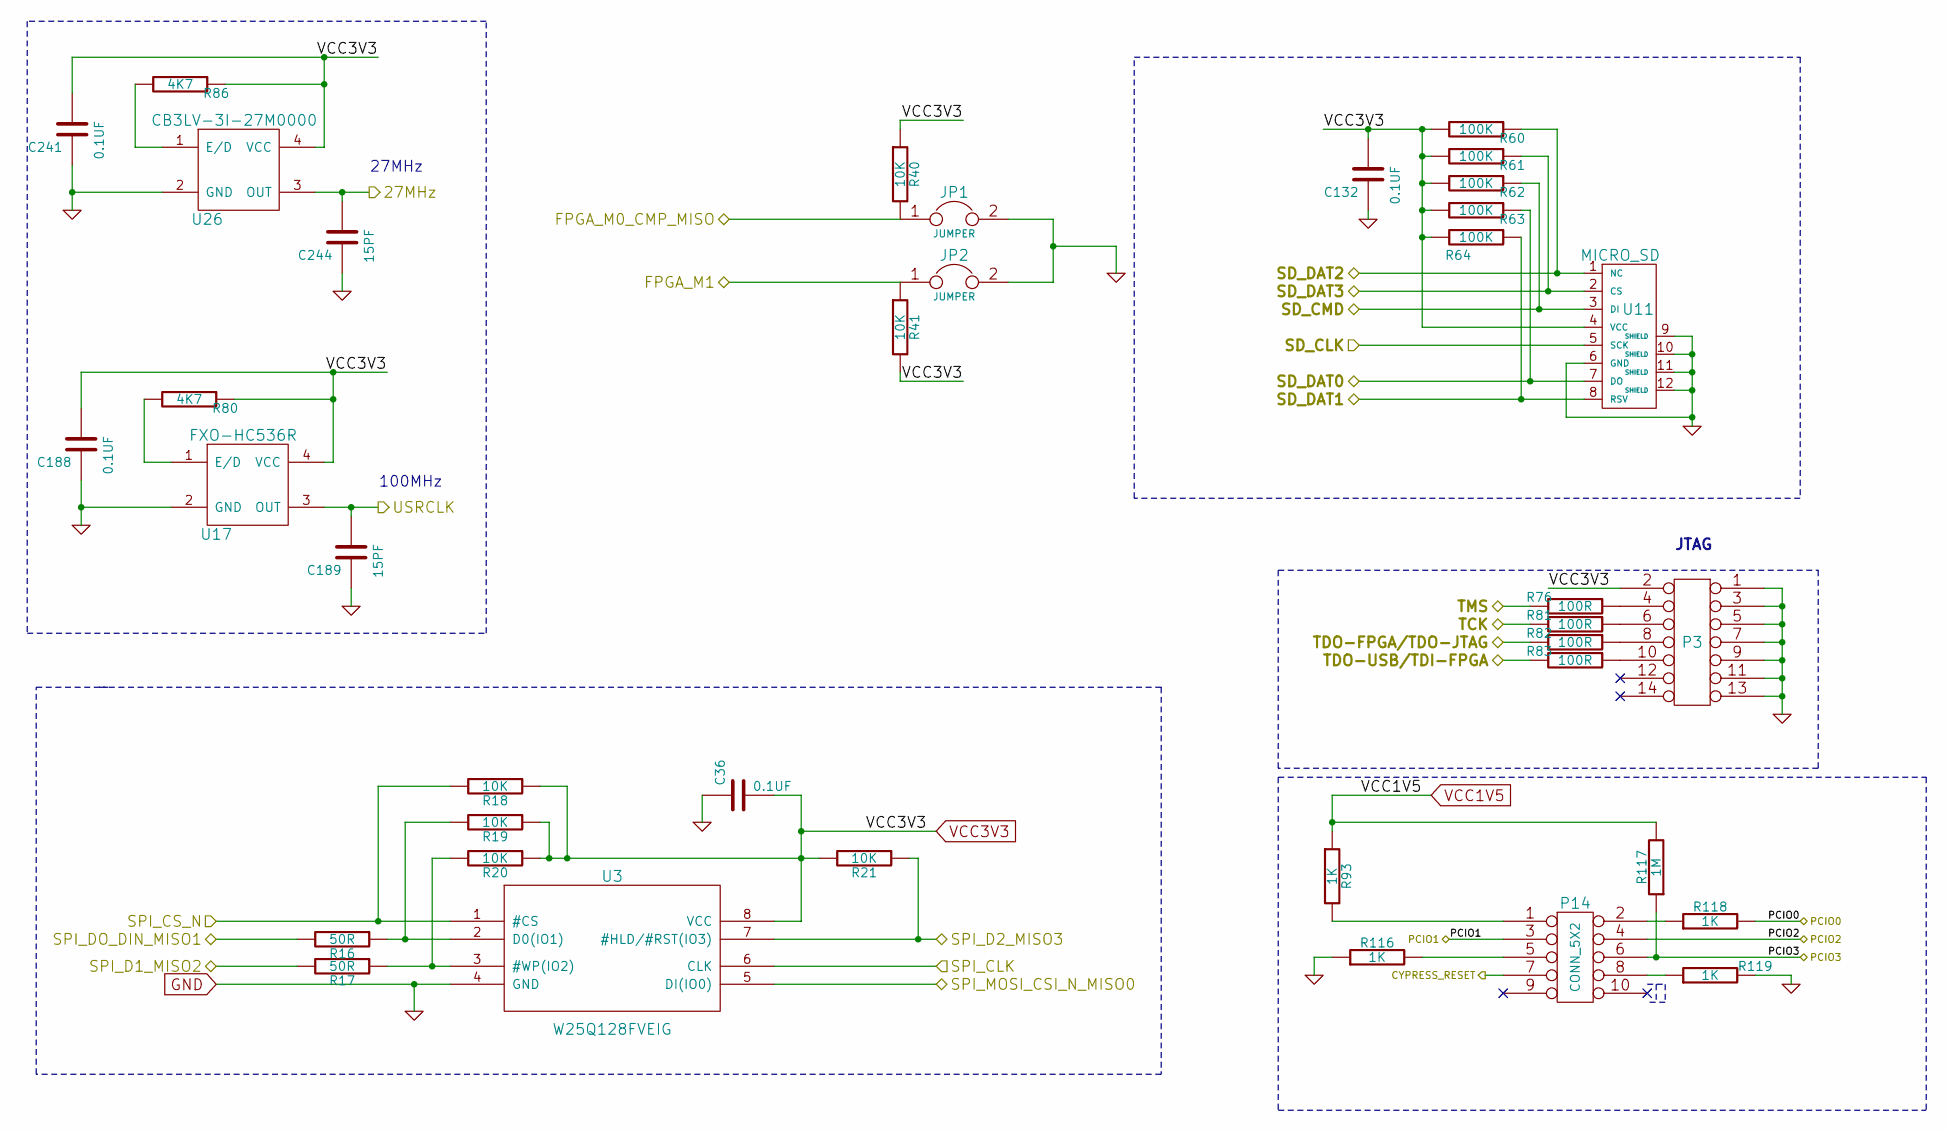
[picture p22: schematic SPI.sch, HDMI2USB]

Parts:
C36, C132, C188, C241: 0.1UF
C189, C244: 15PF
JP1, JP2: JUMPER
P3: CONN_7X2
P14: CONN_5X2
R16, R17: 50R
R18, R19, R20, R21, R40, R41: 10K
R60, R61, R62, R63, R64: 100K
R76, R81, R82, R83: 100R
R80, R86: 4K7
R93, R116, R118, R119: 1K
R117: 1M
U3: W25Q128FVEIG
U11: MICRO_SD
U17: FXO-HC536R
U26: CB3LV-3I-27M0000

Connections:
/FPGA_Bank_0_3/PCIO0: R118.2; also elsewhere on the board
/FPGA_Bank_0_3/PCIO1: P14.3; also elsewhere on the board
/FPGA_Bank_0_3/PCIO2: P14.4; also elsewhere on the board
/FPGA_Bank_0_3/PCIO3: P14.6, R117.1; also elsewhere on the board
/FPGA_Bank_1_2/CYPRESS-RESET: P14.7; also elsewhere on the board
/FPGA_Bank_1_2/FPGA_M0_CMP_MISO: JP1.1, R40.2; also elsewhere on the board
/FPGA_Bank_1_2/FPGA_M1: JP2.1, R41.1; also elsewhere on the board
/FPGA_Bank_1_2/SD_CLK: U11.5 (SCK); also elsewhere on the board
/FPGA_Bank_1_2/SD_CMD: R62.1, U11.3 (DI); also elsewhere on the board
/FPGA_Bank_1_2/SD_DAT0: R63.1, U11.7 (DO); also elsewhere on the board
/FPGA_Bank_1_2/SD_DAT1: R64.1, U11.8 (RSV); also elsewhere on the board
/FPGA_Bank_1_2/SD_DAT2: R60.1, U11.1 (NC); also elsewhere on the board
/FPGA_Bank_1_2/SD_DAT3: R61.1, U11.2 (CS); also elsewhere on the board
/FPGA_Bank_1_2/SPI_CLK: U3.6 (CLK); also elsewhere on the board
/FPGA_Bank_1_2/SPI_CS_N: R18.2, U3.1 (#CS); also elsewhere on the board
/FPGA_Bank_1_2/SPI_D1_MISO2: R17.2; also elsewhere on the board
/FPGA_Bank_1_2/SPI_D2_MISO3: R21.1, U3.7 (#HLD/#RST(IO3)); also elsewhere on the board
/FPGA_Bank_1_2/SPI_DO_DIN_MISO1: R16.2; also elsewhere on the board
/FPGA_Bank_1_2/SPI_MOSI_CSI_N_MISO0: U3.5 (DI(IO0)); also elsewhere on the board
/FPGA_Bank_1_2/USRCLK: C189.2, U17.3 (OUT); also elsewhere on the board
/FPGA_Power/TCK: R81.2; also elsewhere on the board
/FPGA_Power/TMS: R76.2; also elsewhere on the board
/SPI_Flash/27MHz: C244.2, U26.3 (OUT); also elsewhere on the board
/SPI_Flash/TDO-FPGA/TDO-JTAG: R82.2; also elsewhere on the board
/SPI_Flash/TDO-USB/TDI-FPGA: R83.2; also elsewhere on the board
GND: C36.1, C132.1, C188.1, C189.1, C241.1, C244.1, JP1.2, JP2.2, P3.1, P3.3, P3.5, P3.7, P3.9, P3.11, P3.13, R116.1, R119.2, U3.4 (GND), U11.6 (GND), U11.9 (SHIELD), U11.10 (SHIELD), U11.11 (SHIELD), U11.12 (SHIELD), U17.2 (GND), U26.2 (GND); also elsewhere on the board
unnamed: R80.2, U17.1 (E/D)
unnamed: R17.1, R20.2, U3.3 (#WP(IO2))
unnamed: P3.10, R83.1
unnamed: P3.8, R82.1
unnamed: P3.4, R76.1
unnamed: P3.6, R81.1
unnamed: R16.1, R19.2, U3.2 (D0(IO1))
unnamed: P14.1, R93.2
unnamed: P14.2, R118.1
unnamed: P14.8, R119.1
unnamed: P14.5, R116.2
unnamed: R86.2, U26.1 (E/D)
VCC1V5: R93.1, R117.2; also elsewhere on the board
VCC3V3: C36.2, C132.2, C188.2, C241.2, P3.2, R18.1, R19.1, R20.1, R21.2, R40.1, R41.2, R60.2, R61.2, R62.2, R63.2, R64.2, R80.1, R86.1, U3.8 (VCC), U11.4 (VCC), U17.4 (VCC), U26.4 (VCC); also elsewhere on the board

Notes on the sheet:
JTAG
100MHz
27MHz

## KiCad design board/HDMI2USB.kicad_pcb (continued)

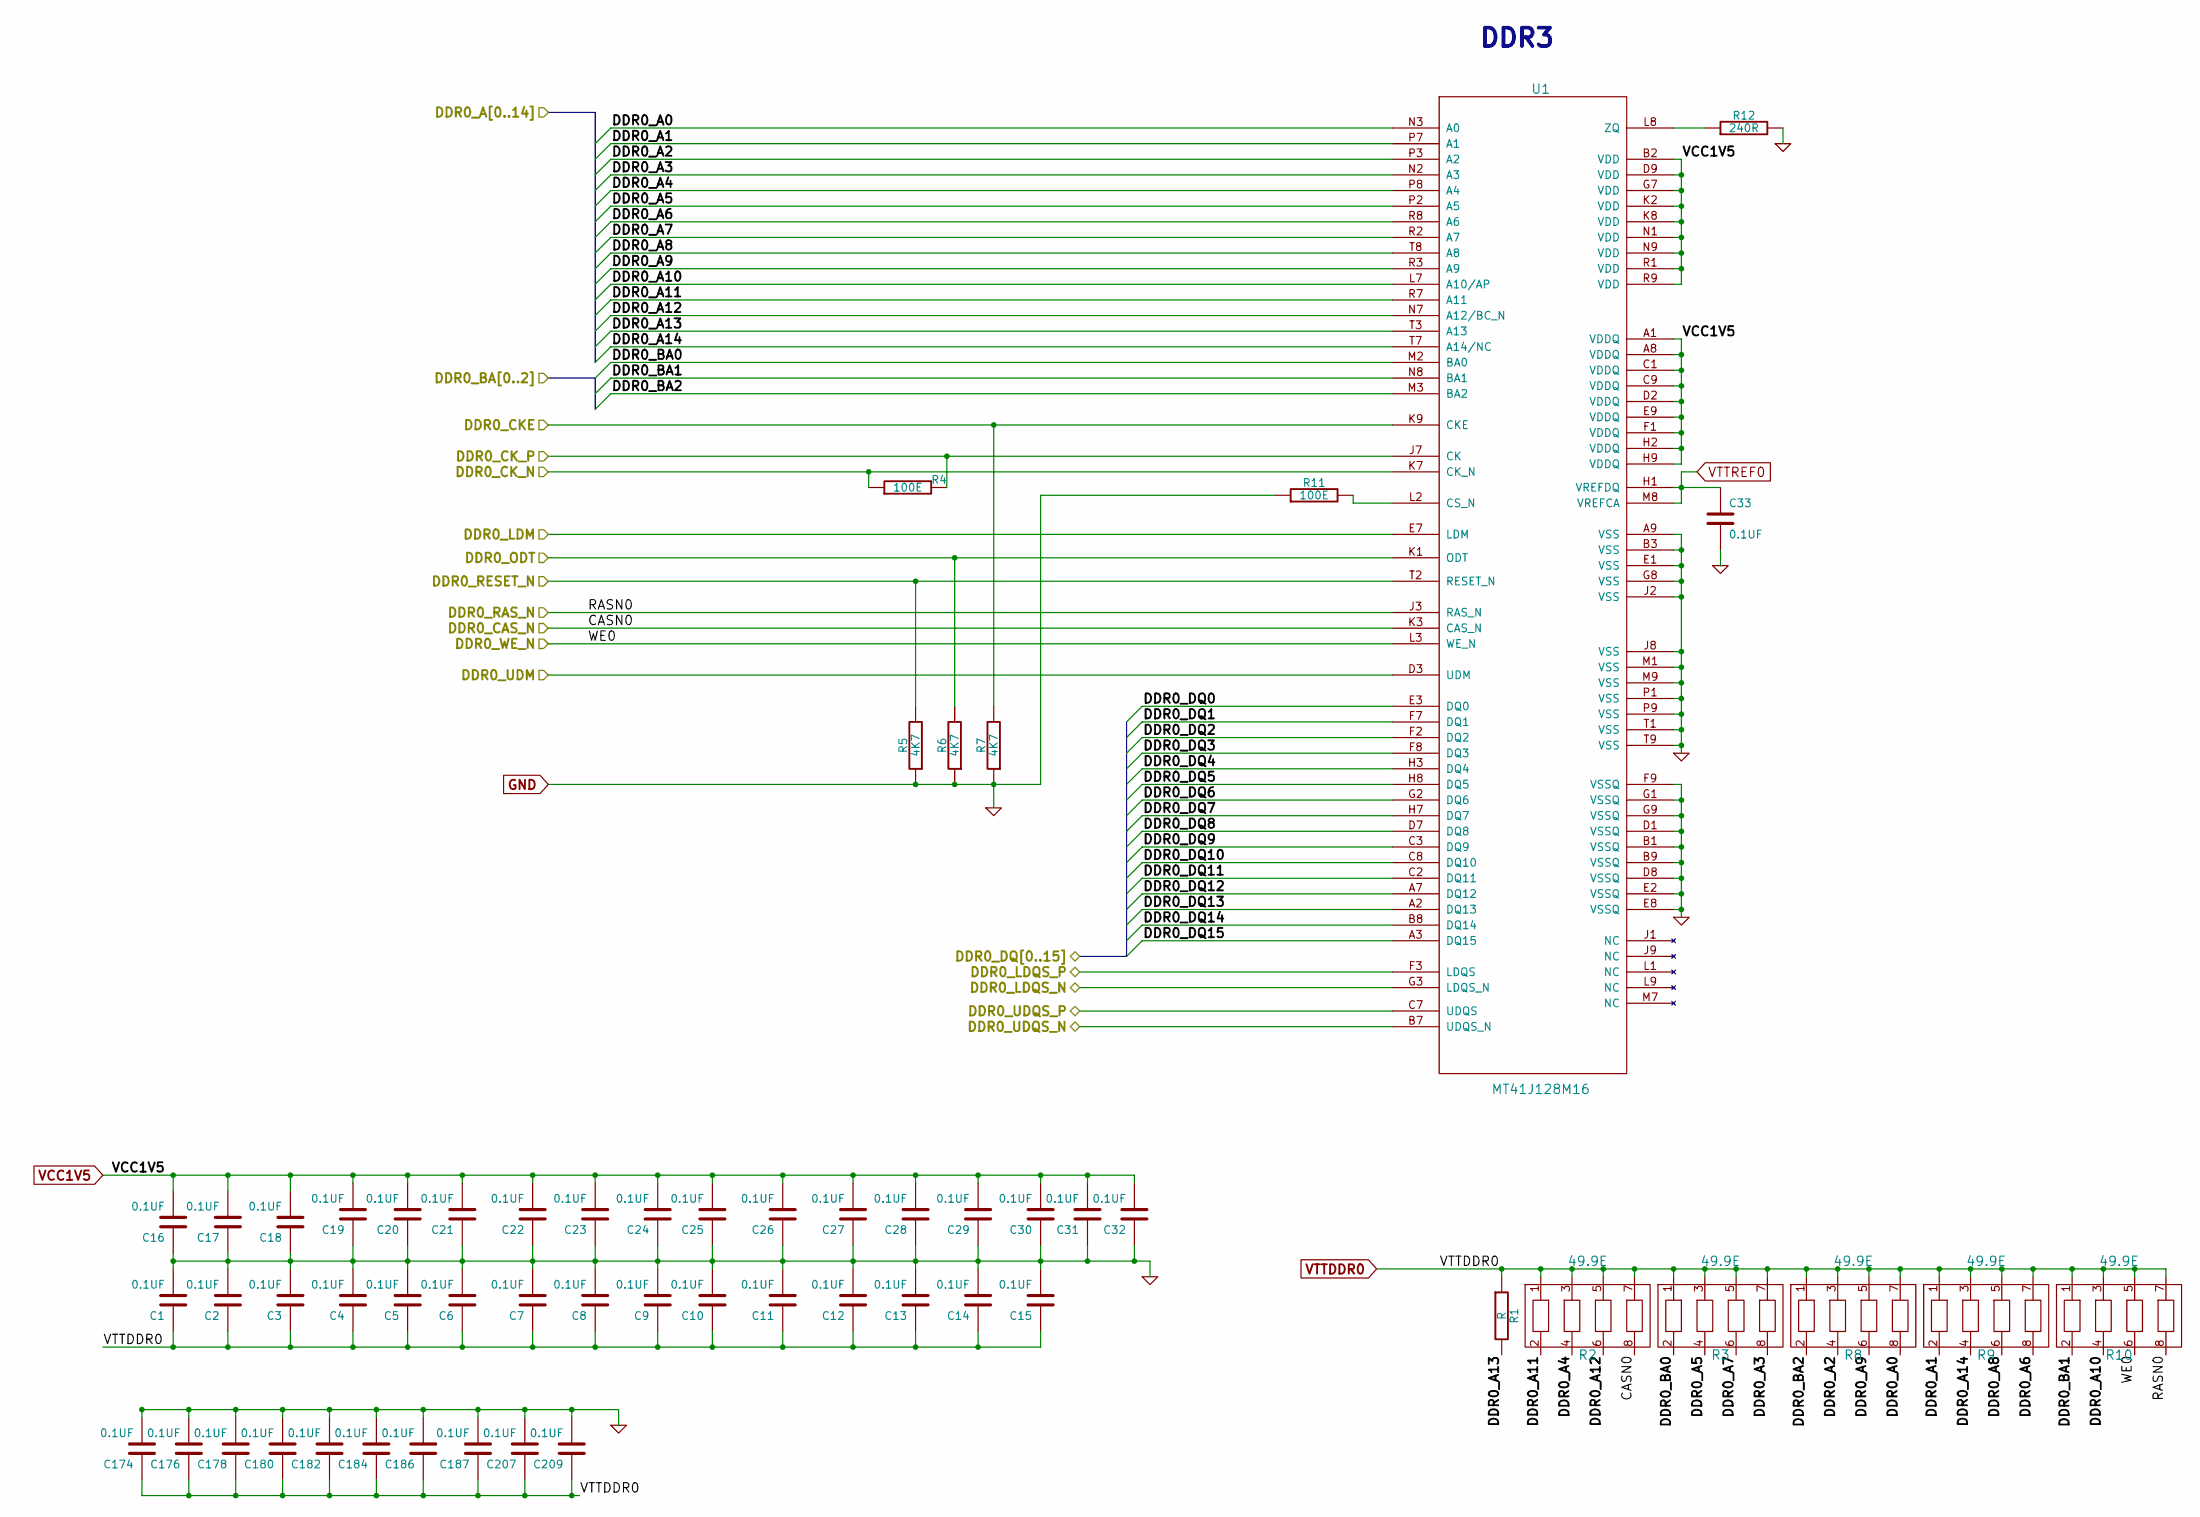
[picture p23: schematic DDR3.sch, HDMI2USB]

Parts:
C1, C2, C3, C4, C5, C6, C7, C8, C9, C10, C11, C12, C13, C14, C15, C16, C17, C18, C19, C20, C21, C22, C23, C24, C25, C26, C27, C28, C29, C30, C31, C32, C33, C174, C176, C178, C180, C182, C184, C186, C187, C207, C209: 0.1UF
R1: R
R2, R3, R8, R9, R10: 49.9E
R4, R11: 100E
R5, R6, R7: 4K7
R12: 240R
U1: MT41J128M16

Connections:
/DDR3/DDR0_A0: R8.8, U1.N3 (A0); also elsewhere on the board
/DDR3/DDR0_A1: R9.2, U1.P7 (A1); also elsewhere on the board
/DDR3/DDR0_A2: R8.4, U1.P3 (A2); also elsewhere on the board
/DDR3/DDR0_A3: R3.8, U1.N2 (A3); also elsewhere on the board
/DDR3/DDR0_A4: R2.4, U1.P8 (A4); also elsewhere on the board
/DDR3/DDR0_A5: R3.4, U1.P2 (A5); also elsewhere on the board
/DDR3/DDR0_A6: R9.8, U1.R8 (A6); also elsewhere on the board
/DDR3/DDR0_A7: R3.6, U1.R2 (A7); also elsewhere on the board
/DDR3/DDR0_A8: R9.6, U1.T8 (A8); also elsewhere on the board
/DDR3/DDR0_A9: R8.6, U1.R3 (A9); also elsewhere on the board
/DDR3/DDR0_A10: R10.4, U1.L7 (A10/AP); also elsewhere on the board
/DDR3/DDR0_A11: R2.2, U1.R7 (A11); also elsewhere on the board
/DDR3/DDR0_A12: R2.6, U1.N7 (A12/BC_N); also elsewhere on the board
/DDR3/DDR0_A13: R1.2, U1.T3 (A13); also elsewhere on the board
/DDR3/DDR0_A14: R9.4, U1.T7 (A14/NC); also elsewhere on the board
/DDR3/DDR0_BA0: R3.2, U1.M2 (BA0); also elsewhere on the board
/DDR3/DDR0_BA1: R10.2, U1.N8 (BA1); also elsewhere on the board
/DDR3/DDR0_BA2: R8.2, U1.M3 (BA2); also elsewhere on the board
/DDR3/DDR0_CAS_N: R2.8, U1.K3 (CAS_N); also elsewhere on the board
/DDR3/DDR0_CKE: R7.2, U1.K9 (CKE); also elsewhere on the board
/DDR3/DDR0_CK_N: R4.1, U1.K7 (CK_N); also elsewhere on the board
/DDR3/DDR0_CK_P: R4.2, U1.J7 (CK); also elsewhere on the board
/DDR3/DDR0_DQ0: U1.E3 (DQ0); also elsewhere on the board
/DDR3/DDR0_DQ1: U1.F7 (DQ1); also elsewhere on the board
/DDR3/DDR0_DQ2: U1.F2 (DQ2); also elsewhere on the board
/DDR3/DDR0_DQ3: U1.F8 (DQ3); also elsewhere on the board
/DDR3/DDR0_DQ4: U1.H3 (DQ4); also elsewhere on the board
/DDR3/DDR0_DQ5: U1.H8 (DQ5); also elsewhere on the board
/DDR3/DDR0_DQ6: U1.G2 (DQ6); also elsewhere on the board
/DDR3/DDR0_DQ7: U1.H7 (DQ7); also elsewhere on the board
/DDR3/DDR0_DQ8: U1.D7 (DQ8); also elsewhere on the board
/DDR3/DDR0_DQ9: U1.C3 (DQ9); also elsewhere on the board
/DDR3/DDR0_DQ10: U1.C8 (DQ10); also elsewhere on the board
/DDR3/DDR0_DQ11: U1.C2 (DQ11); also elsewhere on the board
/DDR3/DDR0_DQ12: U1.A7 (DQ12); also elsewhere on the board
/DDR3/DDR0_DQ13: U1.A2 (DQ13); also elsewhere on the board
/DDR3/DDR0_DQ14: U1.B8 (DQ14); also elsewhere on the board
/DDR3/DDR0_DQ15: U1.A3 (DQ15); also elsewhere on the board
/DDR3/DDR0_LDM: U1.E7 (LDM); also elsewhere on the board
/DDR3/DDR0_LDQS_N: U1.G3 (LDQS_N); also elsewhere on the board
/DDR3/DDR0_LDQS_P: U1.F3 (LDQS); also elsewhere on the board
/DDR3/DDR0_ODT: R6.2, U1.K1 (ODT); also elsewhere on the board
/DDR3/DDR0_RAS_N: R10.8, U1.J3 (RAS_N); also elsewhere on the board
/DDR3/DDR0_RESET_N: R5.2, U1.T2 (RESET_N); also elsewhere on the board
/DDR3/DDR0_UDM: U1.D3 (UDM); also elsewhere on the board
/DDR3/DDR0_UDQS_N: U1.B7 (UDQS_N); also elsewhere on the board
/DDR3/DDR0_UDQS_P: U1.C7 (UDQS); also elsewhere on the board
/DDR3/DDR0_WE_N: R10.6, U1.L3 (WE_N); also elsewhere on the board
GND: C1.2, C2.2, C3.2, C4.2, C5.2, C6.2, C7.2, C8.2, C9.2, C10.2, C11.2, C12.2, C13.2, C14.2, C15.2, C16.1, C17.1, C18.1, C19.1, C20.1, C21.1, C22.1, C23.1, C24.1, C25.1, C26.1, C27.1, C28.1, C29.1, C30.1, C31.1, C32.1, C33.2, C174.2, C176.2, C178.2, C180.2, C182.2, C184.2, C186.2, C187.2, C207.2, C209.2, R5.1, R6.1, R7.1, R11.1, R12.2, U1.A9 (VSS), U1.B1 (VSSQ), U1.B3 (VSS), U1.B9 (VSSQ), U1.D1 (VSSQ), U1.D8 (VSSQ), U1.E1 (VSS), U1.E2 (VSSQ), U1.E8 (VSSQ), U1.F9 (VSSQ), U1.G1 (VSSQ), U1.G8 (VSS), U1.G9 (VSSQ), U1.J2 (VSS), U1.J8 (VSS), U1.M1 (VSS), U1.M9 (VSS), U1.P1 (VSS), U1.P9 (VSS), U1.T1 (VSS), U1.T9 (VSS); also elsewhere on the board
unnamed: R12.1, U1.L8 (ZQ)
unnamed: R11.2, U1.L2 (CS_N)
VCC1V5: C16.2, C17.2, C18.2, C19.2, C20.2, C21.2, C22.2, C23.2, C24.2, C25.2, C26.2, C27.2, C28.2, C29.2, C30.2, C31.2, C32.2, U1.A1 (VDDQ), U1.A8 (VDDQ), U1.B2 (VDD), U1.C1 (VDDQ), U1.C9 (VDDQ), U1.D2 (VDDQ), U1.D9 (VDD), U1.E9 (VDDQ), U1.F1 (VDDQ), U1.G7 (VDD), U1.H2 (VDDQ), U1.H9 (VDDQ), U1.K2 (VDD), U1.K8 (VDD), U1.N1 (VDD), U1.N9 (VDD), U1.R1 (VDD), U1.R9 (VDD); also elsewhere on the board
VTTDDR0: C1.1, C2.1, C3.1, C4.1, C5.1, C6.1, C7.1, C8.1, C9.1, C10.1, C11.1, C12.1, C13.1, C14.1, C15.1, C174.1, C176.1, C178.1, C180.1, C182.1, C184.1, C186.1, C187.1, C207.1, C209.1, R1.1, R2.1, R2.3, R2.5, R2.7, R3.1, R3.3, R3.5, R3.7, R8.1, R8.3, R8.5, R8.7, R9.1, R9.3, R9.5, R9.7, R10.1, R10.3, R10.5, R10.7; also elsewhere on the board
VTTREF0: C33.1, U1.H1 (VREFDQ), U1.M8 (VREFCA); also elsewhere on the board

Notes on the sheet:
DDR3

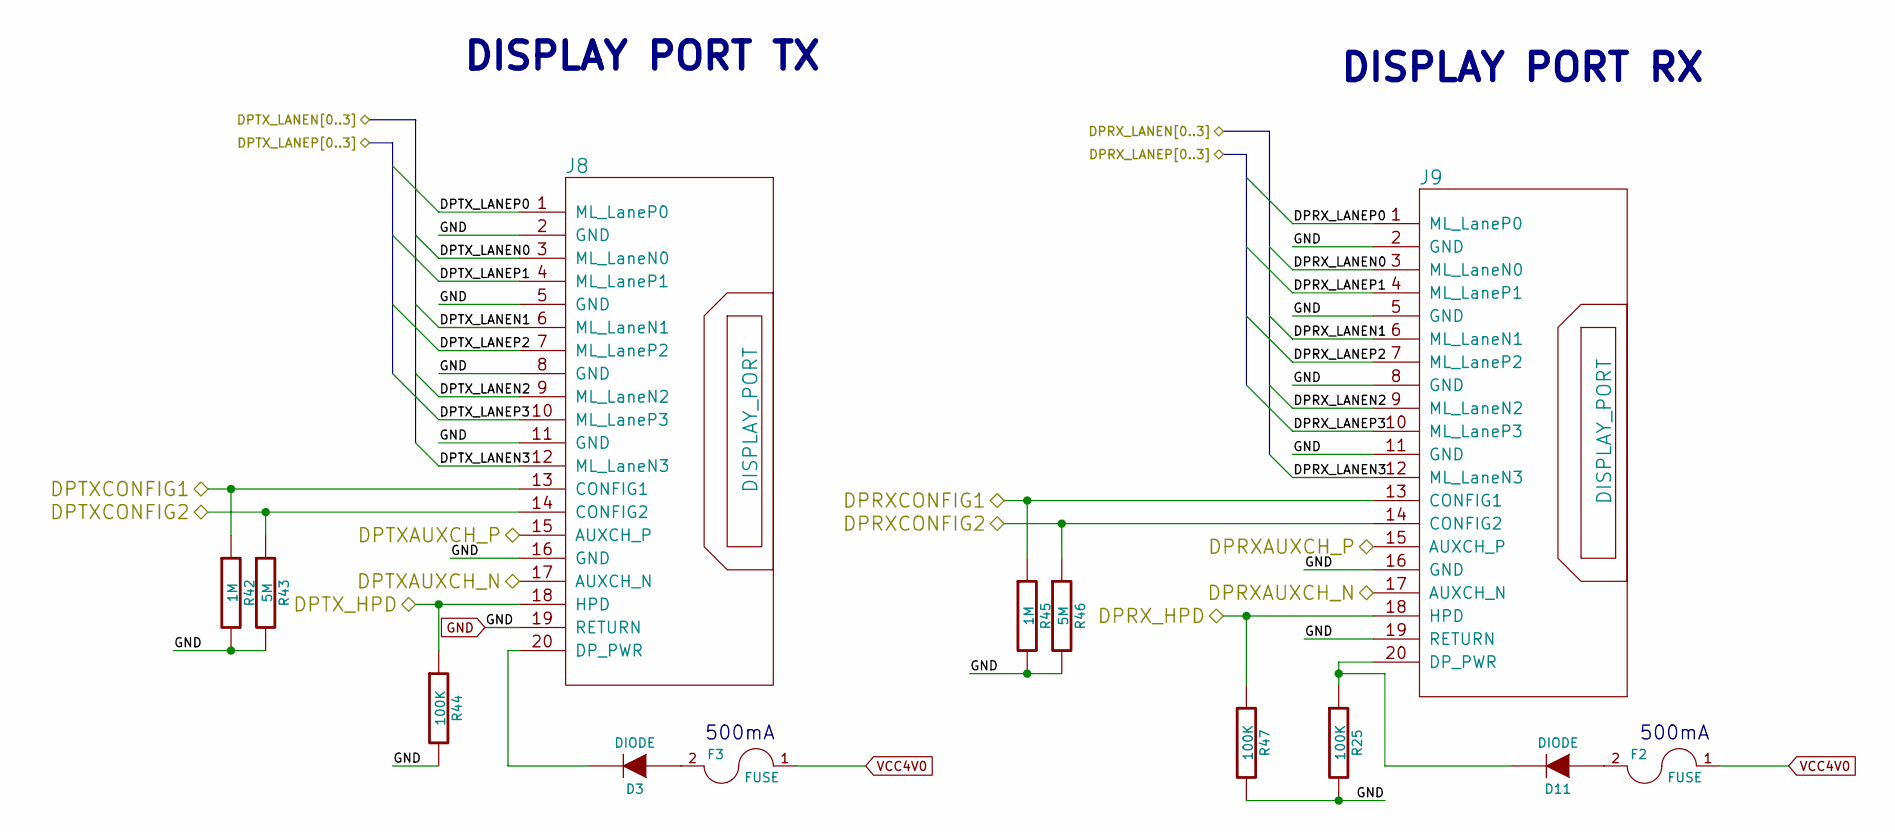
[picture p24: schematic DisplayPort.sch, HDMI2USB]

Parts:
D3, D11: DIODE
F2, F3: FUSE
J8, J9: DISPLAY_PORT
R25, R44, R47: 100K
R42, R45: 1M
R43, R46: 5M

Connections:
/DisplayPort/DPRXAUXCH_N: J9.17 (AUXCH_N); also elsewhere on the board
/DisplayPort/DPRXAUXCH_P: J9.15 (AUXCH_P); also elsewhere on the board
/DisplayPort/DPRXCONFIG1: J9.13 (CONFIG1), R45.1; also elsewhere on the board
/DisplayPort/DPRXCONFIG2: J9.14 (CONFIG2), R46.1; also elsewhere on the board
/DisplayPort/DPRX_LANEN0: J9.3 (ML_LaneN0); also elsewhere on the board
/DisplayPort/DPRX_LANEN1: J9.6 (ML_LaneN1); also elsewhere on the board
/DisplayPort/DPRX_LANEN2: J9.9 (ML_LaneN2); also elsewhere on the board
/DisplayPort/DPRX_LANEN3: J9.12 (ML_LaneN3); also elsewhere on the board
/DisplayPort/DPRX_LANEP0: J9.1 (ML_LaneP0); also elsewhere on the board
/DisplayPort/DPRX_LANEP1: J9.4 (ML_LaneP1); also elsewhere on the board
/DisplayPort/DPRX_LANEP2: J9.7 (ML_LaneP2); also elsewhere on the board
/DisplayPort/DPRX_LANEP3: J9.10 (ML_LaneP3); also elsewhere on the board
/DisplayPort/DPTXAUXCH_N: J8.17 (AUXCH_N); also elsewhere on the board
/DisplayPort/DPTXAUXCH_P: J8.15 (AUXCH_P); also elsewhere on the board
/DisplayPort/DPTXCONFIG1: J8.13 (CONFIG1), R42.1; also elsewhere on the board
/DisplayPort/DPTXCONFIG2: J8.14 (CONFIG2), R43.1; also elsewhere on the board
/DisplayPort/DPTX_LANEN0: J8.3 (ML_LaneN0); also elsewhere on the board
/DisplayPort/DPTX_LANEN1: J8.6 (ML_LaneN1); also elsewhere on the board
/DisplayPort/DPTX_LANEN2: J8.9 (ML_LaneN2); also elsewhere on the board
/DisplayPort/DPTX_LANEN3: J8.12 (ML_LaneN3); also elsewhere on the board
/DisplayPort/DPTX_LANEP0: J8.1 (ML_LaneP0); also elsewhere on the board
/DisplayPort/DPTX_LANEP1: J8.4 (ML_LaneP1); also elsewhere on the board
/DisplayPort/DPTX_LANEP2: J8.7 (ML_LaneP2); also elsewhere on the board
/DisplayPort/DPTX_LANEP3: J8.10 (ML_LaneP3); also elsewhere on the board
/FPGA_Bank_1_2/DPRXHPD: J9.18 (HPD), R47.1; also elsewhere on the board
/FPGA_Bank_1_2/DPTXHPD: J8.18 (HPD), R44.1; also elsewhere on the board
GND: J8.2 (GND), J8.5 (GND), J8.8 (GND), J8.11 (GND), J8.16 (GND), J8.19 (RETURN), J9.2 (GND), J9.5 (GND), J9.8 (GND), J9.11 (GND), J9.16 (GND), J9.19 (RETURN), R25.2, R42.2, R43.2, R44.2, R45.2, R46.2, R47.2; also elsewhere on the board
unnamed: D11.2 (K), J9.20 (DP_PWR), R25.1
unnamed: D11.1 (A), F2.2
unnamed: D3.2 (K), J8.20 (DP_PWR)
unnamed: D3.1 (A), F3.2
VCC4V0: F2.1, F3.1; also elsewhere on the board

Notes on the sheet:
DISPLAY PORT TX
DISPLAY PORT RX
500mA

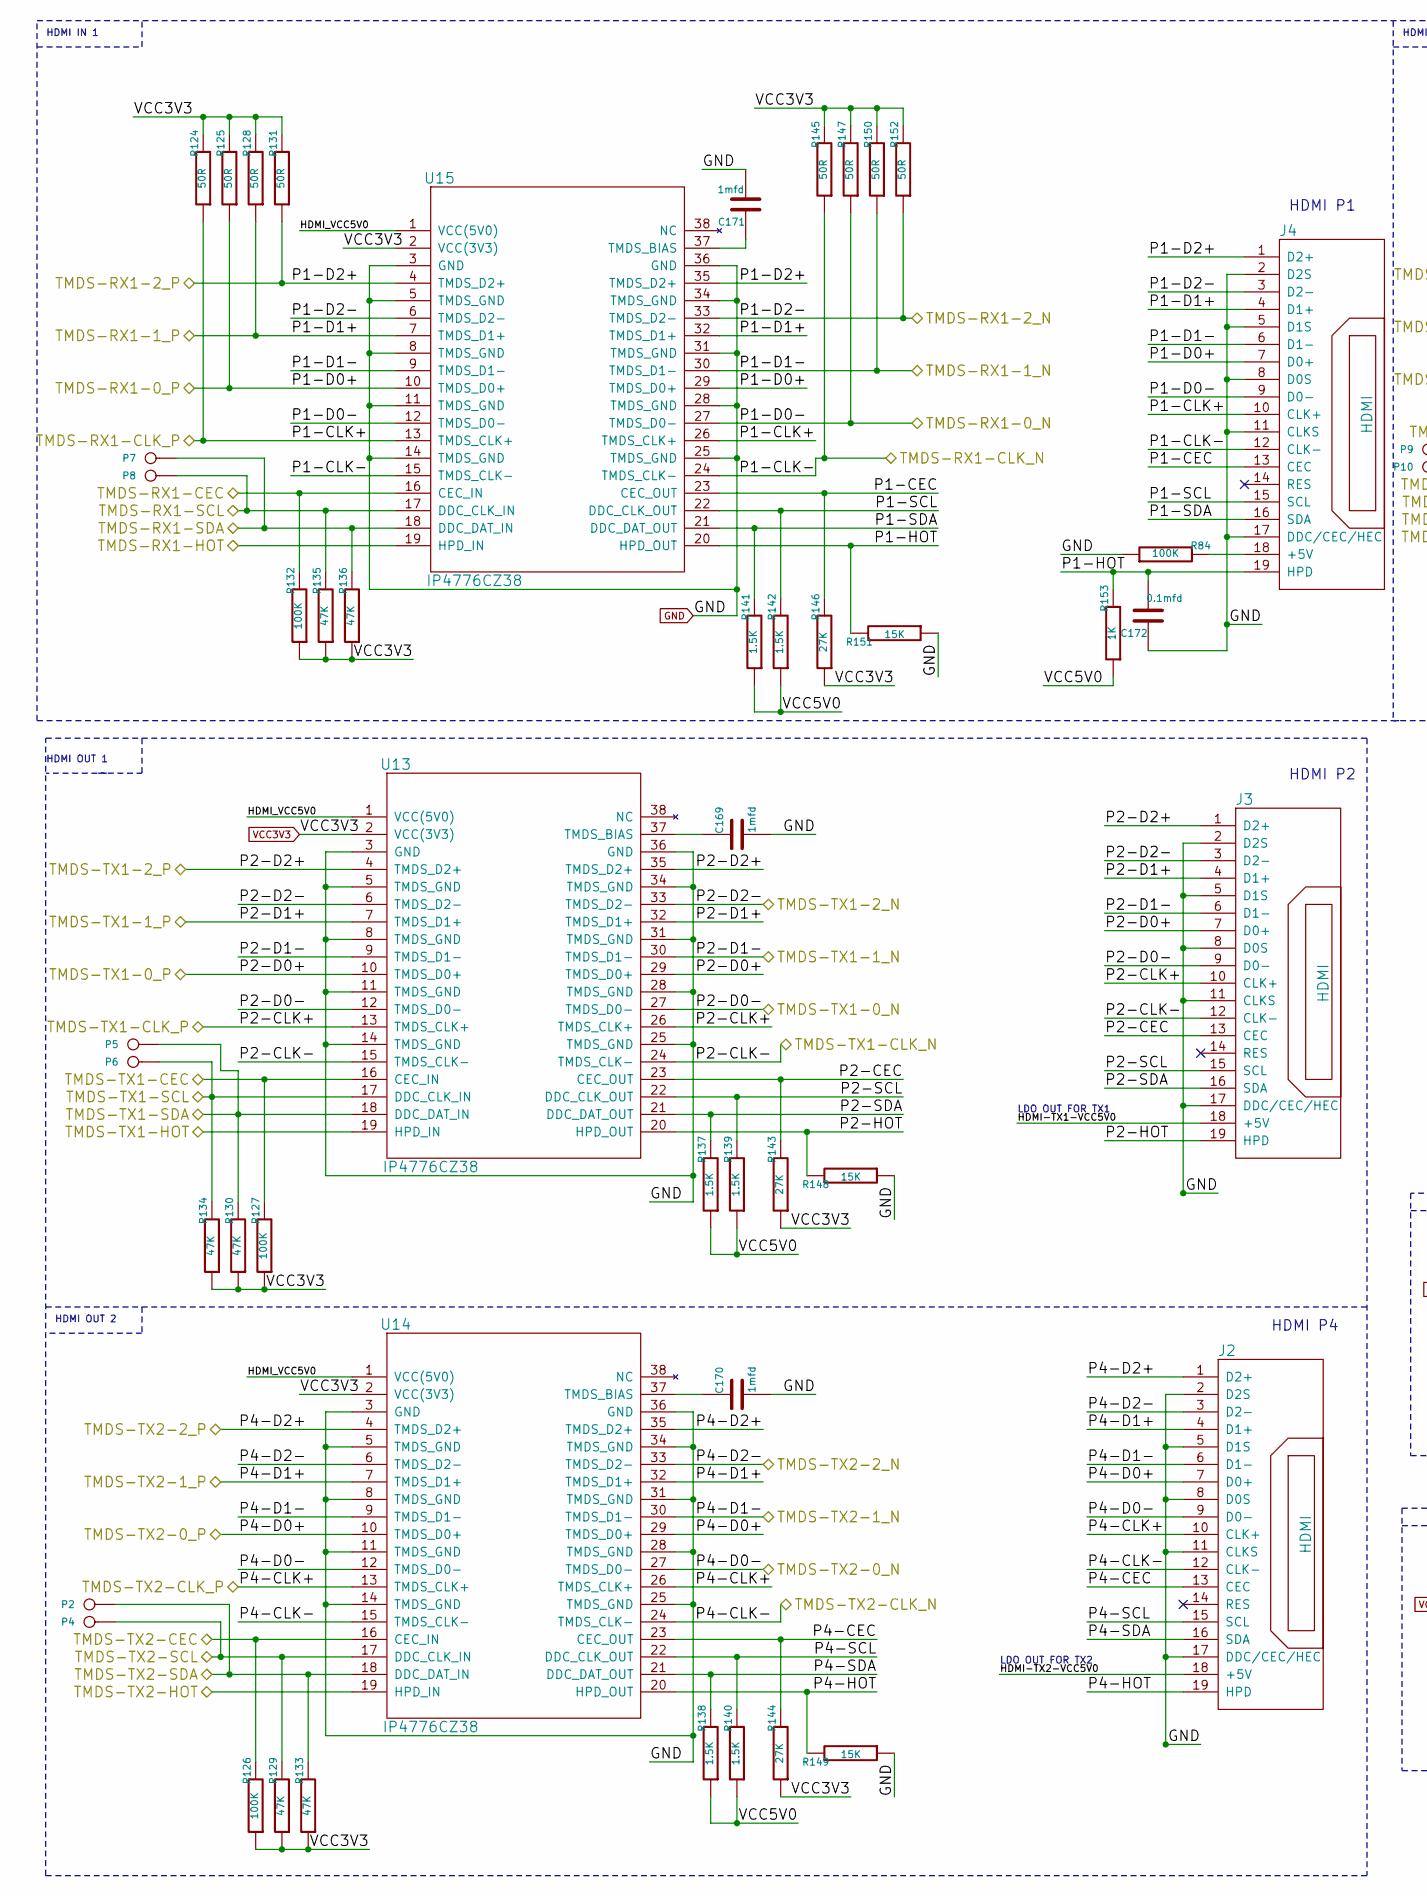
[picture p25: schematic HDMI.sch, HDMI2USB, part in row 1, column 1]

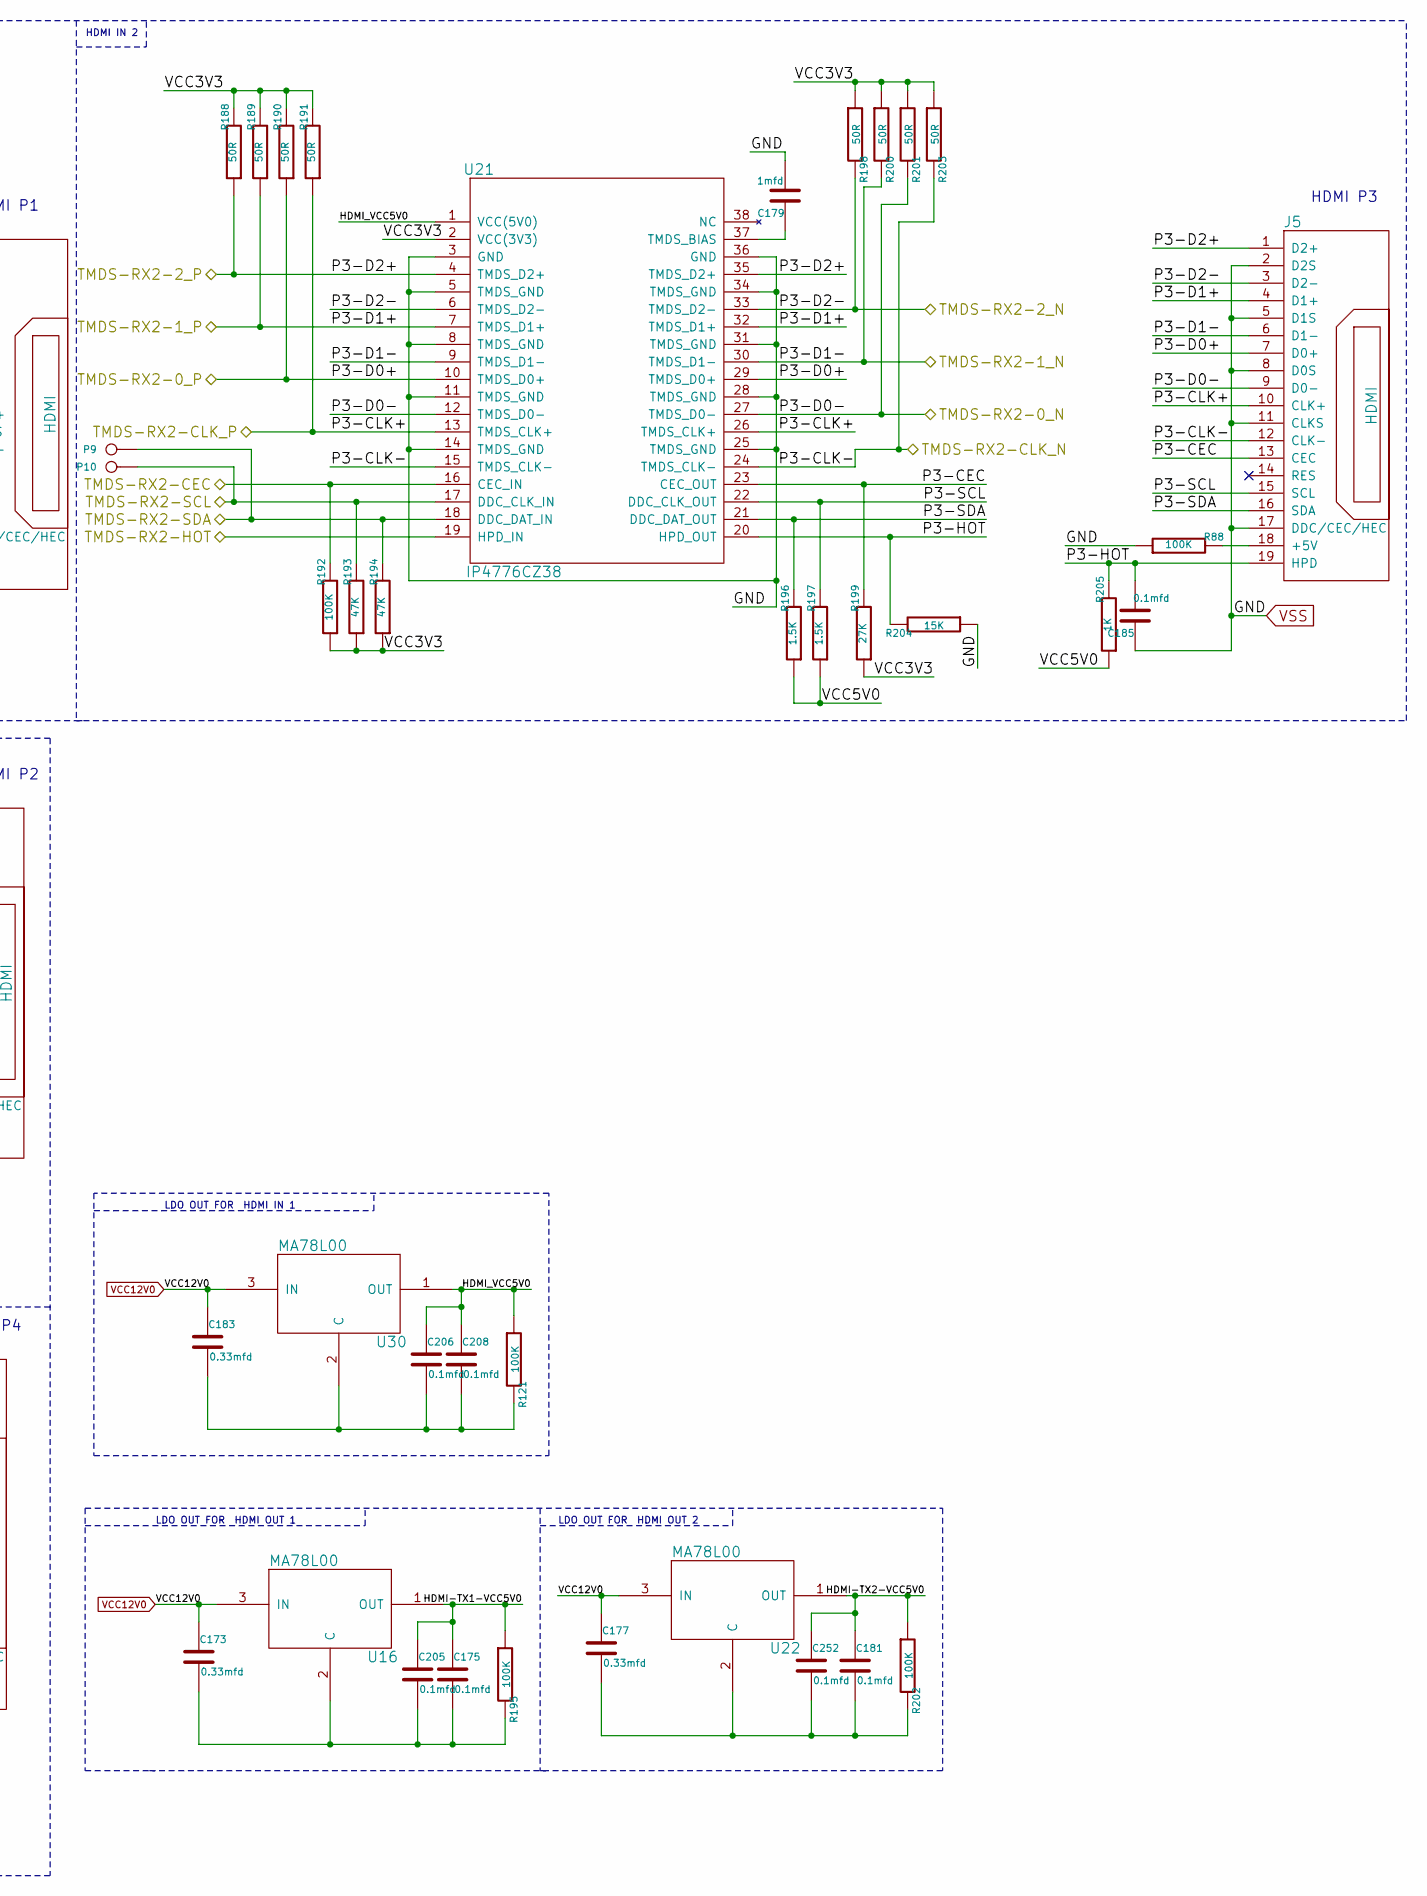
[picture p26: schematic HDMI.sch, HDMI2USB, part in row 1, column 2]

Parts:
C169, C170, C171, C179: 1mfd
C172, C175, C181, C185, C205, C206, C208, C252: 0.1mfd
C173, C177, C183: 0.33mfd
J2, J3, J4, J5: HDMI
P2, P4, P5, P6, P7, P8, P9, P10: CONN_1
R84, R88, R121, R126, R127, R132, R192, R195, R202: 100K
R124, R125, R128, R131, R145, R147, R150, R152, R188, R189, R190, R191, R198, R200, R201, R203: 50R
R129, R130, R133, R134, R135, R136, R193, R194: 47K
R137, R138, R139, R140, R141, R142, R196, R197: 1.5K
R143, R144, R146, R199: 27K
R148, R149, R151, R204: 15K
R153, R205: 1K
U13, U14, U15, U21: IP4776CZ38
U16, U22, U30: ΜA78L00

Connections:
/HDMI/HDMI-TX1-VCC5V0: C175.1, C205.1, J3.18 (+5V), R195.1, U16.1 (OUT)
/HDMI/HDMI-TX2-VCC5V0: C181.1, C252.1, J2.18 (+5V), R202.1, U22.1 (OUT)
/HDMI/HDMI_VCC5V0: C206.1, C208.1, R121.1, U13.1 (VCC(5V0)), U14.1 (VCC(5V0)), U15.1 (VCC(5V0)), U21.1 (VCC(5V0)), U30.1 (OUT)
/HDMI/P1-CEC: J4.13 (CEC), R146.2, U15.23 (CEC_OUT)
/HDMI/P1-HOT: C172.2, J4.19 (HPD), R151.2, R153.2, U15.20 (HPD_OUT)
/HDMI/P1-SCL: J4.15 (SCL), R142.2, U15.22 (DDC_CLK_OUT)
/HDMI/P1-SDA: J4.16 (SDA), R141.2, U15.21 (DDC_DAT_OUT)
/HDMI/P2-CEC: J3.13 (CEC), R143.2, U13.23 (CEC_OUT)
/HDMI/P2-HOT: J3.19 (HPD), R148.2, U13.20 (HPD_OUT)
/HDMI/P2-SCL: J3.15 (SCL), R139.2, U13.22 (DDC_CLK_OUT)
/HDMI/P2-SDA: J3.16 (SDA), R137.2, U13.21 (DDC_DAT_OUT)
/HDMI/P3-CEC: J5.13 (CEC), R199.2, U21.23 (CEC_OUT)
/HDMI/P3-HOT: C185.2, J5.19 (HPD), R204.2, R205.2, U21.20 (HPD_OUT)
/HDMI/P3-SCL: J5.15 (SCL), R197.2, U21.22 (DDC_CLK_OUT)
/HDMI/P3-SDA: J5.16 (SDA), R196.2, U21.21 (DDC_DAT_OUT)
/HDMI/P4-CEC: J2.13 (CEC), R144.2, U14.23 (CEC_OUT)
/HDMI/P4-HOT: J2.19 (HPD), R149.2, U14.20 (HPD_OUT)
/HDMI/P4-SCL: J2.15 (SCL), R140.2, U14.22 (DDC_CLK_OUT)
/HDMI/P4-SDA: J2.16 (SDA), R138.2, U14.21 (DDC_DAT_OUT)
/HDMI/TMDS-RX1-0_N: J4.9 (D0-), R147.1, U15.12 (TMDS_D0-), U15.27 (TMDS_D0-); also elsewhere on the board
/HDMI/TMDS-RX1-0_P: J4.7 (D0+), R125.1, U15.10 (TMDS_D0+), U15.29 (TMDS_D0+); also elsewhere on the board
/HDMI/TMDS-RX1-1_N: J4.6 (D1-), R150.1, U15.9 (TMDS_D1-), U15.30 (TMDS_D1-); also elsewhere on the board
/HDMI/TMDS-RX1-1_P: J4.4 (D1+), R128.1, U15.7 (TMDS_D1+), U15.32 (TMDS_D1+); also elsewhere on the board
/HDMI/TMDS-RX1-2_N: J4.3 (D2-), R152.1, U15.6 (TMDS_D2-), U15.33 (TMDS_D2-); also elsewhere on the board
/HDMI/TMDS-RX1-2_P: J4.1 (D2+), R131.1, U15.4 (TMDS_D2+), U15.35 (TMDS_D2+); also elsewhere on the board
/HDMI/TMDS-RX1-CEC: R132.2, U15.16 (CEC_IN); also elsewhere on the board
/HDMI/TMDS-RX1-CLK_N: J4.12 (CLK-), R145.1, U15.15 (TMDS_CLK-), U15.24 (TMDS_CLK-); also elsewhere on the board
/HDMI/TMDS-RX1-CLK_P: J4.10 (CLK+), R124.1, U15.13 (TMDS_CLK+), U15.26 (TMDS_CLK+); also elsewhere on the board
/HDMI/TMDS-RX1-HOT: U15.19 (HPD_IN); also elsewhere on the board
/HDMI/TMDS-RX1-SCL: P8.1, R135.2, U15.17 (DDC_CLK_IN); also elsewhere on the board
/HDMI/TMDS-RX1-SDA: P7.1, R136.2, U15.18 (DDC_DAT_IN); also elsewhere on the board
/HDMI/TMDS-RX2-0_N: J5.9 (D0-), R201.2, U21.12 (TMDS_D0-), U21.27 (TMDS_D0-); also elsewhere on the board
/HDMI/TMDS-RX2-0_P: J5.7 (D0+), R190.1, U21.10 (TMDS_D0+), U21.29 (TMDS_D0+); also elsewhere on the board
/HDMI/TMDS-RX2-1_N: J5.6 (D1-), R200.2, U21.9 (TMDS_D1-), U21.30 (TMDS_D1-); also elsewhere on the board
/HDMI/TMDS-RX2-1_P: J5.4 (D1+), R189.1, U21.7 (TMDS_D1+), U21.32 (TMDS_D1+); also elsewhere on the board
/HDMI/TMDS-RX2-2_N: J5.3 (D2-), R198.2, U21.6 (TMDS_D2-), U21.33 (TMDS_D2-); also elsewhere on the board
/HDMI/TMDS-RX2-2_P: J5.1 (D2+), R188.1, U21.4 (TMDS_D2+), U21.35 (TMDS_D2+); also elsewhere on the board
/HDMI/TMDS-RX2-CEC: R192.2, U21.16 (CEC_IN); also elsewhere on the board
/HDMI/TMDS-RX2-CLK_N: J5.12 (CLK-), R203.2, U21.15 (TMDS_CLK-), U21.24 (TMDS_CLK-); also elsewhere on the board
/HDMI/TMDS-RX2-CLK_P: J5.10 (CLK+), R191.1, U21.13 (TMDS_CLK+), U21.26 (TMDS_CLK+); also elsewhere on the board
/HDMI/TMDS-RX2-HOT: U21.19 (HPD_IN); also elsewhere on the board
/HDMI/TMDS-RX2-SCL: P10.1, R193.2, U21.17 (DDC_CLK_IN); also elsewhere on the board
/HDMI/TMDS-RX2-SDA: P9.1, R194.2, U21.18 (DDC_DAT_IN); also elsewhere on the board
/HDMI/TMDS-TX1-0_N: J3.9 (D0-), U13.12 (TMDS_D0-), U13.27 (TMDS_D0-); also elsewhere on the board
/HDMI/TMDS-TX1-0_P: J3.7 (D0+), U13.10 (TMDS_D0+), U13.29 (TMDS_D0+); also elsewhere on the board
/HDMI/TMDS-TX1-1_N: J3.6 (D1-), U13.9 (TMDS_D1-), U13.30 (TMDS_D1-); also elsewhere on the board
/HDMI/TMDS-TX1-1_P: J3.4 (D1+), U13.7 (TMDS_D1+), U13.32 (TMDS_D1+); also elsewhere on the board
/HDMI/TMDS-TX1-2_N: J3.3 (D2-), U13.6 (TMDS_D2-), U13.33 (TMDS_D2-); also elsewhere on the board
/HDMI/TMDS-TX1-2_P: J3.1 (D2+), U13.4 (TMDS_D2+), U13.35 (TMDS_D2+); also elsewhere on the board
/HDMI/TMDS-TX1-CEC: R127.2, U13.16 (CEC_IN); also elsewhere on the board
/HDMI/TMDS-TX1-CLK_N: J3.12 (CLK-), U13.15 (TMDS_CLK-), U13.24 (TMDS_CLK-); also elsewhere on the board
/HDMI/TMDS-TX1-CLK_P: J3.10 (CLK+), U13.13 (TMDS_CLK+), U13.26 (TMDS_CLK+); also elsewhere on the board
/HDMI/TMDS-TX1-HOT: U13.19 (HPD_IN); also elsewhere on the board
/HDMI/TMDS-TX1-SCL: P6.1, R134.2, U13.17 (DDC_CLK_IN); also elsewhere on the board
/HDMI/TMDS-TX1-SDA: P5.1, R130.2, U13.18 (DDC_DAT_IN); also elsewhere on the board
/HDMI/TMDS-TX2-0_N: J2.9 (D0-), U14.12 (TMDS_D0-), U14.27 (TMDS_D0-); also elsewhere on the board
/HDMI/TMDS-TX2-0_P: J2.7 (D0+), U14.10 (TMDS_D0+), U14.29 (TMDS_D0+); also elsewhere on the board
/HDMI/TMDS-TX2-1_N: J2.6 (D1-), U14.9 (TMDS_D1-), U14.30 (TMDS_D1-); also elsewhere on the board
/HDMI/TMDS-TX2-1_P: J2.4 (D1+), U14.7 (TMDS_D1+), U14.32 (TMDS_D1+); also elsewhere on the board
/HDMI/TMDS-TX2-2_N: J2.3 (D2-), U14.6 (TMDS_D2-), U14.33 (TMDS_D2-); also elsewhere on the board
/HDMI/TMDS-TX2-2_P: J2.1 (D2+), U14.4 (TMDS_D2+), U14.35 (TMDS_D2+); also elsewhere on the board
/HDMI/TMDS-TX2-CEC: R126.2, U14.16 (CEC_IN); also elsewhere on the board
/HDMI/TMDS-TX2-CLK_N: J2.12 (CLK-), U14.15 (TMDS_CLK-), U14.24 (TMDS_CLK-); also elsewhere on the board
/HDMI/TMDS-TX2-CLK_P: J2.10 (CLK+), U14.13 (TMDS_CLK+), U14.26 (TMDS_CLK+); also elsewhere on the board
/HDMI/TMDS-TX2-HOT: U14.19 (HPD_IN); also elsewhere on the board
/HDMI/TMDS-TX2-SCL: P4.1, R129.2, U14.17 (DDC_CLK_IN); also elsewhere on the board
/HDMI/TMDS-TX2-SDA: P2.1, R133.2, U14.18 (DDC_DAT_IN); also elsewhere on the board
/HDMI/VCC5V0: R137.1, R138.1, R139.1, R140.1, R141.1, R142.1, R153.1, R196.1, R197.1, R205.1
GND: C169.2, C170.2, C171.2, C172.1, C179.2, C185.1, J2.2 (D2S), J2.5 (D1S), J2.8 (D0S), J2.11 (CLKS), J2.17 (DDC/CEC/HEC), J3.2 (D2S), J3.5 (D1S), J3.8 (D0S), J3.11 (CLKS), J3.17 (DDC/CEC/HEC), J4.2 (D2S), J4.5 (D1S), J4.8 (D0S), J4.11 (CLKS), J4.17 (DDC/CEC/HEC), J5.2 (D2S), J5.5 (D1S), J5.8 (D0S), J5.11 (CLKS), J5.17 (DDC/CEC/HEC), R84.1, R88.1, R148.1, R149.1, R151.1, R204.1, U13.3 (GND), U13.5 (TMDS_GND), U13.8 (TMDS_GND), U13.11 (TMDS_GND), U13.14 (TMDS_GND), U13.25 (TMDS_GND), U13.28 (TMDS_GND), U13.31 (TMDS_GND), U13.34 (TMDS_GND), U13.36 (GND), U14.3 (GND), U14.5 (TMDS_GND), U14.8 (TMDS_GND), U14.11 (TMDS_GND), U14.14 (TMDS_GND), U14.25 (TMDS_GND), U14.28 (TMDS_GND), U14.31 (TMDS_GND), U14.34 (TMDS_GND), U14.36 (GND), U15.3 (GND), U15.5 (TMDS_GND), U15.8 (TMDS_GND), U15.11 (TMDS_GND), U15.14 (TMDS_GND), U15.25 (TMDS_GND), U15.28 (TMDS_GND), U15.31 (TMDS_GND), U15.34 (TMDS_GND), U15.36 (GND), U21.3 (GND), U21.5 (TMDS_GND), U21.8 (TMDS_GND), U21.11 (TMDS_GND), U21.14 (TMDS_GND), U21.25 (TMDS_GND), U21.28 (TMDS_GND), U21.31 (TMDS_GND), U21.34 (TMDS_GND), U21.36 (GND); also elsewhere on the board
unnamed: C179.1, U21.37 (TMDS_BIAS)
unnamed: C177.2, C181.2, C252.2, R202.2, U22.2 (C)
unnamed: J4.18 (+5V), R84.2
unnamed: C171.1, U15.37 (TMDS_BIAS)
unnamed: J5.18 (+5V), R88.2
unnamed: C169.1, U13.37 (TMDS_BIAS)
unnamed: C170.1, U14.37 (TMDS_BIAS)
unnamed: C173.2, C175.2, C205.2, R195.2, U16.2 (C)
unnamed: C183.2, C206.2, C208.2, R121.2, U30.2 (C)
VCC3V3: R124.2, R125.2, R126.1, R127.1, R128.2, R129.1, R130.1, R131.2, R132.1, R133.1, R134.1, R135.1, R136.1, R143.1, R144.1, R145.2, R146.1, R147.2, R150.2, R152.2, R188.2, R189.2, R190.2, R191.2, R192.1, R193.1, R194.1, R198.1, R199.1, R200.1, R201.1, R203.1, U13.2 (VCC(3V3)), U14.2 (VCC(3V3)), U15.2 (VCC(3V3)), U21.2 (VCC(3V3)); also elsewhere on the board
VCC12V0: C173.1, C177.1, C183.1, U16.3 (IN), U22.3 (IN), U30.3 (IN); also elsewhere on the board

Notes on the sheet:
HDMI P1
HDMI P2
HDMI P4
HDMI P3
HDMI IN 1
HDMI OUT 1
LDO OUT FOR
LDO OUT FOR TX1
LDO OUT FOR TX2
HDMI OUT 2
HDMI IN 2

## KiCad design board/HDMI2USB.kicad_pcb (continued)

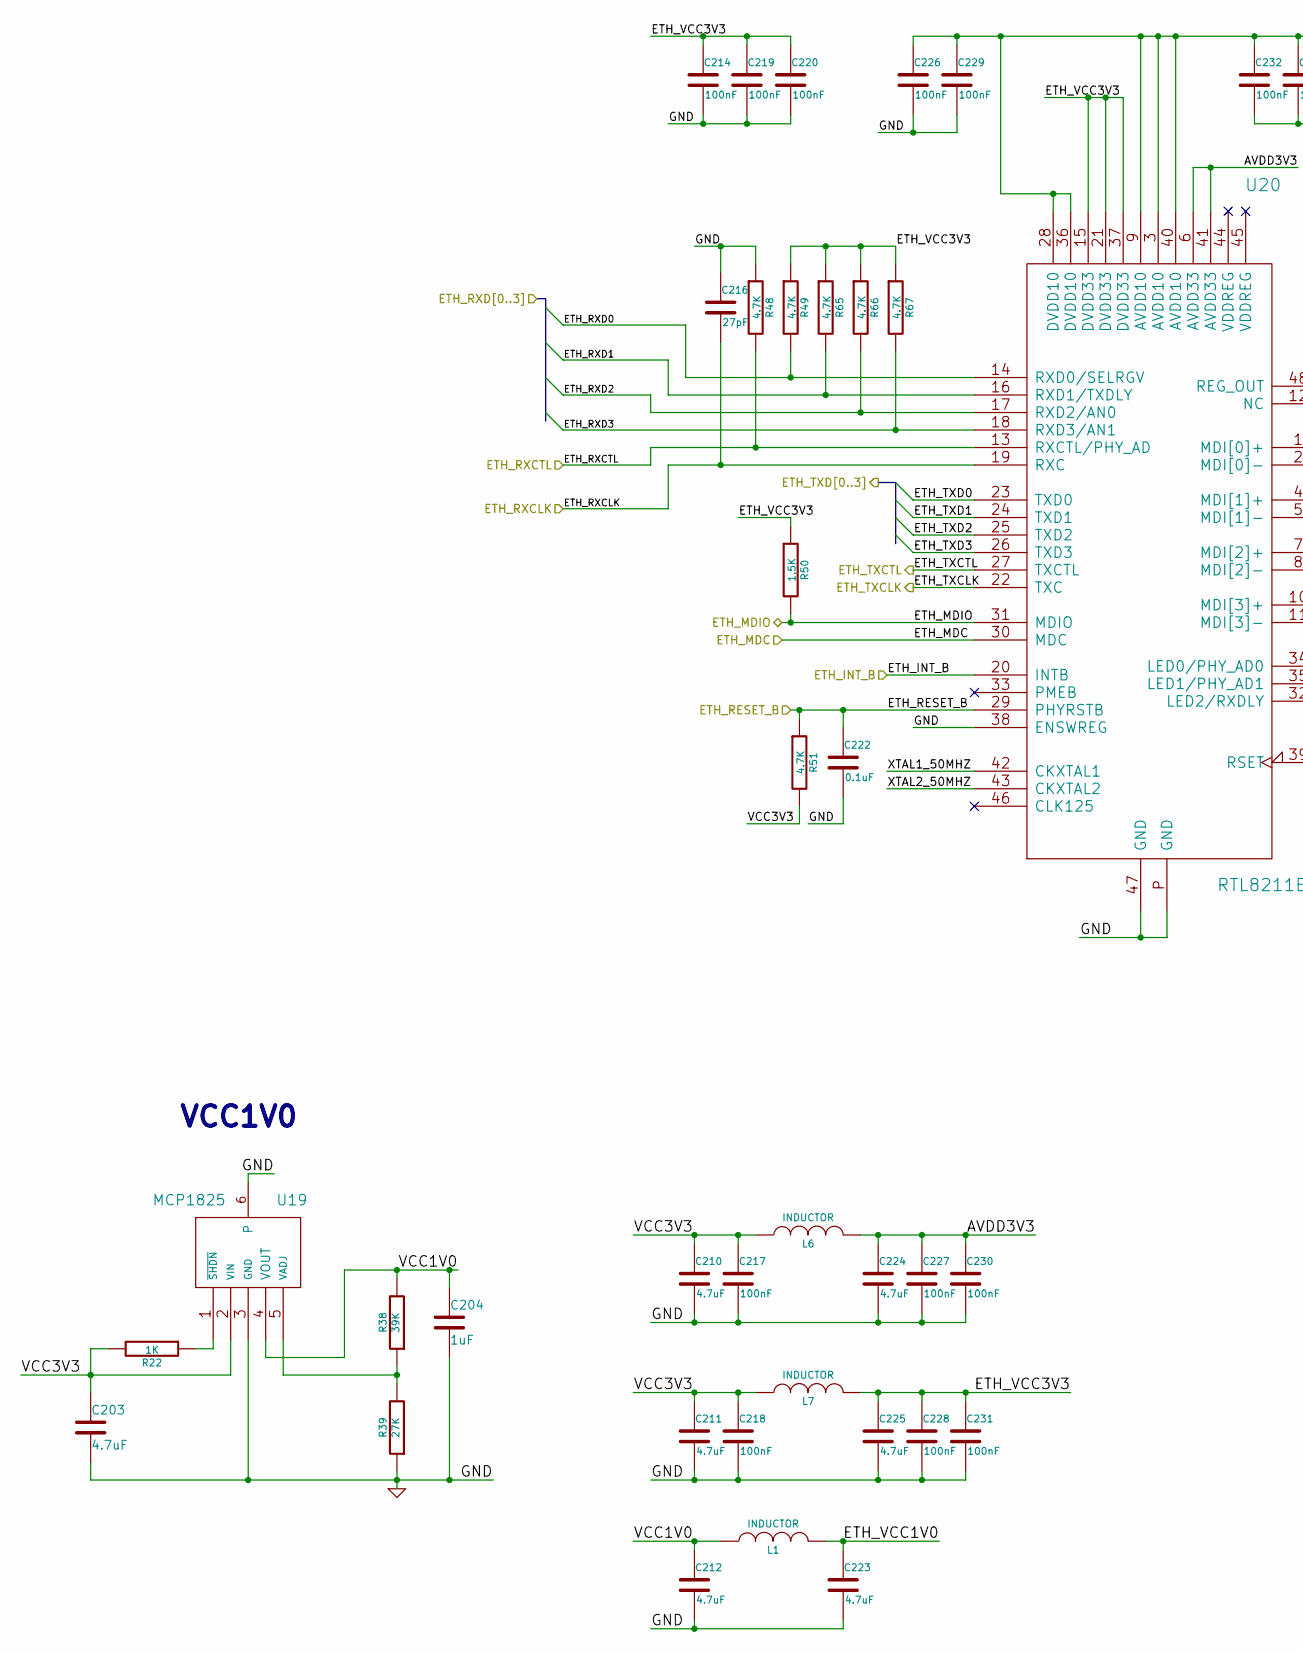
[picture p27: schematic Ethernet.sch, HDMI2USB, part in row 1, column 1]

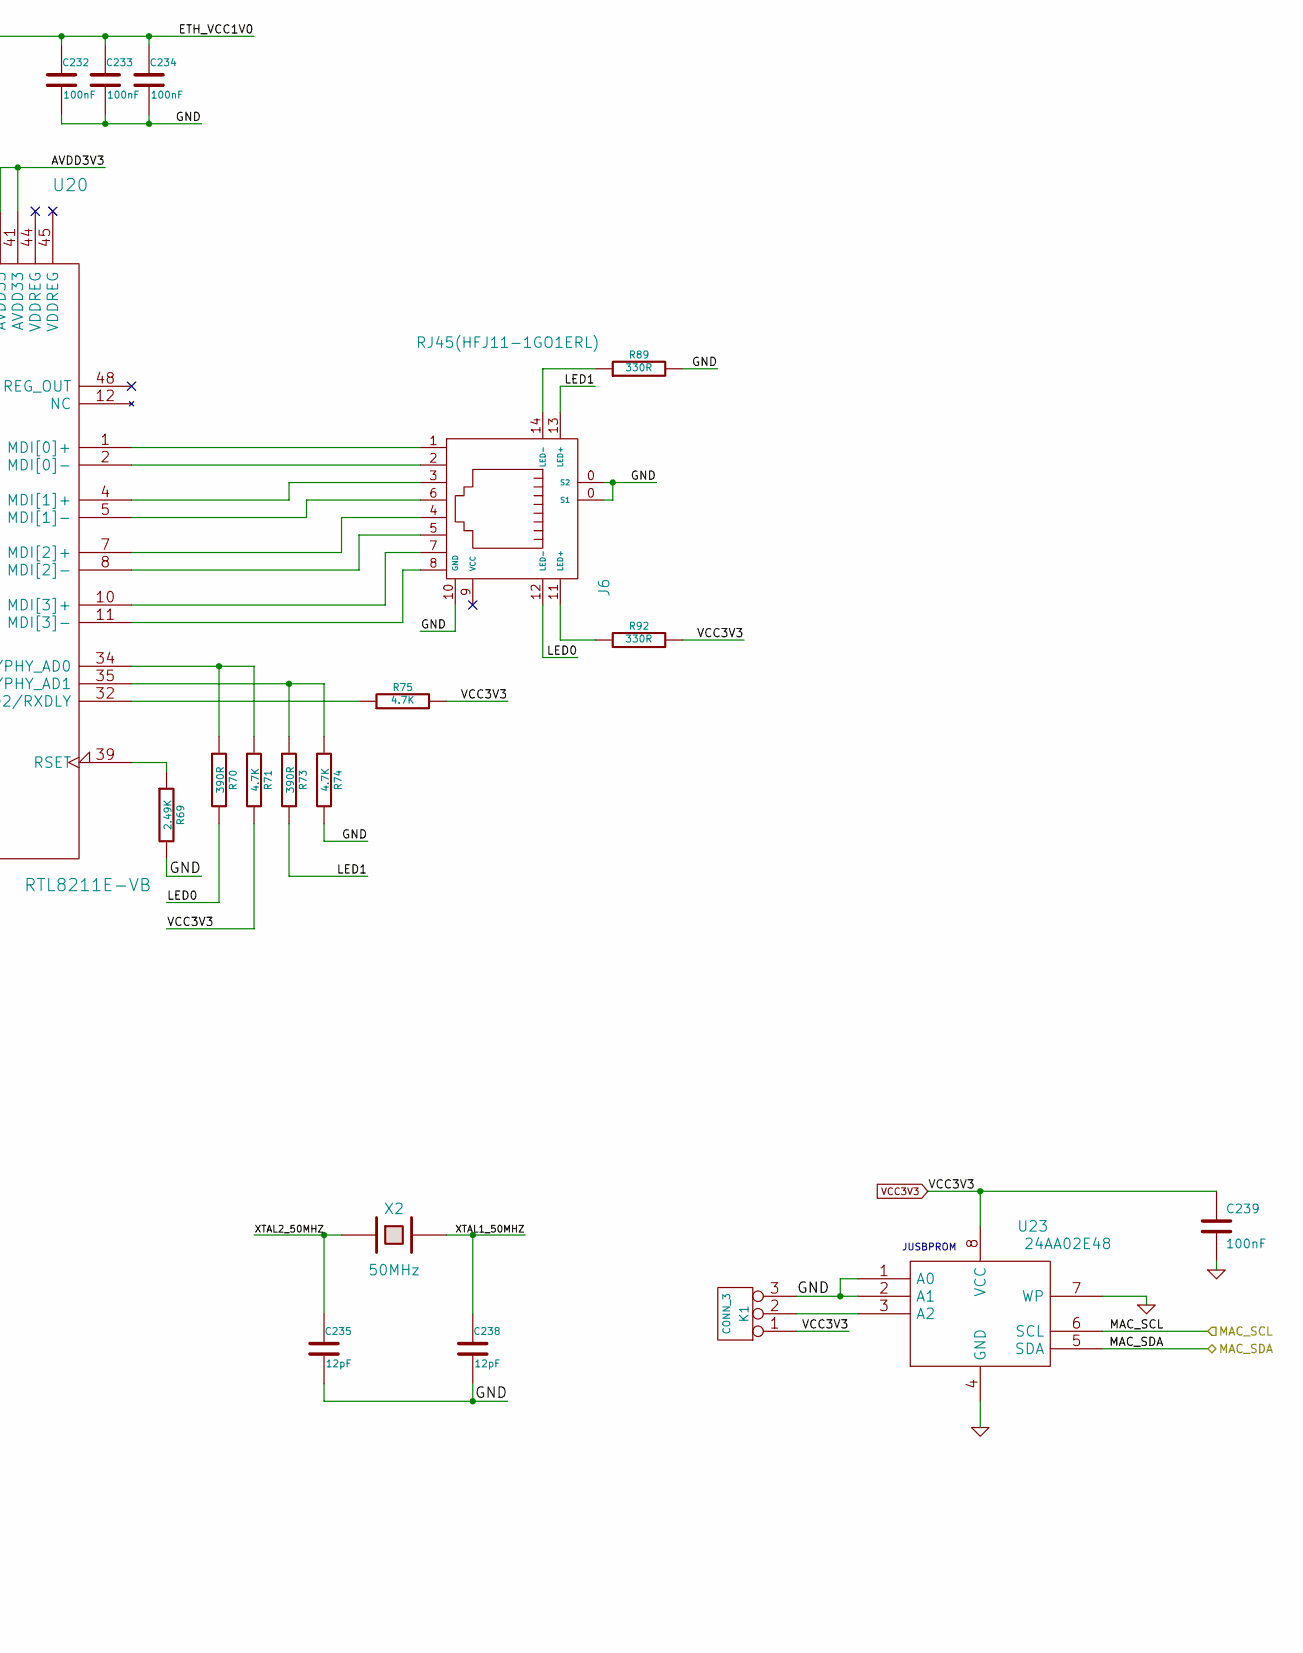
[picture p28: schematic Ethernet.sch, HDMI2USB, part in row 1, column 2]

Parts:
C203: 4.7uF
C204: 1uF
C210, C211, C212, C223, C224, C225: 4.7uF
C214, C217, C218, C219, C220, C226, C227, C228, C229, C230, C231, C232, C233, C234: 100nF
C216: 27pF
C222: 0.1uF
C235, C238: 12pF
C239: 100nF; SM0805
J6: RJ45(HFJ11-1GO1ERL)
K1: CONN_3
L1, L6, L7: INDUCTOR
R22: 1K
R38: 39K
R39: 27K
R48, R49, R51, R65, R66, R67, R71, R74, R75: 4.7K
R50: 1.5K
R69: 2.49K
R70, R73: 390R
R89, R92: 330R
U19: MCP1825
U20: RTL8211E-VB
U23: 24AA02E48; SO8
X2: 50MHz

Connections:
/Ethernet/AVDD3V3: C224.1, C227.1, C230.1, L6.2, U20.6 (AVDD33), U20.41 (AVDD33)
/Ethernet/ETH_INT_B: U20.20 (INTB); also elsewhere on the board
/Ethernet/ETH_MDC: U20.30 (MDC); also elsewhere on the board
/Ethernet/ETH_MDIO: R50.2, U20.31 (MDIO); also elsewhere on the board
/Ethernet/ETH_RESET_B: C222.1, R51.1, U20.29 (PHYRSTB); also elsewhere on the board
/Ethernet/ETH_RXCLK: C216.2, U20.19 (RXC); also elsewhere on the board
/Ethernet/ETH_RXCTL: R48.2, U20.13 (RXCTL/PHY_AD); also elsewhere on the board
/Ethernet/ETH_RXD0: R49.2, U20.14 (RXD0/SELRGV); also elsewhere on the board
/Ethernet/ETH_RXD1: R65.2, U20.16 (RXD1/TXDLY); also elsewhere on the board
/Ethernet/ETH_RXD2: R66.2, U20.17 (RXD2/AN0); also elsewhere on the board
/Ethernet/ETH_RXD3: R67.2, U20.18 (RXD3/AN1); also elsewhere on the board
/Ethernet/ETH_TXCLK: U20.22 (TXC); also elsewhere on the board
/Ethernet/ETH_TXCTL: U20.27 (TXCTL); also elsewhere on the board
/Ethernet/ETH_TXD0: U20.23 (TXD0); also elsewhere on the board
/Ethernet/ETH_TXD1: U20.24 (TXD1); also elsewhere on the board
/Ethernet/ETH_TXD2: U20.25 (TXD2); also elsewhere on the board
/Ethernet/ETH_TXD3: U20.26 (TXD3); also elsewhere on the board
/Ethernet/ETH_VCC1V0: C223.1, C226.1, C229.1, C232.1, C233.1, C234.1, L1.2, U20.3 (AVDD10), U20.9 (AVDD10), U20.28 (DVDD10), U20.36 (DVDD10), U20.40 (AVDD10)
/Ethernet/ETH_VCC3V3: C214.1, C219.1, C220.1, C225.1, C228.1, C231.1, L7.2, R49.1, R50.1, R65.1, R66.1, R67.1, U20.15 (DVDD33), U20.21 (DVDD33), U20.37 (DVDD33)
/Ethernet/LED0: J6.12 (LED-), R70.2
/Ethernet/LED1: J6.13 (LED+), R73.2
/Ethernet/MAC_SCL: U23.6 (SCL); also elsewhere on the board
/Ethernet/MAC_SDA: U23.5 (SDA); also elsewhere on the board
/Ethernet/VCC1V0: C204.1, C212.1, L1.1, R38.2, U19.4 (VOUT)
/Ethernet/XTAL1_50MHZ: C238.1, U20.42 (CKXTAL1), X2.2
/Ethernet/XTAL2_50MHZ: C235.1, U20.43 (CKXTAL2), X2.1
GND: C203.2, C204.2, C210.2, C211.2, C212.2, C214.2, C216.1, C217.2, C218.2, C219.2, C220.2, C222.2, C223.2, C224.2, C225.2, C226.2, C227.2, C228.2, C229.2, C230.2, C231.2, C232.2, C233.2, C234.2, C235.2, C238.2, C239.2, J6.0 (S1), J6.10 (GND), K1.3, R39.1, R48.1, R69.2, R74.2, R89.2, U19.3 (GND), U19.6, U20.38 (ENSWREG), U20.47 (GND), U20.P (GND), U23.1 (A0), U23.2 (A1), U23.4 (GND), U23.7 (WP); also elsewhere on the board
unnamed: R73.1, R74.1, U20.35 (LED1/PHY_AD1)
unnamed: R70.1, R71.1, U20.34 (LED0/PHY_AD0)
unnamed: J6.7, U20.10 (MDI[3]+)
unnamed: R75.1, U20.32 (LED2/RXDLY)
unnamed: J6.6, U20.5 (MDI[1]-)
unnamed: J6.5, U20.8 (MDI[2]-)
unnamed: J6.4, U20.7 (MDI[2]+)
unnamed: J6.3, U20.4 (MDI[1]+)
unnamed: R69.1, U20.39 (RSET)
unnamed: J6.8, U20.11 (MDI[3]-)
unnamed: R22.1, U19.1 (~SHDN)
unnamed: R38.1, R39.2, U19.5 (VADJ)
unnamed: J6.14 (LED-), R89.1
unnamed: J6.11 (LED+), R92.1
unnamed: J6.1, U20.1 (MDI[0]+)
unnamed: J6.2, U20.2 (MDI[0]-)
unnamed: K1.2 (PM), U23.3 (A2)
VCC3V3: C203.1, C210.1, C211.1, C217.1, C218.1, C239.1, K1.1, L6.1, L7.1, R22.2, R51.2, R71.2, R75.2, R92.2, U19.2 (VIN), U23.8 (VCC); also elsewhere on the board

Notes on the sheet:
VCC1V0
JUSBPROM

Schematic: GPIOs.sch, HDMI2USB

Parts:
U25: TIMVIDEOS-PCIE-8X

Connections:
/FPGA_Bank_0_3/DIFFCLK_A0N: U25.A30 (DIFF_CLK_A0N); also elsewhere on the board
/FPGA_Bank_0_3/DIFFCLK_A0P: U25.A29 (DIFF_CLK_A0P); also elsewhere on the board
/FPGA_Bank_0_3/DIFFCLK_A1N: U25.A48 (DIFF_CLK_A1N); also elsewhere on the board
/FPGA_Bank_0_3/DIFFCLK_A1P: U25.A47 (DIFF_CLK_A1P); also elsewhere on the board
/FPGA_Bank_0_3/DIFFCLK_B0N: U25.B28 (DIFF_CLK_B0N); also elsewhere on the board
/FPGA_Bank_0_3/DIFFCLK_B0P: U25.B27 (DIFF_CLK_B0P); also elsewhere on the board
/FPGA_Bank_0_3/DIFFCLK_B1N: U25.B46 (DIFF_CLK_B1N); also elsewhere on the board
/FPGA_Bank_0_3/DIFFCLK_B1P: U25.B45 (DIFF_CLK_B1P); also elsewhere on the board
/FPGA_Bank_0_3/DIFFCLK_XN: U25.A14 (DIFF_CLK_XN); also elsewhere on the board
/FPGA_Bank_0_3/DIFFCLK_XP: U25.A13 (DIFF_CLK_XP); also elsewhere on the board
/FPGA_Bank_0_3/DIFFIO_A0N: U25.A6 (DIFF_IO_A0N); also elsewhere on the board
/FPGA_Bank_0_3/DIFFIO_A0P: U25.A5 (DIFF_IO_A0P); also elsewhere on the board
/FPGA_Bank_0_3/DIFFIO_A1N: U25.A17 (DIFF_IO_A1N); also elsewhere on the board
/FPGA_Bank_0_3/DIFFIO_A1P: U25.A16 (DIFF_IO_A1P); also elsewhere on the board
/FPGA_Bank_0_3/DIFFIO_A2N: U25.A22 (DIFF_IO_A2N); also elsewhere on the board
/FPGA_Bank_0_3/DIFFIO_A2P: U25.A21 (DIFF_IO_A2P); also elsewhere on the board
/FPGA_Bank_0_3/DIFFIO_A3N: U25.A26 (DIFF_IO_A3N); also elsewhere on the board
/FPGA_Bank_0_3/DIFFIO_A3P: U25.A25 (DIFF_IO_A3P); also elsewhere on the board
/FPGA_Bank_0_3/DIFFIO_A4N: U25.A36 (DIFF_IO_A4N); also elsewhere on the board
/FPGA_Bank_0_3/DIFFIO_A4P: U25.A35 (DIFF_IO_A4P); also elsewhere on the board
/FPGA_Bank_0_3/DIFFIO_A5N: U25.A40 (DIFF_IO_A5N); also elsewhere on the board
/FPGA_Bank_0_3/DIFFIO_A5P: U25.A39 (DIFF_IO_A5P); also elsewhere on the board
/FPGA_Bank_0_3/DIFFIO_A6N: U25.A44 (DIFF_IO_A6N); also elsewhere on the board
/FPGA_Bank_0_3/DIFFIO_A6P: U25.A43 (DIFF_IO_A6P); also elsewhere on the board
/FPGA_Bank_0_3/DIFFIO_B0N: U25.A8 (DIFF_IO_B0N); also elsewhere on the board
/FPGA_Bank_0_3/DIFFIO_B0P: U25.A7 (DIFF_IO_B0P); also elsewhere on the board
/FPGA_Bank_0_3/DIFFIO_B1N: U25.B15 (DIFF_IO_B1N); also elsewhere on the board
/FPGA_Bank_0_3/DIFFIO_B1P: U25.B14 (DIFF_IO_B1P); also elsewhere on the board
/FPGA_Bank_0_3/DIFFIO_B2N: U25.B20 (DIFF_IO_B2N); also elsewhere on the board
/FPGA_Bank_0_3/DIFFIO_B2P: U25.B19 (DIFF_IO_B2P); also elsewhere on the board
/FPGA_Bank_0_3/DIFFIO_B3N: U25.B24 (DIFF_IO_B3N); also elsewhere on the board
/FPGA_Bank_0_3/DIFFIO_B3P: U25.B23 (DIFF_IO_B3P); also elsewhere on the board
/FPGA_Bank_0_3/DIFFIO_B4N: U25.B34 (DIFF_IO_B4N); also elsewhere on the board
/FPGA_Bank_0_3/DIFFIO_B4P: U25.B33 (DIFF_IO_B4P); also elsewhere on the board
/FPGA_Bank_0_3/DIFFIO_B5N: U25.B38 (DIFF_IO_B5N); also elsewhere on the board
/FPGA_Bank_0_3/DIFFIO_B5P: U25.B37 (DIFF_IO_B5P); also elsewhere on the board
/FPGA_Bank_0_3/DIFFIO_B6N: U25.B42 (DIFF_IO_B6N); also elsewhere on the board
/FPGA_Bank_0_3/DIFFIO_B6P: U25.B41 (DIFF_IO_B6P); also elsewhere on the board
/FPGA_Bank_0_3/DIFFIO_XN: U25.B11 (DIFF_IO_XN); also elsewhere on the board
/FPGA_Bank_0_3/DIFFIO_XP: U25.B9 (DIFF_IO_XP); also elsewhere on the board
/FPGA_Bank_0_3/DIFFIO_YN: U25.B12 (DIFF_IO_YN); also elsewhere on the board
/FPGA_Bank_0_3/DIFFIO_YP: U25.A19 (DIFF_IO_YP); also elsewhere on the board
/FPGA_Bank_0_3/DIFFIO_ZN: U25.B30 (DIFF_IO_ZN); also elsewhere on the board
/FPGA_Bank_0_3/DIFFIO_ZP: U25.A32 (DIFF_IO_ZP); also elsewhere on the board
/FPGA_Bank_0_3/PCIE_RESET: U25.A11 (~RST); also elsewhere on the board
/FPGA_Bank_1_2/SMCLK: U25.B5 (IDCLK); also elsewhere on the board
/FPGA_Bank_1_2/SMDATA: U25.B6 (IDDAT); also elsewhere on the board
/GPIOs/PRSNT: U25.A1 (~PRSNT1), U25.B17 (~PRSNT2), U25.B31 (~PRSNT2), U25.B48 (~PRSNT2)
GND: U25.A4 (GND), U25.A12 (GND), U25.A15 (GND), U25.A18 (GND), U25.A20 (GND), U25.A23 (GND), U25.A24 (GND), U25.A27 (GND), U25.A28 (GND), U25.A31 (GND), U25.A34 (GND), U25.A37 (GND), U25.A38 (GND), U25.A41 (GND), U25.A42 (GND), U25.A45 (GND), U25.A46 (GND), U25.A49 (GND), U25.B4 (GND), U25.B7 (GND), U25.B13 (GND), U25.B16 (GND), U25.B18 (GND), U25.B21 (GND), U25.B22 (GND), U25.B25 (GND), U25.B26 (GND), U25.B29 (GND), U25.B32 (GND), U25.B35 (GND), U25.B36 (GND), U25.B39 (GND), U25.B40 (GND), U25.B43 (GND), U25.B44 (GND), U25.B47 (GND), U25.B49 (GND); also elsewhere on the board
VCC3V3: U25.A9 (3V3), U25.A10 (3V3), U25.B8 (3V3), U25.B10 (3V3); also elsewhere on the board
VCC12V0: U25.A2 (12V), U25.A3 (12V), U25.B1 (12V), U25.B2 (12V), U25.B3 (12V); also elsewhere on the board

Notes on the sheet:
PCIe

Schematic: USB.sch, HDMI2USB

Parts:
C34, C35, C37, C38, C39, C40, C41, C42, C240: 0.1uFD
C43, C44, C52, C53, C54, C58, C66, C201, C202: 0.1MFD
C62, C64: 12pF
D2: LED
GS2: GS2
J1, J7: USB_MICRO_B
P11, P12, P13: CONN_1
P16, P17: CONN_5
P18: CONN_2
R13: 8.06K
R14, R23, R24, R26: 100R
R15, R27, R28: 330R
R30: 20K5%- 0.05W
R31: 1.5K
R32, R35, R36: 10K
R33, R34: 2.2K
R37: 4.7K
U2: CY7C68013A_100AC
U18: USB3340
U24: BDXXGA5WEFJ_
X1: CRYSTAL

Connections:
/Ethernet/MAC_SCL: R34.1, U2.29 (SCL); also elsewhere on the board
/Ethernet/MAC_SDA: P18.2 (PM); also elsewhere on the board
/FPGA_Bank_1_2/CY-IFCLK: U2.26 (*IFCLK); also elsewhere on the board
/FPGA_Bank_1_2/CYPRESS-RESET: U2.77 (RESET#); also elsewhere on the board
/FPGA_Bank_1_2/CY_CTL0: U2.54 (CTL0/FLAGA); also elsewhere on the board
/FPGA_Bank_1_2/CY_CTL1: U2.55 (CTL1/FLAGB); also elsewhere on the board
/FPGA_Bank_1_2/CY_CTL2: U2.56 (CTL2/FLAGC); also elsewhere on the board
/FPGA_Bank_1_2/CY_CTL3: U2.51 (CTL3); also elsewhere on the board
/FPGA_Bank_1_2/CY_CTL4: U2.52 (CTL4); also elsewhere on the board
/FPGA_Bank_1_2/CY_CTL5: U2.76 (CTL5); also elsewhere on the board
/FPGA_Bank_1_2/CY_FD0: U2.34 (PB0/FD0); also elsewhere on the board
/FPGA_Bank_1_2/CY_FD1: U2.35 (PB1/FD1); also elsewhere on the board
/FPGA_Bank_1_2/CY_FD2: U2.36 (PB2/FD2); also elsewhere on the board
/FPGA_Bank_1_2/CY_FD3: U2.37 (PB3/FD3); also elsewhere on the board
/FPGA_Bank_1_2/CY_FD4: U2.44 (PB4/FD4); also elsewhere on the board
/FPGA_Bank_1_2/CY_FD5: U2.45 (PB5/FD5); also elsewhere on the board
/FPGA_Bank_1_2/CY_FD6: U2.46 (PB6/FD6); also elsewhere on the board
/FPGA_Bank_1_2/CY_FD7: U2.47 (PB7/FD7); also elsewhere on the board
/FPGA_Bank_1_2/CY_FD8: U2.80 (PD0/FD8); also elsewhere on the board
/FPGA_Bank_1_2/CY_FD9: U2.81 (PD1/FD9); also elsewhere on the board
/FPGA_Bank_1_2/CY_FD10: U2.82 (PD2/FD10); also elsewhere on the board
/FPGA_Bank_1_2/CY_FD11: U2.83 (PD3/FD11); also elsewhere on the board
/FPGA_Bank_1_2/CY_FD12: U2.95 (PD4/FD12); also elsewhere on the board
/FPGA_Bank_1_2/CY_FD13: U2.96 (PD5/FD13); also elsewhere on the board
/FPGA_Bank_1_2/CY_FD14: U2.97 (PD6/FD14); also elsewhere on the board
/FPGA_Bank_1_2/CY_FD15: U2.98 (PD7/FD15); also elsewhere on the board
/FPGA_Bank_1_2/CY_INT5: U2.84 (INIT5#); also elsewhere on the board
/FPGA_Bank_1_2/CY_PA0: U2.67 (PA0/INT0#); also elsewhere on the board
/FPGA_Bank_1_2/CY_PA1: U2.68 (PA1/INT1#); also elsewhere on the board
/FPGA_Bank_1_2/CY_PA2: U2.69 (PA2/*SLOE); also elsewhere on the board
/FPGA_Bank_1_2/CY_PA3: U2.70 (PA3/*WU2); also elsewhere on the board
/FPGA_Bank_1_2/CY_PA4: U2.71 (PA4/FIFOADR0); also elsewhere on the board
/FPGA_Bank_1_2/CY_PA5: U2.72 (PA5/FIFOADR1); also elsewhere on the board
/FPGA_Bank_1_2/CY_PA6: U2.73 (PA6/*PKTEND); also elsewhere on the board
/FPGA_Bank_1_2/CY_PA7: U2.74 (PA7/*FLAGD/SLCS#); also elsewhere on the board
/FPGA_Bank_1_2/CY_PC0: U2.57 (PC0/GPIFADR0); also elsewhere on the board
/FPGA_Bank_1_2/CY_PC1: U2.58 (PC1/GPIFADR1); also elsewhere on the board
/FPGA_Bank_1_2/CY_PC2: U2.59 (PC2/GPIFADR2); also elsewhere on the board
/FPGA_Bank_1_2/CY_PC3: U2.60 (PC3/GPIFADR3); also elsewhere on the board
/FPGA_Bank_1_2/CY_PC4: U2.61 (PC4/GPIFADR4); also elsewhere on the board
/FPGA_Bank_1_2/CY_PC5: U2.62 (PC5/GPIFADR5); also elsewhere on the board
/FPGA_Bank_1_2/CY_PC6: U2.63 (PC6/GPIFADR6); also elsewhere on the board
/FPGA_Bank_1_2/CY_PC7: U2.64 (PC7/GPIFADR7); also elsewhere on the board
/FPGA_Bank_1_2/CY_RD: U2.31 (RD#); also elsewhere on the board
/FPGA_Bank_1_2/CY_RD0: U2.3 (RDY0/SLRD); also elsewhere on the board
/FPGA_Bank_1_2/CY_RD1: U2.4 (RDY1/SLWR); also elsewhere on the board
/FPGA_Bank_1_2/CY_RD2: U2.5 (RDY2); also elsewhere on the board
/FPGA_Bank_1_2/CY_RD3: U2.6 (RDY3); also elsewhere on the board
/FPGA_Bank_1_2/CY_RD4: U2.7 (RDY4); also elsewhere on the board
/FPGA_Bank_1_2/CY_RD5: U2.8 (RDY5); also elsewhere on the board
/FPGA_Bank_1_2/CY_RXD0: U2.43 (RXD1); also elsewhere on the board
/FPGA_Bank_1_2/CY_RXD1: U2.41 (RXD0); also elsewhere on the board
/FPGA_Bank_1_2/CY_T0: U2.23 (T0); also elsewhere on the board
/FPGA_Bank_1_2/CY_TXD0: U2.42 (TXD1); also elsewhere on the board
/FPGA_Bank_1_2/CY_TXD1: U2.40 (TXD0); also elsewhere on the board
/FPGA_Bank_1_2/CY_WR: U2.32 (WR#); also elsewhere on the board
/FPGA_Bank_1_2/INIT_B: R27.2; also elsewhere on the board
/FPGA_Bank_1_2/USB_D0: U18.3 (DATA0); also elsewhere on the board
/FPGA_Bank_1_2/USB_D1: U18.4 (DATA1); also elsewhere on the board
/FPGA_Bank_1_2/USB_D2: U18.5 (DATA2); also elsewhere on the board
/FPGA_Bank_1_2/USB_D3: U18.6 (DATA3); also elsewhere on the board
/FPGA_Bank_1_2/USB_D4: U18.7 (DATA4); also elsewhere on the board
/FPGA_Bank_1_2/USB_D5: U18.9 (DATA5); also elsewhere on the board
/FPGA_Bank_1_2/USB_D6: U18.10 (DATA6); also elsewhere on the board
/FPGA_Bank_1_2/USB_D7: U18.13 (DATA7); also elsewhere on the board
/FPGA_Bank_1_2/USB_DIR: U18.31 (DIR); also elsewhere on the board
/FPGA_Bank_1_2/USB_NXT: U18.2 (NXT); also elsewhere on the board
/FPGA_Bank_1_2/USB_REFCLK: U18.26 (REFCLK); also elsewhere on the board
/FPGA_Bank_1_2/USB_RESETB: U18.27 (RESETB); also elsewhere on the board
/FPGA_Bank_1_2/USB_STP: U18.29 (STP); also elsewhere on the board
/FPGA_Power/DONE: R28.2; also elsewhere on the board
/FPGA_Power/PROG_B: R15.2; also elsewhere on the board
/FPGA_Power/TCK: R26.2; also elsewhere on the board
/FPGA_Power/TMS: R24.2; also elsewhere on the board
/SPI_Flash/TDO-FPGA/TDO-JTAG: R14.2; also elsewhere on the board
/SPI_Flash/TDO-USB/TDI-FPGA: R23.2; also elsewhere on the board
/USB/CPEN: U18.17 (CPEN), U24.5 (EN)
/USB/CYDN: J7.2 (D-), P17.2, U2.18 (DMINUS)
/USB/CYDP: J7.3 (D+), P17.3, U2.17 (DPLUS)
/USB/ID: J1.4 (NC), U18.23 (ID)
/USB/U1-SDA: P18.1, R33.1, U2.30 (SDA)
/USB/USB_5V: C240.1, J1.1 (+5V), P16.1, R30.2, U24.1 (VO), U24.2 (FB/VOS)
/USB/USB_DM: J1.2 (D-), P16.2, U18.19 (DM)
/USB/USB_DP: J1.3 (D+), P16.3, U18.18 (DP)
/USB/XTALIN: C62.2, U2.11 (XTALIN), X1.2
/USB/XTALIOUT: C64.1, U2.10 (XTALOUT), X1.1
GND: C34.2, C35.2, C37.1, C38.2, C39.2, C40.2, C41.2, C42.2, C43.2, C44.2, C52.2, C53.2, C54.2, C58.2, C62.1, C64.2, C66.2, C201.2, C202.2, C240.2, D2.2 (K), J1.5 (GND), J7.5 (GND), P16.4, P17.4, R13.1, R32.2, R36.1, R37.2, U2.2 (GND), U2.12 (AGND), U2.19 (AGND), U2.21 (GND), U2.39 (GND), U2.48 (GND), U2.50 (GND), U2.65 (GND), U2.75 (GND), U2.94 (GND), U2.99 (GND), U18.8 (REFSEL0), U18.11 (REFSEL1), U18.14 (REFSEL2), U18.33 (GND_PAD), U24.3 (GND), U24.9 (EP); also elsewhere on the board
unnamed: C34.1, C35.1, U18.28 (VDD1V8), U18.30 (VDD1V8)
unnamed: R13.2, U18.24 (RBIAS)
unnamed: C37.2, U18.20 (VDD3V3)
unnamed: R30.1, U18.22 (VBUS)
unnamed: R35.1, U2.79 (*WAKEUP)
unnamed: R24.1, U2.89 (PE3/RXD0OUT)
unnamed: R23.1, U2.88 (PE2/T2OUT)
unnamed: R15.1, U2.87 (PE1/T1OUT)
unnamed: R14.1, U2.86 (PE0/T0OUT)
unnamed: R28.1, U2.93 (PE7/GPIFADR8)
unnamed: R27.1, U2.92 (PE6/T2EX)
unnamed: R31.1, U2.91 (PE5/INT6)
unnamed: R26.1, U2.90 (PE4/RXD1OUT)
unnamed: R37.1, U2.27 (RESERVED)
unnamed: J7.1 (+5V), P17.1, R36.2
unnamed: GS2.1 (G1), R32.1, U2.22 (INIT4)
unnamed: D2.1 (A), R31.2
unnamed: P13.1, U2.28 (BKPT)
unnamed: P12.1, U2.25 (T2)
unnamed: P11.1, U2.24 (T1)
VCC3V3: C39.1, C40.1, C41.1, C42.1, C43.1, C44.1, C52.1, C53.1, C54.1, C58.1, C66.1, C201.1, C202.1, GS2.2 (G2), R33.2, R34.2, R35.2, U2.1 (VCC), U2.9 (AVCC), U2.16 (AVCC), U2.20 (VCC), U2.33 (VCC), U2.38 (VCC), U2.49 (VCC), U2.53 (VCC), U2.66 (VCC), U2.78 (VCC), U2.85 (VCC), U18.1 (CLKOUT), U18.21 (VBAT), U18.32 (VDDIO); also elsewhere on the board
VCC12V0: C38.1, U24.8 (VCC); also elsewhere on the board

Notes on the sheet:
RESET TIMING VALUES
Power-on Reset with crystal
Power-on Reset with external clock
Powered Reset
Condition
RESET
5 ms
200 ∝s + Clock stability time
200 ∝s
24MHz
USB 2.0 OTG Port (Host + Device Support) UTMI+/ULPI IC - Require full FPGA USB2.0 stack Microchip USB3440 FOSS Cores: * Daisho - http://goo.gl/eSwTeb * joris_vr - http://jorisvr.nl/usb/
USB 2.0 Device Port JTAG Programmer and "Easy" High Speed USB 2.0 Interface Cypress FX2 based
Cypress CY7C68013A Decoupling Capacitors
Cypress EEPROM disable

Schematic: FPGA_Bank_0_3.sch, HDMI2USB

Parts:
C113, C191, C192, C193, C194, C195, C196, C197, C198, C199, C200, C245, C246, C247, C248, C249, C250: 0.1UF
P15: CONN_5
R68: 50R
R85: 240E
R120: 4.7K
U10: XC6SLX45T
U27: FXO-LC73
U28, U29: SMA_CON

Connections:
/DDR3/DDR0_A0: U10.K2 (IO_L47P_M3A0_3); also elsewhere on the board
/DDR3/DDR0_A1: U10.K1 (IO_L47N_M3A1_3); also elsewhere on the board
/DDR3/DDR0_A2: U10.K5 (IO_L49N_M3A2_3); also elsewhere on the board
/DDR3/DDR0_A3: U10.M6 (IO_L45P_M3A3_3); also elsewhere on the board
/DDR3/DDR0_A4: U10.H3 (IO_L51N_M3A4_3); also elsewhere on the board
/DDR3/DDR0_A5: U10.M3 (IO_L44P_GCLK21_M3A5_3); also elsewhere on the board
/DDR3/DDR0_A6: U10.L4 (IO_L44N_GCLK20_M3A6_3); also elsewhere on the board
/DDR3/DDR0_A7: U10.K6 (IO_L49P_M3A7_3); also elsewhere on the board
/DDR3/DDR0_A8: U10.G3 (IO_L52P_M3A8_3); also elsewhere on the board
/DDR3/DDR0_A9: U10.G1 (IO_L52N_M3A9_3); also elsewhere on the board
/DDR3/DDR0_A10: U10.J4 (IO_L51P_M3A10_3); also elsewhere on the board
/DDR3/DDR0_A11: U10.E1 (IO_L54N_M3A11_3); also elsewhere on the board
/DDR3/DDR0_A12: U10.F1 (IO_L53N_M3A12_3); also elsewhere on the board
/DDR3/DDR0_A13: U10.J6 (IO_L55P_M3A13_3); also elsewhere on the board
/DDR3/DDR0_A14: U10.H5 (IO_L55N_M3A14_3); also elsewhere on the board
/DDR3/DDR0_BA0: U10.J3 (IO_L48P_M3BA0_3); also elsewhere on the board
/DDR3/DDR0_BA1: U10.J1 (IO_L48N_M3BA1_3); also elsewhere on the board
/DDR3/DDR0_BA2: U10.H1 (IO_L50N_M3BA2_3); also elsewhere on the board
/DDR3/DDR0_CAS_N: U10.M4 (IO_L43N_GCLK22_IRDY2_M3CASN_3); also elsewhere on the board
/DDR3/DDR0_CKE: U10.F2 (IO_L53P_M3CKE_3); also elsewhere on the board
/DDR3/DDR0_CK_N: U10.K3 (IO_L46N_M3CLKN_3); also elsewhere on the board
/DDR3/DDR0_CK_P: U10.K4 (IO_L46P_M3CLK_3); also elsewhere on the board
/DDR3/DDR0_DQ0: U10.R3 (IO_L37P_M3DQ0_3); also elsewhere on the board
/DDR3/DDR0_DQ1: U10.R1 (IO_L37N_M3DQ1_3); also elsewhere on the board
/DDR3/DDR0_DQ2: U10.P2 (IO_L38P_M3DQ2_3); also elsewhere on the board
/DDR3/DDR0_DQ3: U10.P1 (IO_L38N_M3DQ3_3); also elsewhere on the board
/DDR3/DDR0_DQ4: U10.L3 (IO_L41P_GCLK27_M3DQ4_3); also elsewhere on the board
/DDR3/DDR0_DQ5: U10.L1 (IO_L41N_GCLK26_M3DQ5_3); also elsewhere on the board
/DDR3/DDR0_DQ6: U10.M2 (IO_L40P_M3DQ6_3); also elsewhere on the board
/DDR3/DDR0_DQ7: U10.M1 (IO_L40N_M3DQ7_3); also elsewhere on the board
/DDR3/DDR0_DQ8: U10.T2 (IO_L36P_M3DQ8_3); also elsewhere on the board
/DDR3/DDR0_DQ9: U10.T1 (IO_L36N_M3DQ9_3); also elsewhere on the board
/DDR3/DDR0_DQ10: U10.U3 (IO_L35P_M3DQ10_3); also elsewhere on the board
/DDR3/DDR0_DQ11: U10.U1 (IO_L35N_M3DQ11_3); also elsewhere on the board
/DDR3/DDR0_DQ12: U10.W3 (IO_L33P_M3DQ12_3); also elsewhere on the board
/DDR3/DDR0_DQ13: U10.W1 (IO_L33N_M3DQ13_3); also elsewhere on the board
/DDR3/DDR0_DQ14: U10.Y2 (IO_L32P_M3DQ14_3); also elsewhere on the board
/DDR3/DDR0_DQ15: U10.Y1 (IO_L32N_M3DQ15_3); also elsewhere on the board
/DDR3/DDR0_LDM: U10.N4 (IO_L42N_GCLK24_M3LDM_3); also elsewhere on the board
/DDR3/DDR0_LDQS_N: U10.N1 (IO_L39N_M3LDQSN_3); also elsewhere on the board
/DDR3/DDR0_LDQS_P: U10.N3 (IO_L39P_M3LDQS_3); also elsewhere on the board
/DDR3/DDR0_ODT: U10.L6 (IO_L45N_M3ODT_3); also elsewhere on the board
/DDR3/DDR0_RAS_N: U10.M5 (IO_L43P_GCLK23_M3RASN_3); also elsewhere on the board
/DDR3/DDR0_RESET_N: U10.E3 (IO_L54P_M3RESET_3); also elsewhere on the board
/DDR3/DDR0_UDM: U10.P3 (IO_L42P_GCLK25_TRDY2_M3UDM_3); also elsewhere on the board
/DDR3/DDR0_UDQS_N: U10.V1 (IO_L34N_M3UDQSN_3); also elsewhere on the board
/DDR3/DDR0_UDQS_P: U10.V2 (IO_L34P_M3UDQS_3); also elsewhere on the board
/DDR3/DDR0_WE_N: U10.H2 (IO_L50P_M3WE_3); also elsewhere on the board
/DisplayPort/DPRX_LANEN0: U10.C7 (MGTRXN0_101); also elsewhere on the board
/DisplayPort/DPRX_LANEN1: U10.C9 (MGTRXN1_101); also elsewhere on the board
/DisplayPort/DPRX_LANEN2: U10.C13 (*MGTRXN0_123); also elsewhere on the board
/DisplayPort/DPRX_LANEN3: U10.C15 (*MGTRXN1_123); also elsewhere on the board
/DisplayPort/DPRX_LANEP0: U10.D7 (MGTRXP0_101); also elsewhere on the board
/DisplayPort/DPRX_LANEP1: U10.D9 (MGTRXP1_101); also elsewhere on the board
/DisplayPort/DPRX_LANEP2: U10.D13 (*MGTRXP0_123); also elsewhere on the board
/DisplayPort/DPRX_LANEP3: U10.D15 (*MGTRXP1_123); also elsewhere on the board
/DisplayPort/DPTX_LANEN0: U10.A6 (MGTTXN0_101); also elsewhere on the board
/DisplayPort/DPTX_LANEN1: U10.A8 (MGTTXN1_101); also elsewhere on the board
/DisplayPort/DPTX_LANEN2: U10.A14 (*MGTTXN0_123); also elsewhere on the board
/DisplayPort/DPTX_LANEN3: U10.A16 (*MGTTXN1_123); also elsewhere on the board
/DisplayPort/DPTX_LANEP0: U10.B6 (MGTTXP0_101); also elsewhere on the board
/DisplayPort/DPTX_LANEP1: U10.B8 (MGTTXP1_101); also elsewhere on the board
/DisplayPort/DPTX_LANEP2: U10.B14 (*MGTTXP0_123); also elsewhere on the board
/DisplayPort/DPTX_LANEP3: U10.B16 (*MGTTXP1_123); also elsewhere on the board
/Ethernet/MAC_SCL: U10.G6 (*IO_L82N_3); also elsewhere on the board
/Ethernet/MAC_SDA: U10.C1 (IO_L83P_3); also elsewhere on the board
/FPGA_Bank_0_3/DEBUG_IO0: P15.3, U10.AA2 (IO_L10P_3)
/FPGA_Bank_0_3/DEBUG_IO1: P15.4, U10.AA1 (IO_L10N_3)
/FPGA_Bank_0_3/DIFFCLK_A0N: U10.F15 (IO_L36N_GCLK14_0); also elsewhere on the board
/FPGA_Bank_0_3/DIFFCLK_A0P: U10.F14 (IO_L36P_GCLK15_0); also elsewhere on the board
/FPGA_Bank_0_3/DIFFCLK_A1N: U10.G9 (IO_L34P_GCLK19_0); also elsewhere on the board
/FPGA_Bank_0_3/DIFFCLK_A1P: U10.F10 (IO_L34N_GCLK18_0); also elsewhere on the board
/FPGA_Bank_0_3/DIFFCLK_B0N: U10.E16 (IO_L37P_GCLK13_0); also elsewhere on the board
/FPGA_Bank_0_3/DIFFCLK_B0P: U10.F16 (IO_L37N_GCLK12_0); also elsewhere on the board
/FPGA_Bank_0_3/DIFFCLK_B1N: U10.G11 (IO_L35N_GCLK16_0); also elsewhere on the board
/FPGA_Bank_0_3/DIFFCLK_B1P: U10.H12 (IO_L35P_GCLK17_0); also elsewhere on the board
/FPGA_Bank_0_3/DIFFCLK_XN: U10.D19 (IO_L62N_VREF_0); also elsewhere on the board
/FPGA_Bank_0_3/DIFFCLK_XP: U10.D18 (IO_L62P_0); also elsewhere on the board
/FPGA_Bank_0_3/DIFFIO_A0N: U10.C18 (IO_L66N_SCP0_0); also elsewhere on the board
/FPGA_Bank_0_3/DIFFIO_A0P: U10.D17 (IO_L66P_SCP1_0); also elsewhere on the board
/FPGA_Bank_0_3/DIFFIO_A1N: U10.A18 (IO_L63N_SCP6_0); also elsewhere on the board
/FPGA_Bank_0_3/DIFFIO_A1P: U10.B18 (IO_L63P_SCP7_0); also elsewhere on the board
/FPGA_Bank_0_3/DIFFIO_A2N: U10.G15 (IO_L49N_0); also elsewhere on the board
/FPGA_Bank_0_3/DIFFIO_A2P: U10.H14 (IO_L49P_0); also elsewhere on the board
/FPGA_Bank_0_3/DIFFIO_A3N: U10.G13 (IO_L38N_VREF_0); also elsewhere on the board
/FPGA_Bank_0_3/DIFFIO_A3P: U10.H13 (IO_L38P_0); also elsewhere on the board
/FPGA_Bank_0_3/DIFFIO_A4N: U10.E6 (IO_L4N_0); also elsewhere on the board
/FPGA_Bank_0_3/DIFFIO_A4P: U10.E5 (IO_L4P_0); also elsewhere on the board
/FPGA_Bank_0_3/DIFFIO_A5N: U10.A4 (IO_L6N_0); also elsewhere on the board
/FPGA_Bank_0_3/DIFFIO_A5P: U10.C4 (IO_L6P_0); also elsewhere on the board
/FPGA_Bank_0_3/DIFFIO_A6N: U10.A2 (IO_L3N_0); also elsewhere on the board
/FPGA_Bank_0_3/DIFFIO_A6P: U10.B2 (IO_L3P_0); also elsewhere on the board
/FPGA_Bank_0_3/DIFFIO_B0N: U10.A20 (IO_L65N_SCP2_0); also elsewhere on the board
/FPGA_Bank_0_3/DIFFIO_B0P: U10.B20 (IO_L65P_SCP3_0); also elsewhere on the board
/FPGA_Bank_0_3/DIFFIO_B1N: U10.F17 (IO_L51N_0); also elsewhere on the board
/FPGA_Bank_0_3/DIFFIO_B1P: U10.G16 (IO_L51P_0); also elsewhere on the board
/FPGA_Bank_0_3/DIFFIO_B2N: U10.A17 (IO_L50N_0); also elsewhere on the board
/FPGA_Bank_0_3/DIFFIO_B2P: U10.C17 (IO_L50P_0); also elsewhere on the board
/FPGA_Bank_0_3/DIFFIO_B3N: U10.H11 (IO_L33N_0); also elsewhere on the board
/FPGA_Bank_0_3/DIFFIO_B3P: U10.H10 (IO_L33P_0); also elsewhere on the board
/FPGA_Bank_0_3/DIFFIO_B4N: U10.D5 (IO_L2N_0); also elsewhere on the board
/FPGA_Bank_0_3/DIFFIO_B4P: U10.D4 (IO_L2P_0); also elsewhere on the board
/FPGA_Bank_0_3/DIFFIO_B5N: U10.A5 (IO_L8N_VREF_0); also elsewhere on the board
/FPGA_Bank_0_3/DIFFIO_B5P: U10.C5 (IO_L8P_0); also elsewhere on the board
/FPGA_Bank_0_3/DIFFIO_B6N: U10.A3 (IO_L5N_0); also elsewhere on the board
/FPGA_Bank_0_3/DIFFIO_B6P: U10.B3 (IO_L5P_0); also elsewhere on the board
/FPGA_Bank_0_3/DIFFIO_XN: U10.A19 (IO_L64N_SCP4_0); also elsewhere on the board
/FPGA_Bank_0_3/DIFFIO_XP: U10.C19 (IO_L64P_SCP5_0); also elsewhere on the board
/FPGA_Bank_0_3/DIFFIO_YN: U10.F8 (IO_L7N_0); also elsewhere on the board
/FPGA_Bank_0_3/DIFFIO_YP: U10.F7 (IO_L7P_0); also elsewhere on the board
/FPGA_Bank_0_3/DIFFIO_ZN: U10.F9 (IO_L32N_0); also elsewhere on the board
/FPGA_Bank_0_3/DIFFIO_ZP: U10.G8 (IO_L32P_0); also elsewhere on the board
/FPGA_Bank_0_3/HSWAP: U10.C3 (IO_L1P_HSWAPEN_0); also elsewhere on the board
/FPGA_Bank_0_3/MGT135MHz_N: C247.1, U10.F12 (*MGTREFCLK1N_123)
/FPGA_Bank_0_3/MGT135MHz_P: C248.1, U10.E12 (*MGTREFCLK1P_123)
/FPGA_Bank_0_3/MGTREFCLK0_101_N: C246.1; also elsewhere on the board
/FPGA_Bank_0_3/MGTREFCLK0_101_P: C245.1; also elsewhere on the board
/FPGA_Bank_0_3/MGTSMACLK_N: C250.1, U10.D11 (MGTREFCLK1N_101)
/FPGA_Bank_0_3/MGTSMACLK_P: C249.1, U10.C11 (MGTREFCLK1P_101)
/FPGA_Bank_0_3/PCIE_RESET: U10.D3 (IO_L1N_VREF_0); also elsewhere on the board
/FPGA_Bank_0_3/PCIO0: U10.G7 (*IO_L80N_3); also elsewhere on the board
/FPGA_Bank_0_3/PCIO1: U10.J7 (*IO_L81P_3); also elsewhere on the board
/FPGA_Bank_0_3/PCIO2: U10.H8 (*IO_L81N_3); also elsewhere on the board
/FPGA_Bank_0_3/PCIO3: U10.F5 (*IO_L82P_3); also elsewhere on the board
GND: C113.2, C191.2, C192.2, C193.2, C194.2, C195.2, C196.2, C197.2, C198.2, C199.2, C200.2, P15.5, R85.1, U27.3 (GND), U28.1, U29.1; also elsewhere on the board
unnamed: R85.2, U10.R7 (IO_L1P_3)
unnamed: C245.2, U10.A10 (MGTREFCLK0P_101)
unnamed: C250.2, U28.2
unnamed: C246.2, U10.B10 (MGTREFCLK0N_101)
unnamed: R120.1, U27.1 (E/D)
unnamed: C249.2, U29.2
unnamed: R68.2, U10.E9 (MGTRREF_101)
unnamed: C247.2, U27.5 (OUT_2#)
unnamed: C248.2, U27.4 (OUT)
VCC1V2: C191.1, C193.1, C194.1, C195.1, C196.1, C197.1, C198.1, C199.1, C200.1, P15.2, R68.1, U10.A7 (MGTAVTTTX_101), U10.A15 (MGTAVTTTX_123), U10.B9 (MGTAVCCPLL0_101), U10.B13 (*MGTAVCCPLL0_123), U10.C10 (MGTAVCC_101), U10.D8 (MGTAVTTRX_101), U10.D12 (MGTAVCCPLL1_101), U10.D14 (MGTAVTTRX_123), U10.E8 (MGTAVTTRCAL_101), U10.E10 (MGTAVCC_123), U10.E13 (*MGTAVCCPLL1_123); also elsewhere on the board
VCC3V3: P15.1, R120.2, U27.6 (VCC); also elsewhere on the board
VTTREF0: C113.1, C192.1, U10.B1 (IO_L83N_VREF_3), U10.K8 (*IO_L57N_VREF_3), U10.M8 (IO_L31N_VREF_3), U10.P8 (IO_L1N_VREF_3); also elsewhere on the board

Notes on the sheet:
BANK 3
BANK 0

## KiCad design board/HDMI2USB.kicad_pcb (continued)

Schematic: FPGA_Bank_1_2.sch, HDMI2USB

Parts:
R54: R
SW1: SW_PUSH
U10: XC6SLX45T

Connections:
/DisplayPort/DPRXAUXCH_N: U10.U10 (*IO_L46N_2); also elsewhere on the board
/DisplayPort/DPRXAUXCH_P: U10.T10 (*IO_L46P_2); also elsewhere on the board
/DisplayPort/DPRXCONFIG1: U10.AA8 (IO_L45P_2); also elsewhere on the board
/DisplayPort/DPRXCONFIG2: U10.AB8 (IO_L45N_2); also elsewhere on the board
/DisplayPort/DPTXAUXCH_N: U10.U15 (*IO_L23N_2); also elsewhere on the board
/DisplayPort/DPTXAUXCH_P: U10.T15 (*IO_L23P_2); also elsewhere on the board
/DisplayPort/DPTXCONFIG1: U10.R11 (*IO_L22P_2); also elsewhere on the board
/DisplayPort/DPTXCONFIG2: U10.T11 (*IO_L22N_2); also elsewhere on the board
/Ethernet/ETH_INT_B: U10.V9 (*IO_L50N_2); also elsewhere on the board
/Ethernet/ETH_MDC: U10.V7 (*IO_L58P_2); also elsewhere on the board
/Ethernet/ETH_MDIO: U10.T8 (*IO_L57P_2); also elsewhere on the board
/Ethernet/ETH_RESET_B: U10.U8 (*IO_L57N_2); also elsewhere on the board
/Ethernet/ETH_RXCLK: U10.AA12 (IO_L31P_GCLK31_D14_2); also elsewhere on the board
/Ethernet/ETH_RXCTL: U10.U9 (*IO_L50P_2); also elsewhere on the board
/Ethernet/ETH_RXD0: U10.R9 (*IO_L59P_2); also elsewhere on the board
/Ethernet/ETH_RXD1: U10.R8 (*IO_L59N_2); also elsewhere on the board
/Ethernet/ETH_RXD2: U10.W6 (*IO_L60P_2); also elsewhere on the board
/Ethernet/ETH_RXD3: U10.Y6 (*IO_L60N_2); also elsewhere on the board
/Ethernet/ETH_TXCLK: U10.AB12 (IO_L31N_GCLK30_D15_2); also elsewhere on the board
/Ethernet/ETH_TXCTL: U10.W8 (*IO_L58N_2); also elsewhere on the board
/Ethernet/ETH_TXD0: U10.W9 (IO_L48P_D7_2); also elsewhere on the board
/Ethernet/ETH_TXD1: U10.Y8 (IO_L48N_RDWR_B_VREF_2); also elsewhere on the board
/Ethernet/ETH_TXD2: U10.AA6 (IO_L49P_D3_2); also elsewhere on the board
/Ethernet/ETH_TXD3: U10.AB6 (IO_L49N_D4_2); also elsewhere on the board
/FPGA_Bank_0_3/MGTREFCLK0_101_N: U10.K22 (IO_L41N_GCLK8_M1CASN_1); also elsewhere on the board
/FPGA_Bank_0_3/MGTREFCLK0_101_P: U10.K21 (IO_L41P_GCLK9_IRDY1_M1RASN_1); also elsewhere on the board
/FPGA_Bank_1_2/CY-IFCLK: U10.P20 (IO_L42P_GCLK7_M1UDM_1); also elsewhere on the board
/FPGA_Bank_1_2/CYPRESS-RESET: U10.G22 (IO_L35N_A10_M1A2_1); also elsewhere on the board
/FPGA_Bank_1_2/CY_CTL0: U10.N16 (IO_L60P_1); also elsewhere on the board
/FPGA_Bank_1_2/CY_CTL1: U10.P16 (IO_L60N_1); also elsewhere on the board
/FPGA_Bank_1_2/CY_CTL2: U10.R15 (*IO_L70P_1); also elsewhere on the board
/FPGA_Bank_1_2/CY_CTL3: U10.M18 (IO_L61N_1); also elsewhere on the board
/FPGA_Bank_1_2/CY_CTL4: U10.M17 (IO_L61P_1); also elsewhere on the board
/FPGA_Bank_1_2/CY_CTL5: U10.R16 (*IO_L70N_1); also elsewhere on the board
/FPGA_Bank_1_2/CY_FD0: U10.C20 (IO_L20P_1); also elsewhere on the board
/FPGA_Bank_1_2/CY_FD1: U10.C22 (IO_L20N_1); also elsewhere on the board
/FPGA_Bank_1_2/CY_FD2: U10.L15 (*IO_L21P_1); also elsewhere on the board
/FPGA_Bank_1_2/CY_FD3: U10.K16 (*IO_L21N_1); also elsewhere on the board
/FPGA_Bank_1_2/CY_FD4: U10.D21 (*IO_L28P_1); also elsewhere on the board
/FPGA_Bank_1_2/CY_FD5: U10.D22 (*IO_L28N_VREF_1); also elsewhere on the board
/FPGA_Bank_1_2/CY_FD6: U10.G19 (IO_L29P_A23_M1A13_1); also elsewhere on the board
/FPGA_Bank_1_2/CY_FD7: U10.F20 (IO_L29N_A22_M1A14_1); also elsewhere on the board
/FPGA_Bank_1_2/CY_FD8: U10.H18 (IO_L30P_A21_M1RESET_1); also elsewhere on the board
/FPGA_Bank_1_2/CY_FD9: U10.H19 (IO_L30N_A20_M1A11_1); also elsewhere on the board
/FPGA_Bank_1_2/CY_FD10: U10.F21 (IO_L31P_A19_M1CKE_1); also elsewhere on the board
/FPGA_Bank_1_2/CY_FD11: U10.F22 (IO_L31N_A18_M1A12_1); also elsewhere on the board
/FPGA_Bank_1_2/CY_FD12: U10.E20 (IO_L32P_A17_M1A8_1); also elsewhere on the board
/FPGA_Bank_1_2/CY_FD13: U10.E22 (IO_L32N_A16_M1A9_1); also elsewhere on the board
/FPGA_Bank_1_2/CY_FD14: U10.J19 (IO_L33P_A15_M1A10_1); also elsewhere on the board
/FPGA_Bank_1_2/CY_FD15: U10.H20 (IO_L33N_A14_M1A4_1); also elsewhere on the board
/FPGA_Bank_1_2/CY_INT5: U10.T19 (*IO_L73P_1); also elsewhere on the board
/FPGA_Bank_1_2/CY_PA0: U10.F18 (IO_L1P_A25_1); also elsewhere on the board
/FPGA_Bank_1_2/CY_PA1: U10.F19 (IO_L1N_A24_VREF_1); also elsewhere on the board
/FPGA_Bank_1_2/CY_PA2: U10.H16 (*IO_L9P_1); also elsewhere on the board
/FPGA_Bank_1_2/CY_PA3: U10.H17 (*IO_L9N_1); also elsewhere on the board
/FPGA_Bank_1_2/CY_PA4: U10.B21 (*IO_L10P_1); also elsewhere on the board
/FPGA_Bank_1_2/CY_PA5: U10.B22 (*IO_L10N_1); also elsewhere on the board
/FPGA_Bank_1_2/CY_PA6: U10.J16 (IO_L19P_1); also elsewhere on the board
/FPGA_Bank_1_2/CY_PA7: U10.J17 (IO_L19N_1); also elsewhere on the board
/FPGA_Bank_1_2/CY_PC0: U10.U20 (IO_L49P_M1DQ10_1); also elsewhere on the board
/FPGA_Bank_1_2/CY_PC1: U10.U22 (IO_L49N_M1DQ11_1); also elsewhere on the board
/FPGA_Bank_1_2/CY_PC2: U10.V21 (IO_L50P_M1UDQS_1); also elsewhere on the board
/FPGA_Bank_1_2/CY_PC3: U10.V22 (IO_L50N_M1UDQSN_1); also elsewhere on the board
/FPGA_Bank_1_2/CY_PC4: U10.W20 (IO_L51P_M1DQ12_1); also elsewhere on the board
/FPGA_Bank_1_2/CY_PC5: U10.W22 (IO_L51N_M1DQ13_1); also elsewhere on the board
/FPGA_Bank_1_2/CY_PC6: U10.Y21 (IO_L52P_M1DQ14_1); also elsewhere on the board
/FPGA_Bank_1_2/CY_PC7: U10.Y22 (IO_L52N_M1DQ15_1); also elsewhere on the board
/FPGA_Bank_1_2/CY_RD: U10.K19 (IO_L34P_A13_M1WE_1); also elsewhere on the board
/FPGA_Bank_1_2/CY_RD0: U10.P19 (IO_L53P_1); also elsewhere on the board
/FPGA_Bank_1_2/CY_RD1: U10.R19 (IO_L53N_VREF_1); also elsewhere on the board
/FPGA_Bank_1_2/CY_RD2: U10.M16 (*IO_L58P_1); also elsewhere on the board
/FPGA_Bank_1_2/CY_RD3: U10.N15 (*IO_L58N_1); also elsewhere on the board
/FPGA_Bank_1_2/CY_RD4: U10.U19 (IO_L59P_1); also elsewhere on the board
/FPGA_Bank_1_2/CY_RD5: U10.T20 (IO_L59N_1); also elsewhere on the board
/FPGA_Bank_1_2/CY_RXD0: U10.P17 (*IO_L71P_1); also elsewhere on the board
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

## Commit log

2015-07-19 Issue#330 - Create initial repository for the HDMI2USB board.
2015-07-19 Starting again with different design and new name 'Opsis'.
    The Numato Opsis makes a number of different decisions to the first attempt at
    doing a HDMI2USB production board.
2015-07-19 Issue #1458 - Adding New schematics
    [Cypress.sch, DDR3.sch, Ethernet.sch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]
2015-07-19 Issue #1458 - HDMI RX TX pins added, Cypress added, DDR added
    [Cypress.sch, DDR3.sch, Ethernet.sch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]
2015-07-19 Issue #1458 - USB2.0
    [Cypress.sch, DDR3.sch, Ethernet.sch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]
2015-07-19 Issue #1470 - HDMI Sheet changes
    [DDR3.sch, DisplayPort.sch, Ethernet.sch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]
2015-07-19 Issue #1470 - Removing Cypress.sch
    [Cypress.sch]
2015-07-19 Issue #1471 - HDMI Sheet changes
    [DDR3.sch, DisplayPort.sch, Ethernet.sch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]
2015-07-19 Issue #1471 - usb Sheet changes
    [FPGA_Bank_0_3.sch, FPGA_Bank_1_2.sch, HDMI2USB.sch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]
2015-07-19 Issue #1471 - USB schematic changes
    [DDR3.sch, DisplayPort.sch, Ethernet.sch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]
2015-07-19 Issue #1471 - Changes in Cypress
    [DDR3.sch, DisplayPort.sch, Ethernet.sch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]
2015-07-19 Issue #1480
    [DDR3.sch, DisplayPort.sch, Ethernet.sch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]
2015-07-19 Issue #1546 - Adding an TimVideos PCIe 8x to Digilent Atlys VHDCI adapter.
    Also fixes Issue #1543.
    [Atlys-VHDCI.sch]
2015-07-19 Issue #1481 - DOC
    [DDR3.sch, DisplayPort.sch, Ethernet.sch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]
2015-07-19 Issue #1473 - Fixing UTMI schematic and adding text descriptions.
    [USB.sch]
2015-07-19 Issue #1583 - Copying hdmi2usb library into rev2 board.
2015-07-19 Issue #1481 - GPIO sheet
    [DDR3.sch, DisplayPort.sch, Ethernet.sch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]
2015-07-19 Issue #1481 - CYPRESS-FPGA CONNECTIONS ADDED
    [DDR3.sch, DisplayPort.sch, Ethernet.sch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]
2015-07-19 Issue #1481 - Placement
    [HDMI2USB.kicad_pcb]
2015-07-19 Issue #1412 - Placement
    [HDMI2USB.kicad_pcb]
2015-07-19 Issue #1608 - Placement
    [DDR3.sch, DisplayPort.sch, Ethernet.sch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]
2015-07-19 Issue #1412 - Placement on 6-3-15
    [DDR3.sch, DisplayPort.sch, Ethernet.sch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]
2015-07-19 Issue #1605 - Cypress routing
    [HDMI2USB.kicad_pcb]
2015-07-19 Issue #1605
    [DDR3.sch, DisplayPort.sch, Ethernet.sch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]
2015-07-19 Issue #1680 - Bank 0 Ios
    [DDR3.sch, DisplayPort.sch, Ethernet.sch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]
2015-07-19 Issue #1683
    [DDR3.sch, DisplayPort.sch, Ethernet.sch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]
2015-07-19 Issue #1670
    [DDR3.sch, DisplayPort.sch, Ethernet.sch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]
2015-07-19 Issue #1488 - Added diode display port power pin
    [DDR3.sch, DisplayPort.sch, Ethernet.sch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]
2015-07-19 Issue #1708 - Placement
    [HDMI2USB.kicad_pcb]
2015-07-19 Issue #1585
    [DDR3.sch, DisplayPort.sch, Ethernet.sch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]
2015-07-19 Issue #1647 - Final changes
    [DDR3.sch, DisplayPort.sch, Ethernet.sch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]
2015-07-19 Issue #1713
    [DDR3.sch, DisplayPort.sch, Ethernet.sch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]
2015-07-19 Issue #1546
    [DDR3.sch, DisplayPort.sch, Ethernet.sch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]
2015-07-19 Issue #1767 - Feedback changes
    [DDR3.sch, DisplayPort.sch, Ethernet.sch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]
2015-07-19 Issue #1786 - Final Changes
    [DDR3.sch, DisplayPort.sch, Ethernet.sch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]
2015-07-19 Issue #1601 - USB micro footprint
    [DDR3.sch, DisplayPort.sch, Ethernet.sch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]
2015-07-19 Issue #1799 - Feedback changes
    [DDR3.sch, DisplayPort.sch, Ethernet.sch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]
2015-07-19 Issue #1804 - Adding RX/TX direction fields.
    [DisplayPort.sch, HDMI.sch]
2015-07-19 Issue #1804 - Fixing RX/TX direction fields.
    [HDMI.sch]
2015-07-19 Issue #1849 - Gerber files
    [DisplayPort.sch, HDMI.sch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]
2015-07-19 Issue #1851 - UCF
    [HDMI2USB_UCF.ods]
2015-07-19 Issue #1961 - Adding initial "populate" field to all components.
    [DDR3.sch, DisplayPort.sch, Ethernet.sch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]
2015-07-19 Issue #1961 - Making the population instructions hidden.
    [DDR3.sch, DisplayPort.sch, Ethernet.sch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]
2015-07-19 Issue #1950 - Adding DisplayPort DC blocking capacitors to schematic.
    [DisplayPort.sch]
2015-07-19 Issue #1961 - Marking parts as "don't populate".
    * Conference power supply.
    * Debugging GTP clocks.
    [FPGA_Bank_0_3.sch, Power.sch]
2015-07-19 Adding information about the KiCad version used.
2015-07-19 Adding a picture of the board.
2015-07-23 Importing footprint names into schematic.
    [DDR3.sch, DisplayPort.sch, Ethernet.sch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]
2015-07-23 Fixing the power field.
    [USB.sch]
2015-08-25 Making the do-not-populate information clearer.
    [FPGA_Bank_0_3.sch, Power.sch]
2015-08-26 s/VTTREF0/VTTREF/
    https://github.com/timvideos/HDMI2USB-numato-opsis-hardware/issues/12
    [DDR3.sch, FPGA_Bank_0_3.sch]
2015-08-26 Adding test points to CEC and HPD lines.
    https://github.com/timvideos/HDMI2USB-numato-opsis-hardware/issues/17
    [HDMI.sch]
2015-08-26 Fixing up GND references in the HDMI sheet.
    https://github.com/timvideos/HDMI2USB-numato-opsis-hardware/issues/19
    [HDMI.sch]
2015-08-26 Fixing DRC errors.
    [HDMI.sch]
2015-08-26 Removing R151,R204
    https://github.com/timvideos/HDMI2USB-numato-opsis-hardware/issues/16
    [HDMI.sch]
2015-08-26 Fixing values of R141,R142,R197,R196
    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
    [HDMI.sch]
2015-08-26 Fixing the grouping of the HDMI signals.
    Fixes #22
    https://github.com/timvideos/HDMI2USB-numato-opsis-hardware/issues/22
    [HDMI2USB.sch]
2015-08-26 Fix the signal name changing.
    Fixes #23.
    https://github.com/timvideos/HDMI2USB-numato-opsis-hardware/issues/23
    [HDMI.sch, HDMI2USB.sch]
2015-08-26 Fixing the Cypress UART ordering.
    This shouldn't change anything in the PCB layout.
    Fixes #13
    https://github.com/timvideos/HDMI2USB-numato-opsis-hardware/issues/13
    [FPGA_Bank_1_2.sch, HDMI2USB.sch, USB.sch]
2015-08-26 KiCad is deciding to renumber the GND parts.
    [HDMI.sch]
2015-08-26 Adding silkscreen for debug IO header.
    Fixes #11.
    https://github.com/timvideos/HDMI2USB-numato-opsis-hardware/issues/11
2015-09-14 Issue #9
    Added DC blocking capacitors, VTTREF issue solved, 5V power common
    connection issue solved
    [DDR3.sch, DisplayPort.sch, Ethernet.sch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]
2015-10-20 Changes on 2015-10-21@7-21PM
    [DDR3.sch, DisplayPort.sch, Ethernet.sch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]
2015-11-02 Changes on 12-11-2015 Micro SD header added.#35
    [DDR3.sch, DisplayPort.sch, Ethernet.sch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]
2015-11-03 Adding extra mounting holes for Issue #18.
    Fixes #18.
2015-11-03 Added some more GND vias
2015-11-10 Final changes
    [DDR3.sch, DisplayPort.sch, Ethernet.sch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]
2015-11-10 Final Gerber
    [HDMI2USB-BOTTOM.gbl, HDMI2USB-B_Mask.gbs, HDMI2USB-B_SilkS.gbo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]
2016-01-04 Fixing issue with clock labeling.
    Fixes #42.
    [FPGA_Bank_1_2.sch, HDMI2USB.sch, SPI.sch]
2016-01-11 Improving the comments in the schematic.
    [DDR3.sch, DisplayPort.sch, Ethernet.sch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]
2016-01-11 Embedding the Git SHA into the schematic files.
    [DDR3.sch, DisplayPort.sch, Ethernet.sch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]
2016-01-11 Small formatting fixes.
    [DDR3.sch, DisplayPort.sch, Ethernet.sch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]
2016-01-11 Adding PDF version of the schematic.
2016-06-14 Added STL files for 'thin' shield
    [inset-thin-mouse-ears.stl, inset-thin.stl]
2016-07-25 Added STL files for full size ATX shield.
    [atx-mouse-ears.stl, atx.stl, inset-thin-mouse-ears.stl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]
2016-07-25 Adding standoff information.
2018-04-27 Link to current Opsis supplier page
